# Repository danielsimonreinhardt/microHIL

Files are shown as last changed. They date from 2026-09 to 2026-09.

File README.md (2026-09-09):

# microHIL

A small, self-built hardware-in-the-loop box: switchable relays, digital and
analog I/O, two current-monitored 12 V supply outputs and a CAN interface —
all driven from a PC over a single USB cable.

microHIL is built around an **STM32F446RET** (LQFP64) on a custom PCB. It
enumerates as a USB composite device with **two virtual COM ports**: one
carries a plain ASCII command protocol for the I/O, the other exposes CAN1 as
a standard SLCAN adapter. Both can be used at the same time.

> **Status:** working prototype, in active use on the bench. The firmware,
> the command protocol and the Python host library are stable and verified
> against real hardware; the PCB is at revision v0.1 and has a few documented
> quirks that needed rework (see [`docs/hardware-notes.md`](docs/hardware-notes.md)).
> Project documentation under `docs/` is currently in German.

## Features

| Function | Channels | Notes |
|---|---|---|
| Relays | 4 | dry contacts |
| Digital outputs | 8 | `OUT1-8` |
| Digital inputs | 8 | 12 V level, comparator front end with selectable 5 V/12 V threshold |
| Analog inputs | 4 | calibrated, reported in mV (divider for up to ~13 V) |
| Analog outputs | 2 | DAC + buffer, calibrated, ~0…12.2 V |
| Switchable 12 V outputs | 2 | high-side switch with current sense (mA) and firmware current limiting |
| PWM outputs | 4 | 0…1000 ‰, configurable frequency 1 Hz…20 kHz (`PWMFREQ`, shared by all 4 channels, ceiling scope-verified), shares the output stage with `OUT1-4` (interlocked in firmware) |
| CAN | 1 (+1 reserved) | CAN1 as SLCAN USB adapter; CAN2 reserved for remote control |

Analog channels (`AIN1-4`, `AOUT1-2`, `CURR1-2`) are individually two-point
calibrated against reference instruments, so the protocol speaks physical
units (mV / mA) rather than raw ADC counts — see
[`docs/calibration.md`](docs/calibration.md).

The 12 V outputs are protected in firmware: a per-channel limit (`ILIM`,
default 1200 mA) and a combined 1500 mA budget for the shared polyfuse. A
tripped channel latches off until its request is explicitly withdrawn;
`PWR12FLT?` reports the cause.

## Repository layout

```
firmware/microHIL_fw/   STM32CubeMX + CMake project for the STM32F446RET
host/                   Python client library, test GUI, hardware-free checks
hardware/               KiCad 9 schematic, PCB and Gerbers (rev v0.1)
docs/                   Protocol reference, CAN/SLCAN reference, calibration,
                        hardware notes (German)
```

## USB interfaces

microHIL presents two CDC-ACM functions under the same VID:PID `0483:5740`
(ST's factory VCP IDs — no own USB vendor ID). They are told apart by
interface number, which `host/microhil.py` does automatically:

| Interface | Windows | Linux | Content |
|---|---|---|---|
| 0 | `…&MI_00` | `…-if00` | HIL command protocol — [`docs/protocol.md`](docs/protocol.md) |
| 2 | `…&MI_02` | `…-if02` | CAN1 as SLCAN — [`docs/can-usb.md`](docs/can-usb.md) |

Two ports rather than one multiplexed port, because a COM port can only be
opened once on Windows: this way the test GUI and a CAN tool can run
side by side.

## Command protocol

Line-based ASCII, uppercase, `\n`-terminated requests, `\r\n`-terminated
replies — a plain `readline()` is enough. Values are always integers in
mV/mA.

```
*IDN?                 -> microHIL,fw=0.1.0,SN=2065386A5631
RELAY 1 1             -> OK
IN?                   -> 10110001        (IN1 first)
AIN? 2                -> 3300            (mV, calibrated)
PWR12 1 1             -> OK
CURR? 1               -> 536             (mA)
PWM 1 500             -> OK              (‰ duty cycle)
```

Errors are exactly `ERR ARGS`, `ERR RANGE` or `ERR UNKNOWN`. The full
reference, including the range-checking rules and the board serial number in
`*IDN?`, is in [`docs/protocol.md`](docs/protocol.md).

CAN1 speaks the SLCAN/Lawicel dialect (CAN232-compatible), so it works with
`python-can` (`interface="slcan"`) and, on Linux, as a regular SocketCAN
interface via `slcand`. Two extensions beyond CAN232: `B<bit/s>` for exact
non-standard bitrates and `Y` for a loopback self-test without a bus. See
[`docs/can-usb.md`](docs/can-usb.md).

## Getting started (host)

```bash
pip install -r host/requirements.txt
```

```python
from host.microhil import MicroHIL

with MicroHIL() as hil:          # finds the right COM port by itself
    print(hil.idn())
    hil.set_relay(1, True)
    print(hil.get_ain_mv(2), "mV")
    hil.set_pwr12(1, True)
    print(hil.get_curr_ma(1), "mA")
```

A PySide6 test GUI that exercises every function manually, with a CAN trace
tab, comes with it:

```bash
python host/gui.py
```

Two checks in `host/tests/` run without any hardware attached — they verify
the CAN bit timing against the bxCAN register limits and the SLCAN wire
format in both directions against the real `python-can` driver:

```bash
python host/tests/check_bit_timing.py
python host/tests/check_slcan_wire.py
```

## Building the firmware

Needs the `arm-none-eabi` GCC toolchain, CMake ≥ 3.22 and Ninja. The project
was generated with STM32CubeMX and is set up for the STM32Cube extension for
VS Code, but builds fine from the command line:

```bash
cd firmware/microHIL_fw
cmake --preset Debug
cmake --build --preset Debug
```

Flashing is over SWD with an ST-Link V2, e.g.:

```bash
STM32_Programmer_CLI -c port=SWD -w build/Debug/microHIL_fw.elf -rst
```

With GCC 10.3.1 (the version bundled with STM32CubeIDE 1.10.1, confirmed
working end-to-end 2026-09-09), the linker fails on all three `.ld` files
with `non constant or forward reference address expression for section
.ARM.extab` — the `(READONLY)` section attribute on `.ARM.extab`/`.ARM`/
`.preinit_array`/`.init_array`/`.fini_array` needs GCC 11+ (each occurrence
says so in its own comment). Remove `(READONLY)` from those five section
headers in `STM32F446xx_FLASH.ld` (used by the CMake build) and, for
STM32CubeIDE's own Eclipse build, `STM32F446RETX_FLASH.ld`/`_RAM.ld` too, if
building with GCC 10. A GCC 11+ toolchain doesn't need this.

If you regenerate from `microHIL_fw.ioc`, note that the CAN bit timing is
computed at runtime in `Core/Src/slcan.c` (deliberately not stored in CubeMX)
and that the CDC composite build needs ST's `CompositeBuilder`, which CubeMX
does not emit for the F4 series — it is vendored in
`Middlewares/ST/STM32_USB_Device_Library/Class/CompositeBuilder/`.

## Hardware

- MCU: STM32F446RET, LQFP64, 8 MHz crystal, HSE/PLL clock tree
- Debug: SWD (ST-Link V2)
- CAN1: PB8/PB9, transceiver and 120 Ω termination populated
- CAN2: PB5/PB6, not in service yet (see Roadmap)
- KiCad sources, PCB and Gerbers for rev v0.1 are in [`hardware/`](hardware/)

Board revision v0.1 has known issues that required rework — most notably VBUS
routed straight onto the supply rail, and missing pulldowns on the digital
input comparator stages. All of them are documented, with measurements and
the fixes applied, in [`docs/hardware-notes.md`](docs/hardware-notes.md).
Read that file before building a board from these files.

## Roadmap

- **CAN2 as a remote-control interface.** Drive microHIL from a supervising
  ECU or test bench with the same functions as the USB command protocol.
  Frame layout, addressing and bitrate are still to be defined; the bxCAN
  filter bank split needed for CAN2 to receive at all is already in place
  (`SlaveStartFilterBank = 14` in `Core/Src/can_if.c`).
- **CAN1 against a second real bus node**, plus a scope measurement of the
  actual bit rate.

## License

MIT — see [LICENSE](LICENSE).

Vendored third-party code keeps its own license: the STM32 HAL drivers, CMSIS
and the ST USB device library under `firmware/microHIL_fw/Drivers/` and
`firmware/microHIL_fw/Middlewares/` are © STMicroelectronics / Arm and
licensed under their respective terms (see the `LICENSE.txt` files in those
directories).

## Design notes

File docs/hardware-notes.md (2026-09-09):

# Hardware-Notizen

## Bekannte Probleme (aktuelle Platinen-Revision)

### VBUS direkt auf Versorgungsschiene (kein Regler dazwischen)

**Symptom:** Wenn Board gleichzeitig über ST-Link (3.3V) und über den
eigenen USB-Anschluss versorgt wird, steigt die gemessene VDD auf ca.
4.1V statt 3.3V. SWD-Zugriff (ST-Link) schlägt in diesem Zustand fehl
(`Unable to get core ID`).

**Ursache:** Der VBUS-Pin des USB-Steckers ist direkt mit der
Versorgungsschiene verbunden, statt über den Spannungsregler zu laufen.
Bei gleichzeitiger Fremdversorgung (z. B. durch ST-Link) kollidieren die
5V von VBUS mit der 3.3V-Versorgung auf derselben Schiene.

**Workaround (aktuell):** VBUS-Verbindung provisorisch aufgetrennt.

**Für nächste Revision:** VBUS über den Spannungsregler führen (bzw. nur
zur USB-VBUS-Erkennung an einen dedizierten, hochohmig entkoppelten Pin
legen), nicht direkt auf die Versorgungsschiene.

### Digital-Eingänge: Ursprüngliche "immer High"-Diagnose war falsch — Pullup ist Teil der Komparator-Stufe, nicht bloß Anti-Floating

**Ursprüngliches Symptom (2026-09-06):** Wenn an einem Digital-Eingang nichts
angeschlossen ist, wird er immer als High erkannt.

**Ursprüngliche (falsche) Diagnose:** Externer 10-kΩ-Pullup + LPF vor dem
GPIO-Pin, der einen internen STM32-Pulldown (~40 kΩ) überstimmt — wurde als
reines Anti-Floating-Problem am GPIO behandelt und der externe Pullup
entsprechend auf allen 8 Kanälen entfernt, dafür intern `GPIO_PULLDOWN`
aktiviert (`main.c`, `microHIL_fw.ioc`).

**Tatsächliche Schaltung (2026-09-08, per Schaltplan-Trace in
`ELECTRICS/micro_HIL_v0.1/Input-Driver.kicad_sch` verifiziert — Pfad siehe
[[microhil-kicad-schematic-path]]):** Jeder DIN-Kanal hat einen eigenen
Komparator (**LM397**, SOT-23-5, laut Bauteilbeschreibung explizit
"Voltage Comparator with **Open-Collector Output**"), keine simple
GPIO-Beschaltung:

```
INPUTn (12V) → Q3x (Verpolschutz, BSS84) → D1x/D2x (8,2V-Zener-Clamp, BZT52B8V2) → IN− (Pin1, LM397)
REF-Teiler (10k/15k, aus gemeinsamem REF-Netz)                                  → IN+ (Pin3, LM397)
                                                                                     │
                                                                            OUT (Pin4, Open-Collector)
                                                                                     │
                              10k-Pullup nach +3,3V ───────────────────────────────┤
                                                                                     │
                                                                        Testpoint → 3,3k Serie-R → DINn → MCU
```

Für alle 8 Kanäle nachgewiesen (Pin-4-Ausgang des jeweiligen LM397 liegt per
Wire-Trace direkt am zugehörigen 10-kΩ-Widerstand nach +3,3V): U21-U24/U25-U28
(Komparatoren) mit R95/R96/R97/R98 bzw. R115/R116/R117/R118 (Pullups, alle
10k) — genau diese acht Widerstände sind es, die der Fix vom 2026-09-08
entfernt hat.

**Root Cause (korrigiert):** Ein Open-Collector-Ausgang kann **nur** nach GND
ziehen (Transistor leitend) oder floaten (Transistor gesperrt) — er kann
niemals aktiv High treiben. Der "externe Pullup" war kein optionales
Anti-Floating-Element am GPIO, sondern die einzige Möglichkeit für diese
Stufe, überhaupt einen High-Pegel zu erzeugen. Ohne ihn zieht der interne
~40-kΩ-Pulldown den Pin permanent Richtung Low — unabhängig vom
Komparator-Zustand und unabhängig von der tatsächlichen Eingangsspannung.

**Damit erklärt sich auch das neue Symptom (2026-09-08, User-Beobachtung):**
Am MCU-Pin kommt nie ein High-Pegel an, obwohl sicher 12V an `INPUTn` anliegt
— exakt das erwartete Verhalten eines Open-Collector-Ausgangs ohne Pullup.

**Komparator-Polarität und zweiter Root Cause (geklärt, 2026-09-08, per
`kicad-cli sch export netlist` gegenverifiziert — manuelles
Koordinaten-Tracing im Schaltplan war an dieser Stelle zunächst fehlerhaft
und hat IN+/IN− vertauscht):**

```
Netz "Net-(D18-K)": D18 Pin1(K), Q32 Pin2, U21 Pin3  → INPUTn liegt an IN+ (nicht-invertierend)
Netz "Net-(U21--)": R87 Pin2, R88 Pin1, U21 Pin1     → REF-Teiler liegt an IN− (invertierend)
```

Damit ist die Schaltung ein **Standard-Komparator mit korrekter Polarität**:
Ausgang High (über den Open-Collector-Pullup), wenn `INPUTn` (IN+) über der
REF-Schwelle (IN−) liegt — also **High = 12V erkannt, Low = darunter**. Die
rohe, unveränderte GPIO-Ebene hatte diese Polarität schon immer korrekt; die
Firmware-Invertierung vom 08.09. (weiter oben) beruhte auf der fehlerhaften
Leitungsverfolgung und wurde noch am selben Tag zurückgenommen
(`Core/Src/protocol.c`, `cmd_in_query()` wieder reiner
`HAL_GPIO_ReadPin(...)`-Durchreich-Wert).

**Der tatsächliche zweite Fehler:** Am `IN+`-Netz hängt laut Netzliste
**kein einziger Widerstand nach GND** — nur D18 (Zener-Clamp), Q32
(Verpolschutz) und der Komparator-Eingang selbst. Ein unbeschalteter
`INPUTn` lässt IN+ dadurch komplett hochohmig floaten; es treibt
reproduzierbar über die REF-Schwelle (auch bei REF=12V, Schwelle ~7,2V) und
ist damit von echten 12V nicht zu unterscheiden — exakt das ursprüngliche
"immer High"-Symptom, nur jetzt mit echter Ursache statt der Pullup/Pulldown-
Fehldiagnose vom 06.09.

**Fix, auf Hardware verifiziert (2026-09-08):** Bodge-Pulldown-Widerstand von
IN+ (D18-Kathode-Knoten) nach GND, freitragend nachgerüstet auf Kanal 1 und
2. Test-Ergebnis nach dem Rework:

| Zustand | `IN? n` (Kanal 1+2) |
|---|---|
| offen | `0` |
| 12V | `1` |

Beide Zustände jetzt sauber unterscheidbar. `GPIO_PULLDOWN`→`GPIO_NOPULL`-
Rückstellung (Firmware/`.ioc`) ist bereits umgesetzt und mitgeflasht.

**Alle 8 Kanäle nachgerüstet und einzeln verifiziert (2026-09-08):** Bodge-
Pulldown IN+→GND auf Kanal 3-8 ergänzt (Kanal 1-2 s. o.). Danach jeden Kanal
einzeln mit 12V beschaltet (alle anderen offen) und `IN?` geprüft — kein
Kanal zeigt Überkopplung auf einen Nachbarn:

| Kanal | offen | 12V |
|---|---|---|
| IN1-IN8 | `0` | `1` |

Alle 8 Kanäle unterscheiden jetzt korrekt "offen" von "12V anliegend". Damit
ist der DIN-Fehlerkomplex (Pullup fehlte → Pulldown fehlte → Firmware-
Polarität kurzzeitig falsch invertiert) vollständig abgeschlossen.

**Zusatzverifikation der REF-Schwelle (2026-09-08, Kanal 1+2):** Mit 5V-Signal
an `INPUTn` sauber schwellenabhängig: REF=12V (Schwelle ~7,2V) → `0`
(5V < Schwelle), REF=5V (Schwelle ~3V) → `1` (5V > Schwelle). Bestätigt, dass
der Komparator nicht nur "12V vs. GND", sondern die tatsächliche Schwelle
korrekt auswertet.

### CAN1_RX (PB8) liegt offen — Bus kommt nicht hoch

**Symptom:** Der SLCAN-Layer selbst funktioniert (Protokoll-Parser, `V`/`N`/`F`
antworten korrekt), aber `O`, `L` und auch `Y` (Loopback-Selbsttest, kein Bus
nötig) scheitern alle mit `\a` (BEL). Per Debugger bestätigt: `HAL_CAN_Start()`
läuft in den 10-ms-Timeout (`HAL_CAN_ERROR_TIMEOUT`), weil `INAK` nie löscht —
der bxCAN-Kern wartet beim Verlassen des Init-Modus auf 11 aufeinanderfolgende
rezessive Bits auf der physischen RX-Leitung, **auch im Loopback-Modus**
(dieser Sync-Mechanismus hängt am echten Pin, nicht am internen
Loopback-Pfad — ein bekanntes bxCAN-Verhalten).

**Ursache (per Debugger verifiziert, nicht nur vermutet):** PB8 (CAN1_RX)
liest im Ruhezustand konstant LOW (dominant) statt HIGH (rezessiv). Test: mit
intern zugeschaltetem Pull-Up (`GPIOB->PUPDR`) springt der Pin sofort auf
HIGH, mit Pull-Down oder ganz ohne Pull bleibt er LOW — ein aktiv angesteuerter
Transceiver-Ausgang (Innenwiderstand ~10-100 Ω) würde einen schwachen internen
Pull (~40 kΩ) mühelos überstimmen. Der Pin ist also **nicht aktiv getrieben,
sondern floatet** — es zieht nichts Definiertes dagegen. `CAN1_SILENT` (PB7)
umzuschalten (LOW↔HIGH) hat dabei **keinerlei Auswirkung** auf PB8, was eine
einfache Polaritätsverwechslung beim Silent-Pin als Ursache ausschließt.

**Root Cause (gefunden):** Defekter CAN-Transceiver. Direktes Nachmessen am
RXD-Pin des Transceiver-ICs zeigte ca. 0,2 V statt der erwarteten ~5 V
(rezessiver Ruhepegel) — der Transceiver selbst hat die Leitung nicht
korrekt auf HIGH getrieben, unabhängig von MCU-Seite oder Verdrahtung.
Zwei Zwischenschritte haben das nicht behoben und sind damit als Ursache
ausgeschlossen: kalte Lötstellen (nachgelötet, kein Effekt) und
Silent-Pin-Polarität (siehe oben, PB7-Umschalten ohne Wirkung auf PB8).

**Fix:** Transceiver getauscht. Nach dem Tausch: `O`, `L` und `Y` öffnen
alle sauber (`OK`, keine Statusflags), Loopback-Frames (Standard, Extended,
beide RTR-Varianten, 1 Mbit/s) laufen fehlerfrei durch, Parallelbetrieb mit
dem HIL-Port über 5 Runden ohne Aussetzer. Damit ist CAN1 als CAN-USB-
Interface funktionsfähig.

**Noch offen:** Test gegen einen echten zweiten Busteilnehmer (bisher nur
Loopback/Selbsttest verifiziert) und Bitraten-Messung am Oszilloskop gegen
die berechneten Werte aus `docs/can-usb.md`.

### PWR12-1 liefert 0V trotz `PWR12 1 1` (Firmware meldet "ein")

**Symptom:** `PWR12 1 1` setzt den GPIO (PC4/`DOUT_12V_SUPPLY1`), `PWR12? 1`
liest korrekt "1" zurück (reine GPIO-Rücklesung, keine echte
Ausgangs-Rückmeldung) — am `12V_OUT_1`-Ausgang liegen aber trotz angeschlossener
externer 12V-Einspeisung ~0V an.

**Schaltung (`ELECTRICS/micro_HIL_v0.1`, Sheet `Output-Driver.kicad_sch`,
"12V SWITCHED SUPPLY 1"):** Externe 12V → **Q22** (PMT200EPEX, PMOS,
Verpolschutz) → Zwischenknoten → **Q28** (PMT200EPEX, PMOS, eigentlicher
Schalter) → **R73** (50 mΩ Shunt) → **F13** (Polyfuse, siehe Abschnitt
"Maximal zulässiger Strom" unten) → `12V_OUT_1`. Beide PMOS-Gates werden über
**Q26** (2N7002 NMOS) vom GPIO PC4 (`DOUT_12V_SUPPLY1`) gegen GND gezogen, um
sie durchzuschalten. PMT200EPEX-Gehäuse: **SOT223** (SC-73, 4-Pin mit
Kühlfläche), nicht SOT-23 wie zunächst notiert.

**Diagnose (2026-09-06, per Multimeter):**
- Zwischenknoten Q22/Q28: 0V, obwohl Pin2 (Drain) von Q22 die vollen 12V der
  Einspeisung führt — der Spannungsabfall passiert also bereits an Q22.
- Q22 einzeln gemessen: Pin1 (Gate) 0V, Pin2 (Drain) 12V, Pin3 (Source) 0V.
- Dioden-Test an Q22 (Drain-Source, Versorgung abgesteckt): 1,6V
  Durchlassspannung in einer Richtung, `OL` in der anderen.
- Vergleich mit baugleichen PMT200EPEX auf derselben Platine (z. B. Q28):
  dort nur ~0,568V Durchlassspannung, `OL` in Sperrrichtung — normales
  Verhalten einer intakten Body-Diode.

**Root Cause:** Q22 hat eine defekte Body-Diode (deutlich erhöhte
Durchlassspannung ggü. baugleichen, funktionierenden MOSFETs auf derselben
Platine) und blockiert dadurch den kompletten Strompfad, unabhängig von der
Gate-Ansteuerung über Q26/PC4. Vermutlich Vorschaden (Überstrom/ESD), keine
Fehlbestückung (Bauteil ist verlötet, sieht optisch unauffällig aus).

**PWR12-2 geprüft (2026-09-06):** liefert sauber 12V, Kanal 2 (Q23/Q29) ist
nicht betroffen — der Defekt ist auf Q22/Kanal 1 begrenzt.

**Fix (2026-09-08):** Q22 getauscht. Nach dem Tausch: unbelastet 12V (korrekt),
aber unter Last (0,3A) brach die Ausgangsspannung auf 8,5V ein (~3,3V Abfall
bei 0,3A ⇒ ~11Ω effektiver Serienwiderstand — bei intaktem PMOS+Shunt sollte
das nur ~60mV/~200mΩ sein). Bisektion ergab: am Zwischenknoten Q22/Q28 lagen
unter Last weiterhin 11,9V an (Q22 also gesund), der Abfall passierte also
zwischen dort und `12V_OUT_1` — **Q28 war ebenfalls defekt** (gleicher
Bauteiltyp/vermutlich gleiches Los wie Q22). Nach zusätzlichem Tausch von
Q28: unbelastet 12V, bei 0,3A Last nur noch 11,8V (~0,2V Abfall, normaler
Bereich). Beide MOSFETs (Q22 und Q28) mussten getauscht werden, nicht nur
Q22.

### CURR1/CURR2 liefern nicht-monotone/falsche Rohwerte bei realem Laststrom

**Symptom:** `CURRRAW? <1-2>` sollte laut Schaltungsauslegung ca. 1 mV
Rohwert pro 1 mA Laststrom liefern (INA240A1D, Gain 20 V/V, 50 mΩ Shunt
R73/R74, siehe `docs/calibration.md`). Gemessen an CURR2 (2026-09-06,
PWR12-2 bestätigt korrekt auf 12V, Laststrom mit Amperemeter in Reihe
verifiziert):

| Laststrom (Amperemeter) | `CURRRAW? 2` |
|---|---|
| 200 mA  | 181 |
| 1000 mA | 264 |
| 2000 mA | ~221 (220-224, stabil) |

Nicht nur stark nichtlinear (1000mA→264 vs. 2000mA→~221 wäre bei linearer
Kennlinie unmöglich), sondern **nicht-monoton**: der Rohwert bei 1A ist höher
als bei 2A.

**Schaltung:** `12V_OUT_<n>` → Shunt R73/R74 (50 mΩ) → **U18**/**U19**
(INA240A1D, SOIC-8, Gain 20 V/V, REF1/REF2 auf GND) → `AIN_12V_OUT<n>_CURR`
zum ADC.

**Root Cause (gefunden, 2026-09-06):** **U18 UND U19 sind beide nicht
bestückt** — per Sichtprüfung bestätigt, keine defekten Bauteile. Der
ADC-Eingang liegt dadurch unbeschaltet/floatend und pickt Störsignale auf,
die mit dem Laststrom der nahen Schaltung korrelieren, aber keinen echten
Zusammenhang mit dem tatsächlichen Strom haben — daher die willkürlichen,
nicht-monotonen Werte. Unvollständige Erstbestückung, kein Schaltungs- oder
Firmwarefehler.

**Fix (2026-09-08):** U18 und U19 bestückt. Unbelastet danach beide sauber
bei ~0 (CURR1: 4, CURR2: 0, stabil über mehrere Abfragen) statt der vorher
willkürlichen ~180-260er-Rohwerte. Unter realer Last ebenfalls plausibel
(z. B. CURR1 bei 300mA gemessenem Laststrom → Rohwert 301, siehe
`docs/calibration.md` für die vollständige Kalibrierung).

### Maximal zulässiger Dauerstrom PWR12/CURR (Sicherungen, nicht die MOSFETs)

Die im Schaltplan angegebene Vollausschlag-Formel für CURR
(`Vout = I·50mΩ·20 = 2,5V @ 2,5A`) beschreibt nur die Verstärker-Auslegung,
NICHT den durch die Hardware tatsächlich zulässigen Dauerstrom — der ist
niedriger:

- **F1** (`Input-Output.kicad_sch`, "12V EXTERNAL INPUT PROTECTION"): liegt
  VOR dem Kanal-Split auf dem gemeinsamen `+12V`-Netz, begrenzt also die
  **Summe aus PWR12-1 und PWR12-2 gemeinsam**.
- **F13**/**F14**: je Kanal, nach dem Shunt, kurz vor `12V_OUT_1`/`12V_OUT_2`.
- Alle drei vom Typ **MINISMDC150F/24-2** (Littelfuse PolySwitch PPTC):
  Ihold = 1,5A, Itrip = 3A @ 24V, Trip-Zeit bei 3A ≈ 1,5s.
- Die beiden PMOS je Kanal (PMT200EPEX, SOT223, Rds(on) 130-167mΩ,
  ID(cont)=2,4A@25°C) sind dabei NICHT die begrenzende Komponente: bei 1,5A
  Dauerstrom fallen pro MOSFET nur ca. 1,5²×0,167Ω ≈ 0,38W an, deutlich unter
  dem Ptot-Budget (800mW ohne, 1,75W mit Kupder-Kühlfläche).

**Praktische Grenze:** **≤ 1,5A pro Kanal, wenn nur ein Kanal aktiv ist**;
laufen **beide Kanäle gleichzeitig**, muss ihre **Summe** unter 1,5A bleiben
(F1). Für Kalibrier-/Testpunkte empfiehlt sich mit Sicherheitsmarge ≤ 1,2A,
um F13/F14 nicht unnötig zu erwärmen oder auszulösen (Datenblätter:
[Digi-Key](https://www.digikey.com/en/products/detail/littelfuse-inc/MINISMDC150F-24-2/1113513),
[PMT200EPE](https://assets.nexperia.com/documents/data-sheet/PMT200EPE.pdf)).

### Obere Grenzfrequenz PWM1-4 (Ausgangsstufe, nicht der Timer)

**Messung (2026-09-09):** PWM1 (PC6) mit 50% Duty Cycle am Oszilloskop bei
1 kHz, 20 kHz und 100 kHz beobachtet (Signal an der Ausgangsstufe, PUSH-PULL
OUTPUT DRIVER mit BC807/BC817, siehe `hardware/Output-Driver.kicad_sch`):

- **1 kHz:** Flanken praktisch senkrecht (vernachlässigbarer Anteil der
  1-ms-Periode).
- **20 kHz:** Flanken noch deutlich steiler als die 50-µs-Periode, sauber
  nutzbares Signal.
- **100 kHz:** Flanken nehmen einen spürbaren Anteil der 10-µs-Periode ein
  (sichtbar verschliffener Übergang statt scharfer Kante) — die Endstufe
  stößt hier an ihre Schaltgeschwindigkeit.

**Bei allen drei Frequenzen zusätzlich beobachtet:** Der High-Pegel ist
sichtbar schmaler als der Low-Pegel, obwohl `PWM?` intern korrekt ~500‰
zurückliefert — die Verzerrung entsteht also in der analogen Endstufe, nicht
in der Duty-Cycle-Berechnung der Firmware. Da die Asymmetrie **schon bei
1 kHz** in gleicher Stärke vorliegt, ist sie **nicht frequenzabhängig**,
sondern vermutlich eine systematische Eigenschaft der Push-Pull-Stufe
(unterschiedliche Ausschalt-/Speicherzeiten zwischen dem PNP BC807 und dem
NPN BC817). Nicht weiter untersucht — für den Anwendungsfall (Schalten,
keine analoge Signaltreue gefordert) nicht relevant, aber falls ein exaktes
Tastverhältnis gebraucht wird, im Hinterkopf behalten.

**Root Cause:** keine explizite Ursache ermittelt (kein Bauteildefekt, keine
Reparatur nötig) — es handelt sich um eine gemessene Charakteristik der
Endstufe, keinen Fehler.

**Konsequenz:** `PWMFREQ` in der Firmware (`Core/Src/protocol.c`) hart auf
`1..20000` Hz gekappt statt des zuvor generischen 1-MHz-Werts, siehe
`docs/protocol.md`, Abschnitt "PWM-Frequenz".

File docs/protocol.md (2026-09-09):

# microHIL-Kommandoprotokoll (USB-CDC)

ASCII-Zeilenprotokoll. **Anfragen** sind `\n`-terminiert (`\r\n` wird
ebenfalls akzeptiert), 115200 Baud (wird vom virtuellen COM-Port ignoriert,
aber pyserial verlangt einen Wert). **Antworten** enden immer mit `\r\n` —
auch `OK` und `ERR ...` — ein simples `readline()` reicht also zum Auslesen.
Werte sind immer Ganzzahlen in mV/mA, nie Fließkomma.

Kommandos sind **case-sensitiv, nur Großschreibung** (`RELAY`, nicht
`relay`), Verb und Argumente durch Leerzeichen oder Tab getrennt
(`strtok(line, " \t")` — mehrere Trenner hintereinander sind unproblematisch).
Eine **leere Zeile erzeugt keine Antwort** (weder `OK` noch `ERR`) — ein
Treiber, der eine Leerzeile schickt, würde sonst in den Timeout laufen statt
einen Fehler zu sehen.

**USB-Identifikation:** VID:PID `0483:5740` (ST-Werks-VCP-IDs, kein eigenes
USB-Zertifikat). microHIL meldet zwei virtuelle COM-Ports mit dieser
VID:PID. Dieses Protokoll liegt auf dem **ersten** (Interface 0, Windows
`MI_00`, Linux `-if00`); auf dem zweiten liegt CAN1 als SLCAN-Interface,
siehe [can-usb.md](can-usb.md). Den richtigen Port findet `host/microhil.py`
selbst (`find_port()`) — die Interface-Nummer ist bei zwei gleichzeitig
sichtbaren Ports mit identischer VID:PID das einzig verlässliche
Unterscheidungsmerkmal, siehe dort für die Details je Plattform.

| Befehl | Beispiel | Antwort |
|---|---|---|
| `*IDN?` | `*IDN?` | `microHIL,fw=0.1.0,SN=2065386A5631` |
| `RELAY <1-4> <0\|1>` | `RELAY 1 1` | `OK` |
| `RELAY? <1-4>` | `RELAY? 1` | `1` |
| `OUT <1-8> <0\|1>` | `OUT 3 0` | `OK` |
| `OUT? <1-8>` | `OUT? 3` | `0` |
| `IN? <1-8>` | `IN? 5` | `1` |
| `IN?` (ohne Nr.) | `IN?` | `10110001` (IN1 zuerst) |
| `AOUT <1-2> <mV>` | `AOUT 1 1650` | `OK` |
| `AOUTRAW <1-2> <mV>` | `AOUTRAW 1 1650` | `OK` |
| `AIN? <1-4>` | `AIN? 2` | `3300` |
| `AINRAW? <1-4>` | `AINRAW? 2` | `818` |
| `PWR12 <1-2> <0\|1>` | `PWR12 1 1` | `OK` |
| `PWR12? <1-2>` | `PWR12? 1` | `1` |
| `PWR12FLT? <1-2>` | `PWR12FLT? 1` | `1` |
| `ILIM <1-2> <mA>` | `ILIM 1 1000` | `OK` |
| `ILIM? <1-2>` | `ILIM? 1` | `1000` |
| `CURR? <1-2>` | `CURR? 1` | `536` |
| `CURRRAW? <1-2>` | `CURRRAW? 1` | `536` |
| `PWM <1-4> <0-1000>` | `PWM 1 500` | `OK` |
| `PWM? <1-4>` | `PWM? 1` | `500` |
| `PWMFREQ <Hz>` | `PWMFREQ 500` | `OK` |
| `PWMFREQ?` | `PWMFREQ?` | `500` |

`*IDN?`s `SN=`-Feld ist aus der 96-bit STM32-UID abgeleitet und identisch mit
der USB-Seriennummer (unter Windows als `SER=...` in der `hwid` sichtbar,
siehe `serial.tools.list_ports`) — eindeutig je physischem Board, geeignet um
ein bestimmtes Exemplar wiederzuerkennen (z. B. um bekannte Hardware-Defekte
je Board auszublenden, siehe `docs/hardware-notes.md`). `host/microhil.py`
stellt das über `MicroHIL.get_serial()` bereit.

`IN?`/`IN? <n>`: `1` bedeutet 12V liegen am Eingang an, `0` bedeutet kein
Signal/offen. Alle 8 Kanäle verhalten sich so — der Pulldown am
Komparator-Eingang, ohne den ein offener Eingang fälschlich `1` lieferte, ist
auf allen Kanälen nachgerüstet und einzeln verifiziert (siehe
`docs/hardware-notes.md`). Ausgewertet wird nicht 12V-vs-GND binär, sondern
die eingestellte REF-Schwelle (REF=12V: ca. 7,2V, REF=5V: ca. 3V).

`AIN?`/`CURR?` liefern kalibrierte physikalische Werte (mV bzw. mA), `AOUT`
nimmt die gewuenschte physikalische Ausgangsspannung entgegen - siehe
[calibration.md](calibration.md) für die Kalibrierkonstanten und die
Messprozedur. `AINRAW?`/`CURRRAW?`/`AOUTRAW` sprechen stattdessen direkt den
unkalibrierten ADC-/DAC-Wert an (raw*3300/4095 bzw. DAC-Sollwert 0..3300 mV,
ohne Anwendung der Kalibrierkonstanten) - fuer die Kalibrierprozedur selbst
und zu Diagnosezwecken, im Normalbetrieb nicht benoetigt.

`PWM`-Duty-Cycle in Promille (0 = aus, 1000 = 100%).

Bei ungültigen/unbekannten Kommandos: `ERR <Grund>`. Es gibt genau drei
Gründe, keine weiteren:

| Grund | Bedeutung |
|---|---|
| `ERR ARGS` | Argument fehlt (z. B. `RELAY 1` ohne Zustand) |
| `ERR RANGE` | **Kanal-/Indexargument** außerhalb des gültigen Bereichs (z. B. `RELAY 5 1`) |
| `ERR UNKNOWN` | Kommando-Verb nicht erkannt |

## Wertebereiche: Index vs. Nutzwert

Wichtige Asymmetrie, die sich nicht aus der Tabelle oben ableiten lässt:
**nur das Kanal-/Indexargument wird geprüft und liefert `ERR RANGE`.** Das
eigentliche Nutzwertargument (mV bei `AOUT`, Promille bei `PWM`) wird **ohne
Fehlermeldung auf den gültigen Bereich geklemmt**, nicht abgelehnt:

- `AOUT <1-2> <mV>`: mV ist die gewünschte physikalische Ausgangsspannung und
  wird auf den kalibrierten Ausgangsbereich geklemmt (nominal ca. `0..12210`
  mV, siehe `cal_aout` in `Core/Src/calibration.c` bzw.
  [calibration.md](calibration.md) — die genauen Grenzen ändern sich mit der
  Kalibrierung). `AOUT 1 99999` antwortet `OK`, setzt aber effektiv den
  Maximalwert — der Aufrufer erfährt aus der Antwort nicht, dass der Wert
  verändert wurde. `AOUTRAW <1-2> <mV>` (unkalibrierter DAC-Sollwert) klemmt
  stattdessen weiterhin auf `0..3300`.
- `PWM <1-4> <permille>`: Promille wird auf `0..1000` geklemmt. `PWM 1 -5`
  antwortet `OK` und setzt effektiv 0.
- `PWMFREQ <Hz>`: wird auf `1..20000` geklemmt. Kein Kanal-/Indexargument
  (gilt fuer alle 4 PWM-Kanaele gemeinsam, ein Timer), daher kann `PWMFREQ`
  nur `ERR ARGS` liefern, nie `ERR RANGE`.

Für einen Treiber heißt das: `OK` bei `AOUT`/`PWM` bestätigt nur, dass der
Kanalindex gültig war — **nicht**, dass der genaue angeforderte Wert übernommen
wurde. Wer das prüfen will, muss den Wert per `AOUT?`/`PWM?`
zurücklesen (Anmerkung: `AOUT?` existiert nicht, nur `PWM?`).

`RELAY`/`OUT`/`PWR12` erwarten `0`/`1`, akzeptieren aber jeden Ganzzahlwert
(`atoi`) — jeder Wert ungleich `0` wird als `1` (ein) gewertet, es gibt keine
eigene Prüfung auf exakt `0`/`1`.

## Verriegelung PWM1-4 / OUT1-4

PC6-PC9 (PWM1-4, TIM3) und OUT1-4 (PA10/PA15/PC10/PC11) treiben laut
Schaltplan dieselbe Endstufe und dürfen nie gleichzeitig aktiv sein.
Firmwareseitig erzwungen: `OUT <n> 1` (n=1-4) stoppt PWM-Kanal n zwangsweise
(Duty auf 0), `PWM <n> <permille>` mit `permille > 0` schaltet OUT n
zwangsweise ab. Es gibt dafür keine eigene Fehlermeldung — die Verriegelung
wirkt still, der jeweils andere Kanal wird einfach deaktiviert.

## PWM-Frequenz

`PWMFREQ`/`PWMFREQ?` gelten fuer PWM1-4 gemeinsam (ein Timer, TIM3, fuer alle
4 Kanaele - siehe `pwm_tim_channel` in `Core/Src/protocol.c`). Ein einzelner
Kanal kann also nicht auf eine andere Frequenz als die uebrigen drei gesetzt
werden.

Intern wird Prescaler+Autoreload so gewaehlt, dass ARR fuer PSC=0 maximiert
wird (mehr Aufloesung fuer den Duty Cycle); ein Prescaler kommt nur fuer sehr
niedrige Frequenzen zum Einsatz. `PWMFREQ?` liefert die durch die
Ganzzahl-Teiler tatsaechlich erreichte Frequenz zurueck (kann leicht vom
angeforderten Wert abweichen, analog zur Promille-Klemmung bei `PWM`).
Ein laufender Duty Cycle (`PWM <n> <permille>`) bleibt beim Frequenzwechsel
prozentual erhalten - die Firmware rechnet die 4 Compare-Register auf das
neue ARR um.

Die Obergrenze von `20000` Hz ist per Oszilloskop verifiziert (2026-09-09,
siehe `docs/hardware-notes.md`): bei 100 kHz zeigt die nachgeschaltete
Endstufe (PUSH-PULL OUTPUT DRIVER, BC807/BC817, siehe
`hardware/Output-Driver.kicad_sch`) bereits deutlich verschliffene Flanken
(spuerbarer Anteil der Periode), bei 20 kHz sind sie noch sauber. Die
Firmware kappt `PWMFREQ` entsprechend hart auf `20000`, nicht nur informativ
in der Doku.

Untergrenze `1` Hz ist ein praktischer Wert, nicht das Timer-Minimum: mit
maximalem 16-Bit-Prescaler und -ARR liegt die theoretisch niedrigste
TIM3-Frequenz bei ca. 0,0168 Hz (Periode ~59,7 s).

## Strombegrenzung PWR12-1/2

Firmwareseitige Schutzfunktion (`Core/Src/protocol.c`, `pwr12_guard_poll()`),
unabhängig von den Polyfuses F1/F13/F14 (siehe `docs/hardware-notes.md`,
"Maximal zulässiger Dauerstrom") — diese sind weiterhin die letzte
Hardware-Absicherung, die Firmware soll aber im Normalbetrieb schon vorher
abschalten.

**Pro Kanal:** `ILIM <1-2> <mA>` setzt das Stromlimit für PWR12-1/2, Default
nach Reset ist **1200 mA**. Wird das Limit **ununterbrochen länger als
100 ms** überschritten (CURR1/2 werden dafür intern alle 2 ms gesampelt),
schaltet die Firmware den betroffenen Kanal ab, unabhängig von der zuletzt
per `PWR12` gesetzten Schaltanforderung. Kurze Einschaltstromspitzen unter
100 ms lösen die Verriegelung nicht aus.

**Gesamtbudget:** Der 12V-Eingang versorgt neben PWR12-1/2 auch die MCU,
deshalb gibt es zusätzlich eine von den Einzellimits unabhängige Prüfung:
überschreitet CURR1+CURR2 in Summe **1500 mA** (Ihold der gemeinsamen
Polyfuse F1, siehe `docs/hardware-notes.md`), schaltet die Firmware **beide**
Kanäle ab — mit einer kurzen **10-ms-Entprellung** (viel kürzer als die
100 ms pro Kanal, aber nicht "sofort" ohne jede Filterung: eine erste
Implementierung ganz ohne Entprellung löste auf Hardware bereits beim
Einschalten eines einzelnen, unbelasteten Kanals aus — ein Schaltstörimpuls
traf die eine ungefilterte 2-ms-ADC-Probe, siehe `CHANGELOG.md`).

**Verriegelung:** In beiden Fällen bleibt der Ausgang aus, auch wenn die
Schaltanforderung (`PWR12 <n> 1`) weiter ansteht — ein einfaches erneutes
`PWR12 <n> 1` schaltet NICHT wieder ein. Der betroffene Kanal muss zuerst
per `PWR12 <n> 0` zurückgenommen werden (das löscht seine eigene
Überstromverriegelung); die Gesamtbudget-Verriegelung erlischt erst, wenn
**beide** Kanäle zurückgenommen wurden. `PWR12? <n>` liest weiterhin nur den
tatsächlichen GPIO-Zustand (0, solange eine Verriegelung aktiv ist);
`PWR12FLT? <n>` liefert eine Bitmaske, warum ein Kanal trotz anstehender
Schaltanforderung aus ist: Bit0 = eigenes Überstromlimit ausgelöst, Bit1 =
Gesamtbudget ausgelöst (`0` = kein Fault).

`ILIM` klemmt negative Werte auf 0, prüft aber sonst nicht gegen die
Hardwaregrenzen (≤1,5A Dauerstrom pro Kanal laut Sicherung) — wer ein
höheres Limit setzt, verlässt sich allein auf die Polyfuses.

## Timing

Alle Kommandos außer `AIN?` und `CURR?` antworten praktisch sofort
(reine GPIO-/Register-Operationen). `AIN?` und `CURR?` lösen intern eine
Single-Conversion-ADC-Messung aus (`HAL_ADC_PollForConversion`, 10 ms
Timeout) — im Normalfall deutlich schneller, aber ein Treiber, der viele
Analogkanäle im Poll-Takt abfragt, sollte pro Aufruf mit bis zu ~10 ms
rechnen statt mit der sonst üblichen Sub-Millisekunden-Antwortzeit.

## Kalibrierung

`AIN?`, `AOUT` und `CURR?` rechnen über feste 2-Punkt-Kalibrierkonstanten
(`Core/Src/calibration.c`) zwischen dem naiven ADC-/DAC-Wert und dem
physikalischen Wert um. Bis zur echten Messung stehen dort nominelle,
aus dem Schaltplan abgeleitete Platzhalterwerte — siehe
[calibration.md](calibration.md) für Herleitung und Messprozedur.

## Implementierung

- Firmware: `Core/Src/protocol.c` — Ringpuffer wird in `CDC_Receive_FS`
  (USB_DEVICE/App/usbd_cdc_if.c) gefüllt, `Protocol_Poll()` läuft in der
  Main-Loop und wertet vollständige Zeilen aus.
- Host: `host/microhil.py` (Klasse `MicroHIL`, pyserial-basiert)

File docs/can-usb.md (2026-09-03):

# CAN1 als CAN-USB-Interface (SLCAN)

CAN1 des microHIL ist ein CAN-USB-Adapter im SLCAN-/Lawicel-Format
(CAN232-kompatibel). Damit funktioniert es ohne eigenen Treiber mit
`python-can` unter Windows und unter Linux über `slcand` als reguläres
SocketCAN-Interface.

CAN2 ist für die spätere Fernsteuerung des microHIL reserviert und hier
nicht angesprochen (siehe Roadmap im README).

## Zwei COM-Ports

microHIL meldet sich als USB-Composite-Device mit **zwei** CDC-ACM-Funktionen,
also zwei virtuellen COM-Ports:

| Interface | Windows | Linux | Inhalt |
|---|---|---|---|
| 0 | `...&MI_00` | `...-if00` | HIL-Kommandoprotokoll (`docs/protocol.md`) |
| 2 | `...&MI_02` | `...-if02` | CAN1, SLCAN |

Beide Ports haben dieselbe VID:PID `0483:5740`. Der Composite-Builder der
ST-USB-Library vergibt für beide CDC-Funktionen den Interface-String-Index 0,
deshalb heißen im Windows-Gerätemanager beide Ports gleich — auseinanderhalten
lassen sie sich nur über die Interface-Nummer. `host/microhil.py` macht das
automatisch (`find_ports()`, `find_can_port()`).

Der Sinn der Trennung: ein COM-Port lässt sich unter Windows nur einmal öffnen.
Mit zwei Ports laufen Test-GUI und CAN-Werkzeug gleichzeitig.

## Kommandos

Kommandos sind mit **CR** (`\r`) terminiert, nicht mit `\n` wie beim
HIL-Protokoll. Antwort ist `\r` (OK) bzw. `\a` (BEL, Fehler).

| Befehl | Bedeutung | Antwort |
|---|---|---|
| `Sn` | Bitrate wählen, `n` = 0-9 (Tabelle unten) | `\r` |
| `B<bit/s>` | **microHIL-Erweiterung:** exakte Bitrate dezimal, z. B. `B750000` | `\r` |
| `O` | Bus öffnen, Normalbetrieb | `\r` |
| `L` | Bus öffnen, Listen-Only (sendet nichts, auch kein ACK) | `\r` |
| `Y` | **microHIL-Erweiterung:** Loopback-Selbsttest ohne Bus | `\r` |
| `C` | Bus schließen | `\r` |
| `tiiildd…` | Standard-Frame (11 bit) senden | `z\r` |
| `Tiiiiiiiildd…` | Extended-Frame (29 bit) senden | `Z\r` |
| `riiil` | Standard-RTR senden | `z\r` |
| `Riiiiiiiil` | Extended-RTR senden | `Z\r` |
| `F` | Statusflags lesen (das Lesen löscht sie) | `Fxx\r` |
| `V` | Version | `V0100\r` |
| `N` | Seriennummer (4 Hex aus der MCU-UID) | `Nxxxx\r` |
| `Zn` | Zeitstempel aus (`Z0`) / ein (`Z1`) | `\r` |

Empfangene Frames kommen unaufgefordert im selben `t`/`T`/`r`/`R`-Format.
Bei `Z1` hängen 4 Hex-Ziffern Millisekunden an (Überlauf bei 60000 = `EA5F`).

Die Bitrate lässt sich nur bei **geschlossenem** Bus setzen. `O`/`L`/`Y` sind
idempotent (schließen intern vorher) — `python-can` schickt beim Verbinden
zweimal `O`.

### Statusflags (`F`)

| Bit | Bedeutung |
|---|---|
| 0 | RX-Ringpuffer voll (Frames verworfen) |
| 1 | TX-Mailboxen voll (Frame verworfen) |
| 2 | Error Warning |
| 3 | Data Overrun |
| 5 | Error Passive |
| 6 | Arbitration Lost |
| 7 | Bus Error |

## Bitraten

`Sn` folgt dem originalen Lawicel-CAN232.

| Befehl | Bitrate | Prescaler | BS1 | BS2 | SJW | tq/Bit | Sample Point |
|---|---|---|---|---|---|---|---|
| `S0` | 10 kbit/s | 180 | 16 | 3 | 1 | 20 | 85,0 % |
| `S1` | 20 kbit/s | 90 | 16 | 3 | 1 | 20 | 85,0 % |
| `S2` | 50 kbit/s | 36 | 16 | 3 | 1 | 20 | 85,0 % |
| `S3` | 100 kbit/s | 18 | 16 | 3 | 1 | 20 | 85,0 % |
| `S4` | 125 kbit/s | 16 | 15 | 2 | 1 | 18 | 88,9 % |
| `S5` | 250 kbit/s | 8 | 15 | 2 | 1 | 18 | 88,9 % |
| `S6` | 500 kbit/s | 4 | 15 | 2 | 1 | 18 | 88,9 % |
| `S7` | **800 kbit/s** | 3 | 10 | 4 | 1 | 15 | 73,3 % |
| `S8` | 1 Mbit/s | 2 | 13 | 4 | 1 | 18 | 77,8 % |
| `S9` | 83,333 kbit/s | 24 | 15 | 2 | 1 | 18 | 88,9 % |

Alle Nennbitraten werden bei PCLK1 = 36 MHz exakt getroffen. Die Werte stehen
nicht als Tabelle in der Firmware, sondern werden von `timing_for_bitrate()`
in `Core/Src/slcan.c` gesucht: feinste Auflösung, deren Sample Point nahe genug
am Ziel liegt (87,5 %, ab 800 kbit/s 75 %), bei höchstens 0,1 % Bitratenfehler.
Grenzen der bxCAN-Register: BS1 ≤ 16 tq, BS2 ≤ 8 tq, Prescaler ≤ 1024.

### Stolperstein: `S7`

`python-can` bildet **750 kbit/s** auf `S7` ab, das originale Lawicel-CAN232
(und damit microHIL) versteht unter `S7` aber **800 kbit/s**. Wer 750 kbit/s
braucht, setzt sie über das `B`-Kommando:

```
C
B750000
O
```

`host/microhil_can.py` macht genau das automatisch für alle Bitraten außerhalb
der eindeutigen Menge.

## Benutzung

### Windows / Python

```python
from microhil_can import open_can
import can

with open_can(500000) as bus:
    bus.send(can.Message(arbitration_id=0x7DF, is_extended_id=False,
                         data=[0x02, 0x01, 0x00]))
    print(bus.recv(1.0))
```

Als Sniffer:

```
python host/microhil_can.py 500000
```

Oder direkt mit python-can, wenn der Port bekannt ist:

```python
bus = can.Bus(interface="slcan", channel="COM8", bitrate=500000)
```

In der Test-GUI (`host/gui.py`) gibt es dafür den Reiter **CAN1** mit
Bitratenwahl, Listen-Only, Trace und Sendefeld. HIL-Reiter und CAN-Reiter
benutzen die beiden getrennten COM-Ports und funktionieren gleichzeitig.

### Linux / Raspberry Pi (SocketCAN)

```
slcand -o -s6 -t hw -S 115200 /dev/ttyACM1 can0
ip link set can0 up
candump can0
```

`-s6` = 500 kbit/s (siehe Tabelle). `/dev/ttyACM1` ist der Port mit
Interface 2 — verlässlich über `/dev/serial/by-id/*-if02` ansprechen, weil
sich die `ttyACM`-Nummern beim Anstecken verschieben können.

Damit steht `can0` allen SocketCAN-Werkzeugen zur Verfügung, unter anderem
`can-utils` und `uds-diag` — dort ist keine Anpassung nötig.

## Hardware

- CAN1: PB8 = RX, PB9 = TX, Transceiver bestückt, 120 Ω auf der Platine.
- `CAN1_SILENT` (PB7) wird auf LOW gehalten (Normalbetrieb). Listen-Only wird
  über den Silent-Modus des bxCAN abgebildet, nicht über den Transceiver.

## Implementierung

- `Core/Src/can_if.c` — bxCAN-Treiber: Bit-Timing, Accept-all-Filter,
  Interrupt-RX in einen 64-Frame-Ring, Fehlerflags, automatische
  Bus-Off-Erholung. Die Filterbänke sind aufgeteilt
  (`SlaveStartFilterBank = 14`), damit CAN2 später empfangen kann.
- `Core/Src/slcan.c` — Protokoll-Parser und -Serializer, gepufferte Ausgabe.
- `USB_DEVICE/App/usbd_cdc_if.c` — zweite CDC-Instanz (`..._fops_CAN`).
- `host/microhil_can.py`, `host/microhil.py` (`find_can_port()`).

### Hinweis zu CubeMX

Das Composite-Device ist von Hand eingerichtet, CubeMX generiert es für die
F4-Serie nicht. Nach einem Regenerieren aus der `.ioc` sind zu prüfen:

- `USB_DEVICE/Target/usbd_conf.h`: `USBD_MAX_NUM_INTERFACES` muss `4U` sein
  (der Composite-Block selbst steht im `USER CODE`-Bereich und überlebt).
- `USB_DEVICE/Target/usbd_conf.c`: die FIFO-Aufteilung (fünf TX-FIFOs).
- `USB_DEVICE/App/usb_device.c`: die beiden `USBD_RegisterClassComposite()`.
- `USB_DEVICE/App/usbd_desc.c`: die Gerätestrings.

Das CAN-Bit-Timing ist bewusst **nicht** von CubeMX abhängig: `can_if.c`
konfiguriert `hcan1` vollständig selbst, die Werte in `MX_CAN1_Init()` sind
irrelevant. Ebenso liegen die CAN-IRQ-Handler in einem `USER CODE`-Block von
`stm32f4xx_it.c` statt im NVIC-Tab.

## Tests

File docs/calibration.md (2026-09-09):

# Kalibrierung: AIN, AOUT, CURR

`AIN?`, `AOUT` und `CURR?` liefern/erwarten physikalische Werte (mV bzw. mA),
keine rohen ADC-/DAC-Werte. Die Umrechnung passiert über eine stückweise
lineare Kalibrierung je Kanal in `Core/Src/calibration.c`
(`cal_ain[4]`, `cal_curr[2]`, `cal_aout[2]`). Jeder Eintrag ist eine
`cal_curve_t` aus N gemessenen Wertepaaren (x aufsteigend sortiert),
zwischen benachbarten Punkten wird linear interpoliert, an den Enden mit der
Steigung des jeweils äußeren Segments extrapoliert (`Cal_Apply()`/
`Cal_Invert()` in `calibration.c`). CURR1-2 haben weiterhin nur die
ursprünglichen 2 Endpunkte; AIN1-4/AOUT1-2 haben seit 2026-09-09 zusätzliche
Zwischenpunkte (siehe unten).

**Aktueller Stand (2026-09-08): alle sechs Kanäle real durchkalibriert und
gegen Multimeter/Amperemeter verifiziert.**
- AOUT1-2 (Messpunkte 500/2800 mV Rohwert, siehe `cal_aout`): `AOUT 1/2 5000`
  → 4,989 V / 4,990 V (< 0,3 % Abweichung).
- AIN1-4 (Messpunkte ca. 1,308V/10,99V, siehe `cal_ain`): `AIN? 4` liefert bei
  10,99V angelegter Spannung exakt 10990 mV.
- CURR1-2 (Messpunkte 0,3A/1,2A, siehe `cal_curr`): `CURR? 1/2` liefert bei
  700mA echtem Laststrom (Amperemeter) 699 mA auf beiden Kanälen
  (< 0,2 % Abweichung). Vorausgegangene Hardware-Defekte (Q22+Q28 an
  PWR12-1, U18/U19 nicht bestückt) wurden am 2026-09-08 behoben, siehe
  `docs/hardware-notes.md`.

**Update 2026-09-09: AOUT1/AIN1 hatten unterhalb des jeweils unteren
Kalibrierpunkts (Rohwert 500 bzw. ca. 320mV) eine reale, nicht durch eine
einzelne Gerade abbildbare Nichtlinearität** — aufgefallen bei einem
Testaufbau AOUT1→AIN1 mit Multimeter am gemeinsamen Knoten: `AOUT 1 1000`
lieferte real nur 906mV (statt ~1000mV), `AIN? 1` dabei sogar nur 687mV
(statt der real anliegenden ~909mV). Ursache laut Zwischenmessungen
(AOUTRAW-Sweep 100/250/372/500, jeweils mit Multimeter/`AINRAW?`
gegengemessen): die Steigung (real/roh) steigt bei AOUT1 stetig von ~2,8
(Rohwert 100) auf ~4,4 (Rohwert 500) — klassische Übernahmeverzerrung des
AOUT-Gegentaktpuffers nahe der Nulldurchgangszone (siehe
"Schaltungs-Herleitung" unten). Bei AIN1 ist der Bereich unterhalb
`AINRAW?`≈27 (real <500mV) noch deutlicher gekrümmt. Behoben durch
Erweiterung von `Cal_Apply`/`cal_point_t` auf stückweise lineare
Interpolation mit mehreren Stützstellen (`cal_curve_t`, siehe oben) statt
einer starren 2-Punkt-Geraden — AIN1/AOUT1 haben jetzt zusätzliche
Messpunkte bei Rohwert 100/250/372 (AOUT) bzw. `AINRAW?` 9/27/166 (AIN),
alle mit Multimeter verifiziert. **Auf Hardware verifiziert:** `AOUT 1 1000`
liefert jetzt real 982mV, `AIN? 1` dabei 984mV (vorher 687mV) — < 0,3%
Abweichung vom real gemessenen Wert.

**AOUT2/AIN2 gleichermassen betroffen und mit derselben Methode behoben**
(2026-09-09, AOUT2→AIN2, Multimeter am gemeinsamen Knoten): vor dem Fix
lieferte `AIN? 2` bei `AOUT 2 1000` nur 678mV (real anliegend: 913mV).
Zwischenpunkte bei Rohwert 100/250/368 (AOUT2, real 148/516/913mV) bzw.
`AINRAW?` 1/26/151 (AIN2, gleiche real-Werte) ergänzt. **Auf Hardware
verifiziert:** `AOUT 2 1000` liefert jetzt real 978mV, `AIN? 2` dabei 973mV
(vorher 678mV) — < 0,6% Abweichung.

**AIN3/AIN4 ebenfalls nachgemessen und behoben** (2026-09-09, Testaufbau
umgesteckt: AOUT1→AIN3, AOUT2→AIN4, Multimeter jeweils am gemeinsamen
Knoten). Vor dem Fix: `AIN? 3` bei `AOUT 1 1000` nur 805mV (real 981mV),
`AIN? 4` bei `AOUT 2 1000` nur 812mV (real 976mV) — derselbe Effekt wie bei
AIN1/AIN2, unabhängig vom jeweils angeschlossenen AOUT-Kanal, also eine
Eigenschaft der AIN-Eingänge selbst (ADC-Nichtlinearität nahe 0), nicht der
AOUT-Ausgänge. Zwischenpunkte bei `AINRAW?` 8/27/195 (AIN3, real
83/502/981mV) bzw. 1/32/197 (AIN4, real 147/509/976mV) ergänzt. **Auf
Hardware verifiziert:** `AIN? 3` zeigt jetzt 981mV (real 981mV, exakt),
`AIN? 4` zeigt 973mV (real 976mV, < 0,4% Abweichung).

Damit haben alle vier AIN-Kanäle und beide AOUT-Kanäle die zusätzlichen
Zwischenpunkte; nur CURR1-2 sind von dieser Änderung nicht betroffen (dort
liegen keine neuen Messpunkte vor, die ursprüngliche 2-Punkt-Kalibrierung
von 2026-09-08 gilt weiter unverändert).

**Wichtig, dauerhaft zu beachten:** Der maximal zulässige Dauerstrom für
PWR12/CURR ist NICHT der schaltplan-abgeleitete Vollausschlag (2,5A),
sondern durch die Polyfuses F1/F13/F14 auf **1,5A** begrenzt (F1 gemeinsam
für beide Kanäle — bei gleichzeitiger Nutzung beider PWR12-Ausgänge muss
deren Summe unter 1,5A bleiben). Details:
`docs/hardware-notes.md`, Abschnitt "Maximal zulässiger Dauerstrom".

## Schaltungs-Herleitung (micro_HIL_v0.1)

Quelle: `ELECTRICS/micro_HIL_v0.1` (KiCad), Sheets `Input-Driver.kicad_sch`
(AIN) und `Output-Driver.kicad_sch` (AOUT, CURR).

- **AIN1-4** (PA3/PA0/PA1/PA2): Spannungsteiler 100 kΩ (R127/129/131/133,
  nach Signal) / 33 kΩ (R128/130/132/134, nach GND) vor einem
  Unity-Gain-Puffer (TLV6001). Teilerfaktor `(100k+33k)/33k = 4.0303`, d. h.
  0..3300 mV am ADC-Pin (PA3/PA0/PA1/PA2) entsprechen nominell 0..13300 mV
  am AIN-Eingang.
- **CURR1-2** (PA6/PA7, Sense für 12V_OUT1/2): Shunt R73/R74 = 50 mΩ
  (Ohmite LVK24, `LVK24R050CER`) + INA240A1D (Gain 20 V/V, REF1/REF2 auf
  GND). `V_sense[mV] = I[mA] · 0.05 Ω · 20 = I[mA]` — die Schaltung ist so
  dimensioniert, dass 1 mV Sense-Spannung nominell genau 1 mA Laststrom
  entspricht.
- **AOUT1-2** (PA5/PA4 = DAC_OUT2/1): Nichtinvertierender OPA990-Verstärker,
  Gain `1 + R63/R62 = 1 + 27k/10k = 3.7` (Kanal 2 analog mit R79/R78,
  gleiche Werte). Nominell 0..3300 mV DAC-Sollwert → 0..12210 mV am Ausgang.
  **Wichtig:** Dahinter liegt ein BC817/BC807-Gegentaktpuffer
  (Basisstromverstärkung für Lastfähigkeit), der **nicht** in der
  Gegenkopplungsschleife des OpAmp liegt (Feedback R63/R79 zweigt vor den
  Transistoren ab) — ein Offset durch nicht kompensierte Vbe-Abfälle ist
  möglich und zeigt sich erst in der realen Messung, nicht in der
  Schaltplan-Herleitung.

## Diagnose-Kommandos für die Kalibrierung

Zusätzlich zu `AIN?`/`AOUT`/`CURR?` (die die Kalibrierung anwenden) gibt es
unkalibrierte Gegenstücke, die direkt den rohen ADC-/DAC-Wert ansprechen:

| Kommando | Bedeutung |
|---|---|
| `AINRAW? <1-4>` | Roh-ADC-Wert in mV (`raw*3300/4095`), ohne `cal_ain` |
| `CURRRAW? <1-2>` | Rohe Sense-Spannung in mV, ohne `cal_curr` |
| `AOUTRAW <1-2> <mV>` | DAC-Sollwert direkt setzen (0..3300), ohne `cal_aout` |

Host-seitig: `MicroHIL.get_ain_raw_mv()`, `get_curr_raw_mv()`,
`set_aout_raw_mv()` in `host/microhil.py`.

## Messprozedur

Für jeden Kanal mindestens zwei Referenzpunkte messen, die den Nutzbereich
möglichst weit aufspannen (Faustregel: ca. 10 % und 80–90 % des
Vollausschlags — zu eng beieinander liegende Punkte verstärken den Effekt
von Messrauschen auf die berechnete Steigung). Seit der Umstellung auf
`cal_curve_t` (2026-09-09, stückweise linear) können es auch mehr als 2
Punkte sein — sinnvoll, wenn (wie bei AOUT1/AIN1 unterhalb ihres jeweils
unteren Endpunkts) eine einzelne Gerade den tatsächlichen Bereich, in dem
der Kanal genutzt wird, nicht gut genug trifft. Dafür in dem
Zielspannungs-/Zielstrombereich, der tatsächlich gebraucht wird, 1-2
zusätzliche Punkte messen (z. B. per `AOUTRAW`/`AINRAW?`-Sweep) und in die
`x[]`/`y[]`-Arrays der Kurve einsortieren (x aufsteigend).

### AIN1-4

1. Bekannte, präzise Spannung `V1` an AIN `n` anlegen (kalibrierte
   Spannungsquelle, mit Multimeter am Eingang nachgemessen).
2. `AINRAW? n` abfragen → `x1`. Multimeter-Wert (in mV) → `y1`.
3. Zweite Spannung `V2` anlegen, `AINRAW? n` → `x2`, Multimeter → `y2`.
4. In `Core/Src/calibration.c`: die `ainN_x`/`ainN_y`-Arrays für Kanal `n`
   mit `{x1, x2}`/`{y1, y2}` füllen (bzw. weitere Punkte ergänzen).
5. Neu bauen/flashen, mit `AIN? n` gegen das Multimeter verifizieren.

### CURR1-2

1. Bekannten, präzisen Laststrom `I1` durch 12V-OUT `n` treiben
   (elektronische Last oder definierter Widerstand an bekannter Spannung),
   mit einem Amperemeter in Reihe nachgemessen.
2. `CURRRAW? n` abfragen → `x1`. Amperemeter-Wert (in mA) → `y1`.
3. Zweiten Strom `I2` einstellen, `CURRRAW? n` → `x2`, Amperemeter → `y2`.
4. In `calibration.c`: `cal_curr[n-1] = {x1, y1, x2, y2};`
5. Neu bauen/flashen, mit `CURR? n` gegen das Amperemeter verifizieren.

### AOUT1-2

1. `AOUTRAW n <x1>` senden (z. B. `500`), tatsächliche Ausgangsspannung mit
   Multimeter messen → `y1`.
2. `AOUTRAW n <x2>` senden (z. B. `2800`), messen → `y2`.
3. In `calibration.c`: die `aoutN_x`/`aoutN_y`-Arrays für Kanal `n` mit
   `{x1, x2}`/`{y1, y2}` füllen (bzw. weitere Punkte ergänzen).
4. Neu bauen/flashen, mit `AOUT n <ziel_mV>` + Multimeter verifizieren.

Nach jeder Änderung an `calibration.c`: `CHANGELOG.md` aktualisieren, dann
Firmware neu bauen und flashen (die Konstanten sind zur Compile-Zeit fest
verdrahtet, kein EEPROM/Flash-Parameter zur Laufzeit).

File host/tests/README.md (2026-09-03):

# Prüfskripte (ohne Hardware)

Beide Skripte laufen ohne angeschlossenen microHIL und sichern die zwei
Stellen ab, an denen sich Fehler still einschleichen: das CAN-Bit-Timing und
das SLCAN-Drahtformat.

```
python host/tests/check_bit_timing.py
python host/tests/check_slcan_wire.py
```

- **`check_bit_timing.py`** bildet `timing_for_bitrate()` aus
  `Core/Src/slcan.c` nach und prüft für alle `Sn`-Bitraten, dass die
  Nennbitrate exakt getroffen wird und BS1/BS2/Prescaler in den
  bxCAN-Registergrenzen liegen (BS1 ≤ 16 tq, BS2 ≤ 8 tq).
- **`check_slcan_wire.py`** prüft beide Richtungen des Protokolls gegen den
  echten `python-can`-Treiber: dass die Firmware alles versteht, was
  `python-can` sendet (inklusive der Kommandofolge beim Verbinden), und dass
  `python-can` alles dekodiert, was die Firmware erzeugt.

Wird die Firmware an diesen Stellen geändert, müssen die Nachbildungen in den
Skripten mitgezogen werden — sie sind bewusst eine unabhängige zweite
Implementierung, kein Import.

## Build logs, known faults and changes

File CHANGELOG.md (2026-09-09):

# Changelog

## Unreleased

- AOUT1/AIN1 und AOUT2/AIN2: reale Nichtlinearität unterhalb des jeweils unteren Kalibrierpunkts gefunden und behoben, **auf Hardware verifiziert** — `Core/Src/calibration.c`/`calibration.h` von starrer 2-Punkt-Gerade (`cal_point_t`, `Cal_Apply`) auf stückweise lineare Kalibrierung mit mehreren Stützstellen (`cal_curve_t`, `Cal_Apply`/`Cal_Invert`) umgebaut. Auslöser: Testaufbau AOUT1→AIN1 mit Multimeter am gemeinsamen Knoten zeigte bei `AOUT 1 1000` real nur 906mV statt ~1000mV, `AIN? 1` dabei sogar nur 687mV statt der real anliegenden ~909mV — beide Zielwerte lagen unterhalb der bis dahin vermessenen Kalibrierpunkte (Rohwert 500 bzw. `AINRAW?`≈320). Ein AOUTRAW-Sweep (100/250/372/500, mit Multimeter und `AINRAW?` gegengemessen) zeigte, dass die Kennlinie dort wirklich gekrümmt ist (Steigung real/roh steigt stetig, keine Gerade passt), nicht nur Extrapolationsfehler. AIN1/AOUT1 haben jetzt zusätzliche Messpunkte in diesem Bereich. Nach dem Fix: `AOUT 1 1000` liefert real 982mV, `AIN? 1` zeigt 984mV (vorher 687mV). Kanal 2 zeigte denselben Effekt (`AIN? 2` bei `AOUT 2 1000` vorher 678mV statt real 913mV) und wurde mit derselben Methode nachkalibriert — danach real 978mV, `AIN? 2` zeigt 973mV (vorher 678mV). AIN3/AIN4 zeigten denselben Effekt unabhängig vom angeschlossenen AOUT-Kanal (Testaufbau umgesteckt: AOUT1→AIN3, AOUT2→AIN4) — also eine Eigenschaft der AIN-Eingänge selbst, nicht der AOUT-Ausgänge; ebenfalls nachkalibriert, danach `AIN? 3` 981mV (real 981mV, exakt), `AIN? 4` 973mV (real 976mV). Damit haben alle vier AIN- und beide AOUT-Kanäle die zusätzlichen Stützstellen, nur CURR1-2 unverändert. Details, Messwerte und aktualisierte Messprozedur in `docs/calibration.md`.
- Build: `.ld`-Linker-Skripte (`STM32F446xx_FLASH.ld`, `STM32F446RETX_FLASH.ld`/`_RAM.ld`) bauten mit dem bei STM32CubeIDE 1.10.1 mitgelieferten GCC 10.3.1 nicht (`(READONLY)`-Attribut auf `.ARM.extab`/`.ARM`/`.preinit_array`/`.init_array`/`.fini_array` braucht GCC 11+, siehe Kommentar in den Dateien selbst) — Attribut entfernt, CMake-Build (`cmake --preset Release && cmake --build --preset Release`) läuft jetzt durch. Siehe README.md, Abschnitt "Building the firmware".

- Konfigurierbare PWM-Frequenz (`PWMFREQ`/`PWMFREQ?`, `Core/Src/protocol.c`): gilt fuer PWM1-4 gemeinsam (ein Timer, TIM3), Firmware waehlt Prescaler/ARR passend zur gewuenschten Frequenz und rechnet laufende Duty-Cycle-Sollwerte auf das neue ARR um, damit sich das Tastverhaeltnis dabei nicht aendert. `host/microhil.py` (`set_pwm_freq_hz`/`get_pwm_freq_hz`) und `host/gui.py` entsprechend erweitert. Auf Hardware end-to-end verifiziert (Setzen/Klemmen/Zuruecklesen, Tastverhaeltnis bleibt bei Frequenzwechsel erhalten, Verriegelung mit `OUT` haelt auch nach Frequenzwechsel). Details in `docs/protocol.md`.
  - **Bug gefunden und behoben (vor Hardware-Test):** `OUT <n> 1` stoppt einen aktiven PWM-Kanal durch direktes Schreiben der Timer-Register, nicht ueber `pwm_set()` — ohne Korrektur haette ein späterer `PWMFREQ`-Wechsel den alten (eigentlich durch die Verriegelung deaktivierten) Duty-Cycle-Sollwert wiederhergestellt und den Kanal entgegen der Verriegelung stillschweigend wieder eingeschaltet. Fix: `cmd_out_set()` setzt den getrackten Duty-Sollwert mit auf 0.
  - **Obere Grenzfrequenz per Oszilloskop verifiziert (2026-09-09):** PWM1 bei 1/20/100 kHz mit 50% Duty Cycle gemessen — bei 100 kHz nehmen die Flanken schon einen spuerbaren Anteil der Periode ein (Endstufe, PUSH-PULL OUTPUT DRIVER BC807/BC817, stösst an ihre Schaltgeschwindigkeit), bei 20 kHz noch sauber. `PWMFREQ` deshalb in der Firmware hart auf `1..20000` Hz gekappt (vorher generische `1000000`). Zusaetzlich festgestellt: eine leichte Duty-Cycle-Asymmetrie (High-Puls schmaler als Low) ist bei allen drei gemessenen Frequenzen gleich stark vorhanden, also nicht frequenzabhaengig, sondern vermutlich eine systematische Eigenschaft der Push-Pull-Stufe (asymmetrische Speicherzeiten BC807/BC817) — keine Fehlfunktion, Details in `docs/hardware-notes.md`.
- Digital-Eingänge (DIN_IN1-8) lasen unbeschaltet immer High — zwei unabhängige Root Causes gefunden und behoben, beide auf Hardware verifiziert:
  1. Fix vom 06.09. (externen Pullup entfernt, `GPIO_PULLDOWN`) beruhte auf einer unvollständigen Diagnose und machte die Eingänge zeitweise komplett funktionsunfähig (nie High, selbst bei 12V) — Ursache: jeder Kanal hat einen Komparator (LM397, **Open-Collector-Ausgang**) vor dem GPIO, der entfernte Widerstand war dessen notwendiger Pullup. Wieder aufgelötet (R95-98, R115-118), `GPIO_PULLDOWN`→`GPIO_NOPULL` zurückgestellt (mit Pullup überflüssig, unnötiger Störabstandsverlust).
  2. Eine erste Firmware-Invertierung von `IN?` (basierend auf manuellem Schaltplan-Koordinaten-Tracing) stellte sich als falsch heraus — per `kicad-cli sch export netlist` gegenverifiziert: `INPUTn` liegt am nicht-invertierenden Komparator-Eingang (IN+), die Referenzschwelle am invertierenden (IN−); die rohe GPIO-Polarität war von Anfang an korrekt (1 = 12V erkannt). Invertierung zurückgenommen. Tatsächliche Ursache des "immer High"-Symptoms: am IN+-Netz hängt kein Pulldown, ein offener Eingang floatet daher zuverlässig über die Schwelle. Fix: Bodge-Pulldown IN+→GND, auf allen 8 Kanälen nachgerüstet und einzeln verifiziert (offen→`0`, 12V→`1`, keine Überkopplung zwischen Kanälen). Zusätzlich mit 5V-Signal gegen beide REF-Einstellungen (5V/12V) getestet — Schwelle wird korrekt ausgewertet, nicht nur binär 12V-vs-GND.

  Damit ist der komplette DIN-Fehlerkomplex abgeschlossen.

  Details und Messwerte in `docs/hardware-notes.md`.
- Firmwareseitige Strombegrenzung für PWR12-1/2 (`Core/Src/protocol.c`, `pwr12_guard_poll()`): pro Kanal per `ILIM`/`ILIM?` konfigurierbares Limit (Default 1200 mA), schaltet den Kanal ab, wenn er länger als 100 ms überschritten wird; unabhängig davon eine Abschaltung beider Kanäle, wenn CURR1+CURR2 in Summe 1500 mA überschreiten (Ihold der gemeinsamen Polyfuse F1, siehe `docs/hardware-notes.md`; der 12V-Eingang versorgt neben den Ausgängen auch die MCU). Beide Verriegelungen lösen sich erst, wenn die betroffene(n) Schaltanforderung(en) per `PWR12 <n> 0` einmal zurückgenommen wurden — neues `PWR12FLT?` liefert die Ursache (Bit0 = Kanal-Limit, Bit1 = Gesamtbudget). `host/microhil.py` entsprechend erweitert (`set_curr_limit_ma`, `get_curr_limit_ma`, `get_pwr12_fault`), Details in `docs/protocol.md`.
  - **Auf Hardware verifiziert (2026-09-08):** Pro-Kanal-Limit mit elektronischer Last getestet (Limit testweise auf 300 mA gesenkt, Last auf 500 mA) — Kanal schaltet nach ~85-106 ms ab (Debounce-Fenster trifft), bleibt verriegelt (`PWR12FLT?` bleibt 1 über >1,7 s), erneutes `PWR12 1 1` ohne vorheriges `PWR12 1 0` bleibt wirkungslos, nach Zurücknehmen und Last unter Limit (200 mA) bleibt der Kanal über 2 s stabil an. Gesamtbudget-Pfad mit temporär auf 150 mA abgesenktem Testwert (echte 1500 mA hätten eine einzelne Last nahe an die Sicherungsgrenze getrieben) ebenso verifiziert — identisches Verriegelungsverhalten, danach zurück auf den echten 1500-mA-Wert geflasht.
  - **Bug gefunden und behoben:** Die erste Version prüfte das Gesamtbudget ganz ohne Entprellung ("sofort" laut Spezifikation) — dabei löste schon das bloße Einschalten eines einzelnen, unbelasteten Kanals die Verriegelung sofort aus (auf Hardware reproduziert, CURR zeigte danach ~0 mA). Ursache: ein Schaltstörimpuls beim MOSFET-Einschalten trifft die eine ungefilterte 2-ms-ADC-Probe. Fix: kurze 10-ms-Entprellung auch für den Budget-Pfad (`PWR12_BUDGET_DEBOUNCE_MS`) — filtert den Einzelprobe-Glitch, bleibt aber ca. 10x schneller als die 100-ms-Entprellung pro Kanal.
- Hardware-Reparaturen (2026-09-08): Q22 UND Q28 (PWR12-1-Schalter, PMT200EPEX) getauscht — Q22 allein reichte nicht, Q28 war unabhängig ebenfalls defekt (Spannungseinbruch 12V→8,5V bei nur 0,3A Last, per Bisektion gefunden). U18/U19 (INA240A1D, CURR1/CURR2) bestückt, waren zuvor fehlbestückt. PWR12-1 liefert jetzt 12V unbelastet/11,8V bei 0,3A (normaler Bereich), CURR1/CURR2 stabil nahe 0 unbelastet. Details in `docs/hardware-notes.md`.
- Maximal zulässiger Dauerstrom für PWR12/CURR dokumentiert (`docs/hardware-notes.md`): durch die Polyfuses F1 (gemeinsam für beide Kanäle)/F13/F14 (je Kanal), alle MINISMDC150F/24-2, auf 1,5A begrenzt — nicht die schaltplan-abgeleiteten 2,5A Vollausschlag. Die PMT200EPEX-MOSFETs (SOT223, nicht SOT-23 wie zunächst notiert) sind bei diesem Strom nicht die begrenzende Komponente (~0,38W von 800mW-1,75W Ptot-Budget).
- CURR1-2 real durchkalibriert (`cal_curr` in `calibration.c`, Messpunkte 0,3A/1,2A, innerhalb des 1,5A-Sicherungslimits): beide Kanäle nah am nominellen 1:1. Verifiziert gegen 700mA Referenzlast (Amperemeter): `CURR? 1/2` liefert 699 mA auf beiden Kanälen (< 0,2 % Abweichung). Damit sind alle sechs kalibrierten Kanäle (AOUT1-2, AIN1-4, CURR1-2) real gemessen und verifiziert.
- Projektgerüst angelegt (firmware/, host/, docs/)
- STM32CubeMX-Projekt `firmware/microHIL_fw` für STM32F446RET (CMake-Toolchain) generiert
  - USB OTG FS als Device mit CDC-Klasse (Virtual COM Port)
  - Pinbelegung: 4x Relais, 8x digitaler Eingang, 8x digitaler Ausgang, 4x Analogeingang, 2x Analogausgang (DAC), 2x schaltbarer 12V-Ausgang mit Strommessung, CAN1/CAN2 (Pins reserviert, Ansteuerung folgt später)
- USB-CDC-Echo (Virtual COM Port) funktionsfähig, End-to-End mit `host/test_echo.py` verifiziert
  - Fix: VBUS-Sensing deaktiviert (PA9 auf Platine nicht mehr verbunden, siehe `docs/hardware-notes.md`)
  - Fix: Clock-Tree in `SystemClock_Config()` korrigiert (HSE/PLL als Quelle statt fälschlich HSI) — verbauter Quarz läuft mit 8 statt 16 MHz, PLLM entsprechend angepasst
- Kommandoprotokoll für Relais/DIO/AIO/AOUT/12V-Ausgänge implementiert (`Core/Src/protocol.c`), Referenz in `docs/protocol.md`, Python-Client `host/microhil.py` — End-to-End auf Hardware getestet
- Test-GUI (`host/gui.py`, PySide6) zum manuellen Durchtesten aller Funktionen
- Fix: AOUT1/AOUT2-Zuordnung war vertauscht (PA4/PA5-Labels in CubeMX korrigiert, `dac_channel[]` in `protocol.c` entsprechend angepasst)
- PWM-Kanäle PWM1-4 (PC6-9, TIM3) im Protokoll ergänzt, softwareseitig gegen OUT1-4 verriegelt (dieselbe Endstufe laut Schaltplan) — **noch nicht auf Hardware getestet**, ST-Link war beim Umsetzen getrennt. Build erfolgreich, GUI-Konstruktion geprüft.
- CAN1 als CAN-USB-Interface im SLCAN-/Lawicel-Format (`Core/Src/can_if.c`, `Core/Src/slcan.c`), nutzbar mit `python-can` (`interface="slcan"`) und unter Linux via `slcand` als SocketCAN-Interface
  - bxCAN-Treiber mit Interrupt-RX (64-Frame-Ring), Accept-all-Filter, automatischer Bus-Off-Erholung und SLCAN-Fehlerflags; Bit-Timing wird zur Laufzeit gesucht statt in CubeMX hinterlegt, damit ein Regenerieren des `.ioc` die CAN-Anbindung nicht zerlegt
  - Filterbank-Split gesetzt (`SlaveStartFilterBank = 14`), damit CAN2 später überhaupt empfangen kann
  - Zusatzkommandos über CAN232 hinaus: `B<bit/s>` für krumme Bitraten (u. a. 750 kbit/s, das `python-can` fälschlich auf `S7` mappt) und `Y` für Loopback-Selbsttest ohne Bus
  - Referenz in `docs/can-usb.md`
  - Vollständig auf Hardware verifiziert: `O`/`L`/`Y` öffnen den Bus, Loopback-Frames (Standard/Extended/beide RTR-Varianten, 1 Mbit/s) laufen fehlerfrei, keine Statusflags, Parallelbetrieb mit dem HIL-Port stabil. Ursache eines zunächst fehlgeschlagenen Bring-ups war ein defekter CAN1-Transceiver (RXD blieb bei ~0,2 V statt ~5 V rezessiv) — Details und Ausschlussdiagnose in `docs/hardware-notes.md`. Noch offen: Test gegen einen echten zweiten Busteilnehmer, Bitraten-Messung am Oszilloskop.
- USB-Composite-Device mit zwei CDC-ACM-Funktionen (zwei virtuelle COM-Ports): Port 1 = HIL-Kommandoprotokoll, Port 2 = CAN1 — beide gleichzeitig nutzbar, weil sich ein COM-Port unter Windows nur einmal öffnen lässt — **auf Hardware verifiziert** (Enumeration, Parallelbetrieb beider Ports, GUI)
  - CompositeBuilder der ST-USB-Library aus dem passenden Cube-FW-Paket (F4 V1.28.3) ergänzt, CubeMX generiert das für die F4-Serie nicht selbst
  - FIFO-Aufteilung von OTG_FS neu vergeben (fünf TX-FIFOs statt zwei), Endpunktadressen fest zugeordnet
  - Gerätestrings auf `microHIL` geändert (vorher `STM32 Virtual ComPort`)
  - Fix: USB-Gerätedeskriptor deklarierte weiterhin `bDeviceClass=0x02` (CDC direkt am Gerät) statt der für IAD-Composite-Geräte nötigen Multi-Interface-Function-Klasse `0xEF/0x02/0x01` — Windows band ohne diesen Fix seinen CDC-Treiber direkt an Interface 0 und ignorierte den zweiten CDC-Funktionsblock komplett, sodass nur ein COM-Port erschien. Erst durch Hardware-Test gefunden.
- Host: `host/microhil_can.py` (python-can-Wrapper), `find_ports()`/`find_can_port()` in `host/microhil.py` zum Auseinanderhalten der beiden Ports, CAN-Reiter in `host/gui.py` mit Trace und Sendefeld, `python-can` in den Requirements
- Roadmap im README ergänzt, u. a. CAN2 als geplante Fernsteuer-Schnittstelle für microHIL
- Prüfskripte ohne Hardware in `host/tests/`: Bit-Timing gegen die bxCAN-Registergrenzen, SLCAN-Drahtformat in beiden Richtungen gegen den echten `python-can`-Treiber
- `host/test_echo.py` entfernt (Altlast aus der Bring-up-Phase, erwartete ein rohes Echo, das die Firmware seit dem Kommandoprotokoll nicht mehr liefert)
- `docs/protocol.md` präzisiert (Grundlage für einen künftigen LabControl-Treiber): Antwort-Terminator `\r\n`, Case-Sensitivität/Trennzeichen, Verhalten bei Leerzeile, VID:PID, ADC-Timing bei `AIN?`/`CURR?` — vor allem aber die bisher undokumentierte Asymmetrie, dass `AOUT`/`PWM` nur den Kanalindex mit `ERR RANGE` prüfen, den Nutzwert selbst aber still auf den gültigen Bereich klemmen statt abzulehnen
- Kalibrierung für `AIN?`/`AOUT`/`CURR?` ergänzt (`Core/Src/calibration.c`, `Cal_Apply()`): lineare 2-Punkt-Interpolation je Kanal statt der bisherigen Annahme einer idealen 3300 mV/4095-Referenz. `CURR?` liefert dadurch jetzt mA statt der rohen Sense-Spannung (schließt die in `docs/protocol.md` dokumentierte Lücke), `AOUT` nimmt die gewünschte physikalische Ausgangsspannung entgegen (kalibrierter Bereich statt fest `0..3300`). Neue Diagnose-Kommandos `AINRAW?`/`CURRRAW?`/`AOUTRAW` für unkalibrierten Rohzugriff, `host/microhil.py` entsprechend erweitert (`get_ain_raw_mv`, `get_curr_raw_mv`, `set_aout_raw_mv`; `get_curr_mv` in `get_curr_ma` umbenannt), `host/gui.py` zeigt CURR jetzt in mA statt roh an
  - Schaltungswerte (Spannungsteiler AIN, INA240A1D+50mΩ-Shunt CURR, OPA990-Verstärkung AOUT) per `kicad-cli sch export netlist` aus `ELECTRICS/micro_HIL_v0.1` hergeleitet, siehe `docs/calibration.md`
  - **Kalibrierkonstanten sind aktuell nominelle Platzhalter, keine Messwerte** — echte 2-Punkt-Kalibrierung je Kanal steht noch aus (Messprozedur in `docs/calibration.md`)
- AOUT1/AOUT2 real durchkalibriert (`cal_aout` in `calibration.c`, Messpunkte 500/2800 mV Rohwert): Steigung liegt nah am nominellen Gain 3.7, gemessener Offset ca. -370 mV (Kanal 1) bzw. -380 mV (Kanal 2) — passend zum erwarteten unkompensierten Vbe-Abfall des Gegentaktpuffers. Verifiziert: `AOUT 1/2 5000` liefert 4,989 V / 4,990 V (Zielabweichung < 0,3 %).
- AIN1-4 real durchkalibriert (`cal_ain` in `calibration.c`, Messpunkte ca. 1,308V/10,99V): Steigung nah am nominellen Teilerfaktor 4.0303, alle vier Kanäle konsistent. Verifiziert: `AIN? 4` liefert bei 10,99V angelegter Spannung exakt 10990 mV. CURR1-2 ist weiterhin nomineller Platzhalter.
- PWR12-1 liefert trotz `PWR12 1 1` ~0V am Ausgang — Root Cause gefunden: Q22 (PMT200EPEX, PMOS-Verpolschutz vor dem eigentlichen Schalter Q28) hat eine defekte Body-Diode (1,6V statt ~0,57V Durchlassspannung im Vergleich zu baugleichen Kanal-2-MOSFETs), blockiert dadurch den Strompfad unabhängig von der GPIO-Ansteuerung. PWR12-2 ist davon nicht betroffen (liefert sauber 12V). Details und Messwerte in `docs/hardware-notes.md`. Fix (Bauteiltausch) noch offen.
- CURR2 zeigte bei realem, per Amperemeter verifiziertem Laststrom nicht-monotone Werte (200mA→181, 1000mA→264, 2000mA→~221) statt der erwarteten ~1:1-Linearität — Root Cause gefunden: **U18 (CURR1) und U19 (CURR2), beide INA240A1D, sind schlicht nicht bestückt** (unvollständige Erstbestückung, kein Schaltungs-/Firmwarefehler). CURR-Kalibrierung (beide Kanäle) auf die Reparatursession verschoben (IC-Bestückung nötig), `cal_curr` bleibt auf nominellen Platzhaltern. Details in `docs/hardware-notes.md`.
- `*IDN?` liefert jetzt zusätzlich ein `SN=`-Feld mit einer eindeutigen, aus der 96-bit STM32-UID abgeleiteten Board-ID (`Core/Src/protocol.c`, `cmd_idn_query()`) — identisch mit der USB-Seriennummer (unter Windows als `SER=...` in der hwid sichtbar), damit ein Host (z. B. LabControl) ein bestimmtes physisches Board über das Kommandoprotokoll wiedererkennen und z. B. bekannte Hardware-Defekte je Exemplar ausblenden kann (siehe `docs/hardware-notes.md`). `host/microhil.py`: neue Methode `MicroHIL.get_serial()`.

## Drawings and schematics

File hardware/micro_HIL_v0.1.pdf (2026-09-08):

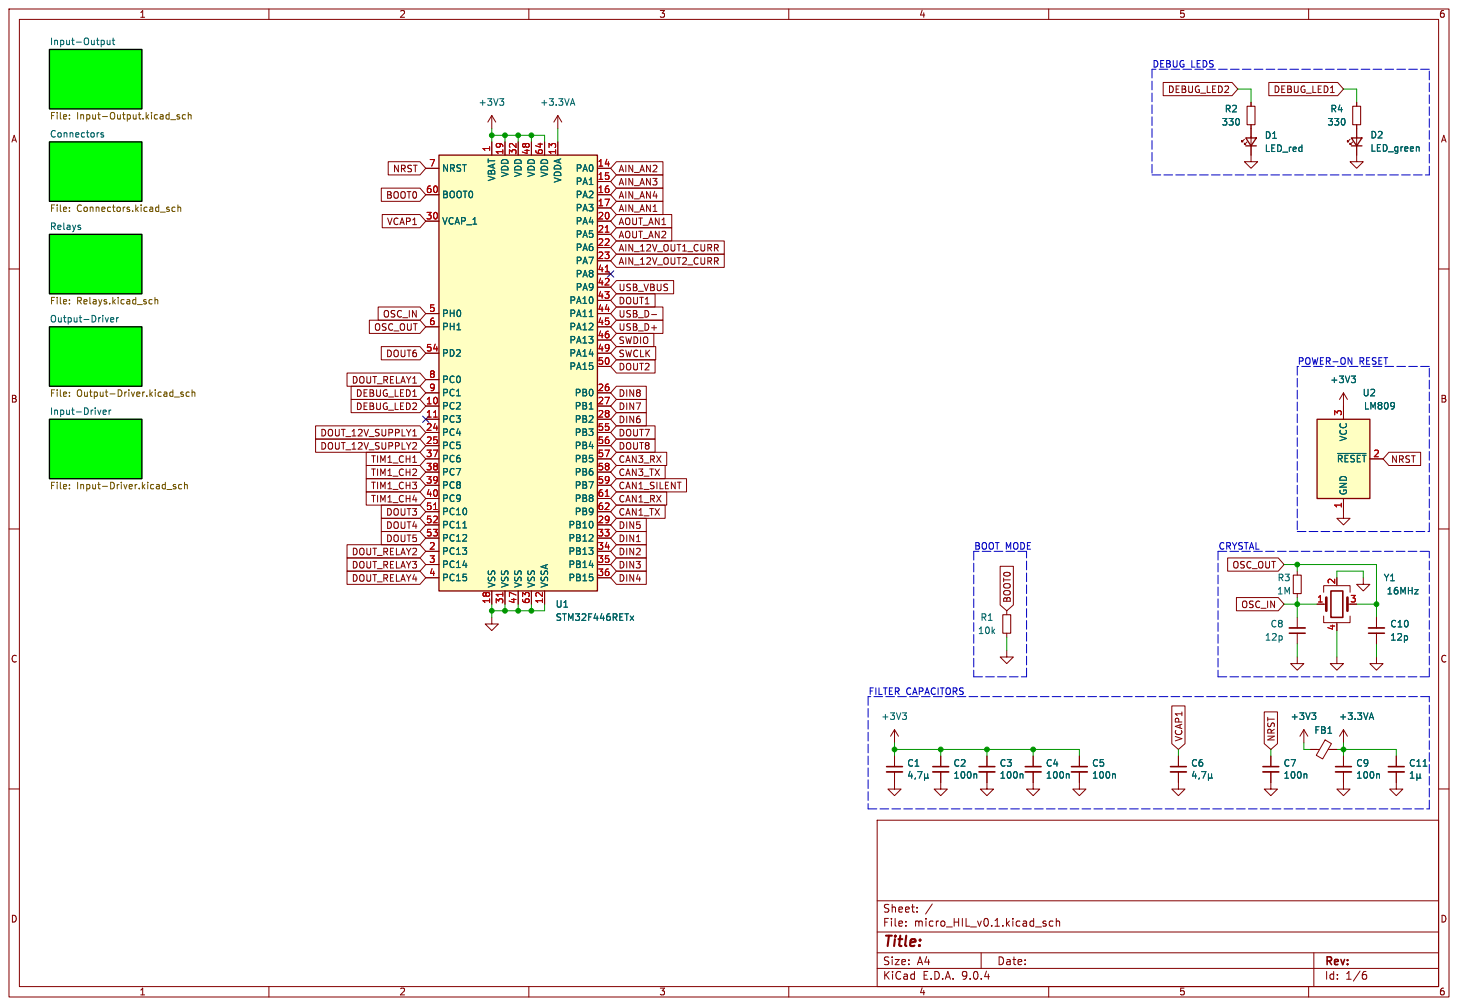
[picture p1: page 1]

1 VSS 18 VDD 19 VSS 31 VDD 32 VSS 47 VDD 48 VSS 63 VDD 64 VSSA 12 VDDA 13 PA0 14 PA1 15 PA2 16 PA3 17 PA4 20 PA5 21 PA6 22 PA7 23 PA8 41 PA9 42 PA10 43 PA11 44 PA12 45 PA13 46 PA14 49 PA15 50 PB0 26 PB1 27 PB2 28 PB3 55 PB4 56 PB5 57 PB6 58 PB7 59 PB8 61 PB9 62 PB10 29 PB12 33 PB13 34 PB14 35 PB15 36 U1STM32F446RETx +3.3VA C8

1 VSS 18 VDD 19 VSS 31 VDD 32 VSS 47 VDD 48 VSS 63 VDD 64 VSSA 12 VDDA 13 PA0 14 PA1 15 PA2 16 PA3 17 PA4 20 PA5 21 PA6 22 PA7 23 PA8 41 PA9 42 PA10 43 PA11 44 PA12 45 PA13 46 PA14 49 PA15 50 PB0 26 PB1 27 PB2 28 PB3 55 PB4 56 PB5 57 PB6 58 PB7 59 PB8 61 PB9 62 PB10 29 PB12 33 PB13 34 PB14 35 PB15 36 +3V3 +3.3VA

Input-Driver File: Input-Driver.kicad_sch

Id: 1/6 Title: File: micro_HIL_v0.1.kicad_sch Sheet: /

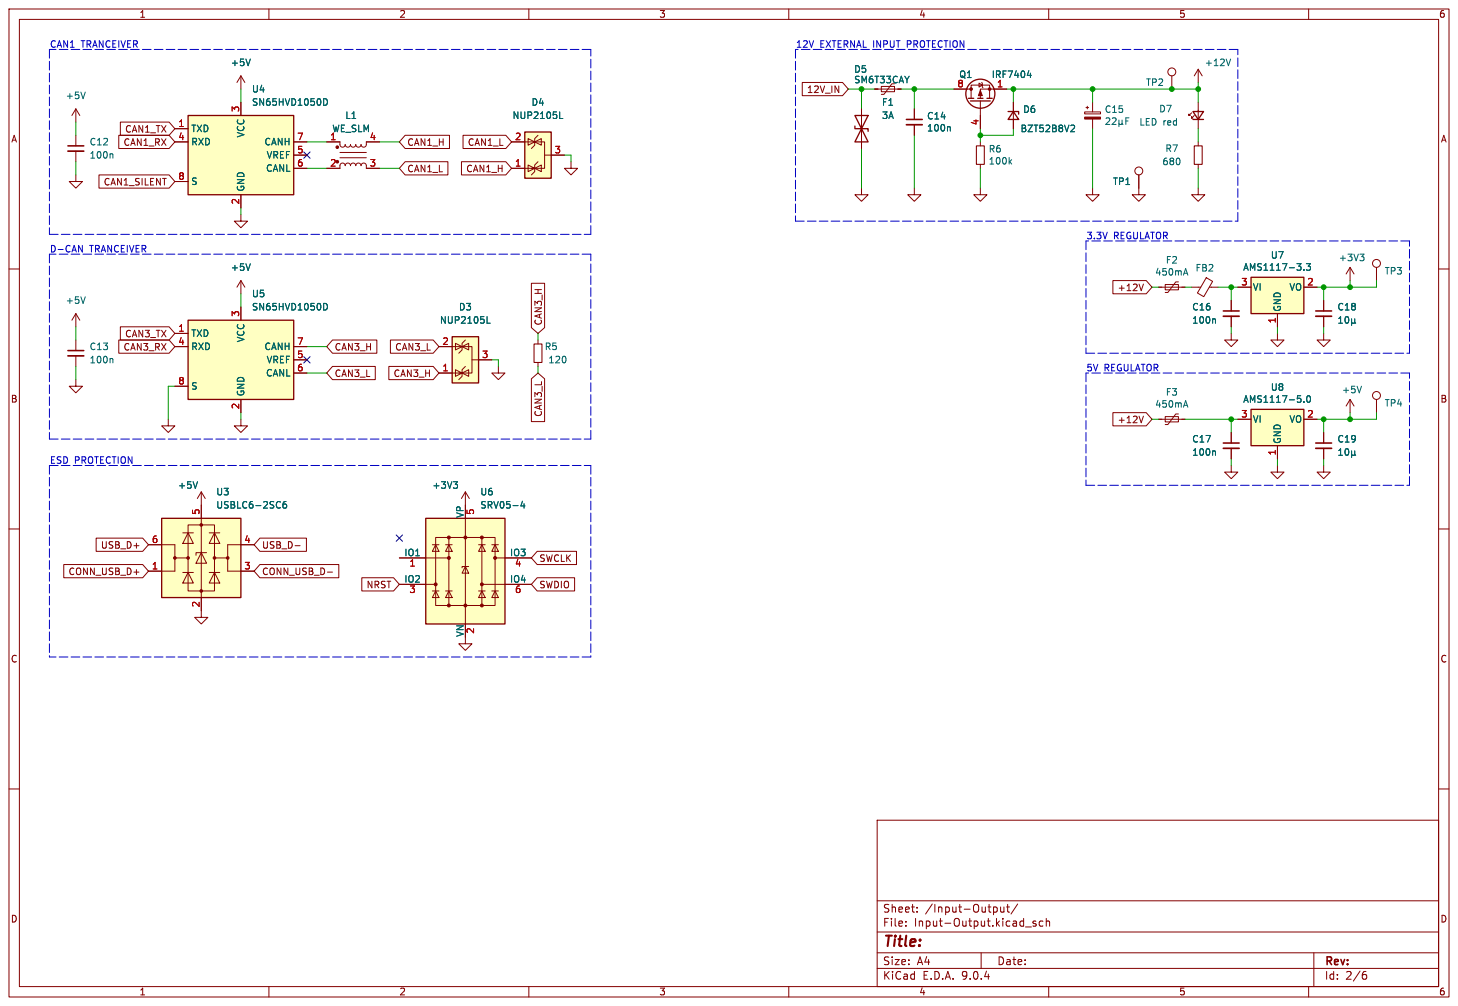
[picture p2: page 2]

Id: 2/6 Title: File: Input-Output.kicad_sch Sheet: /Input-Output/

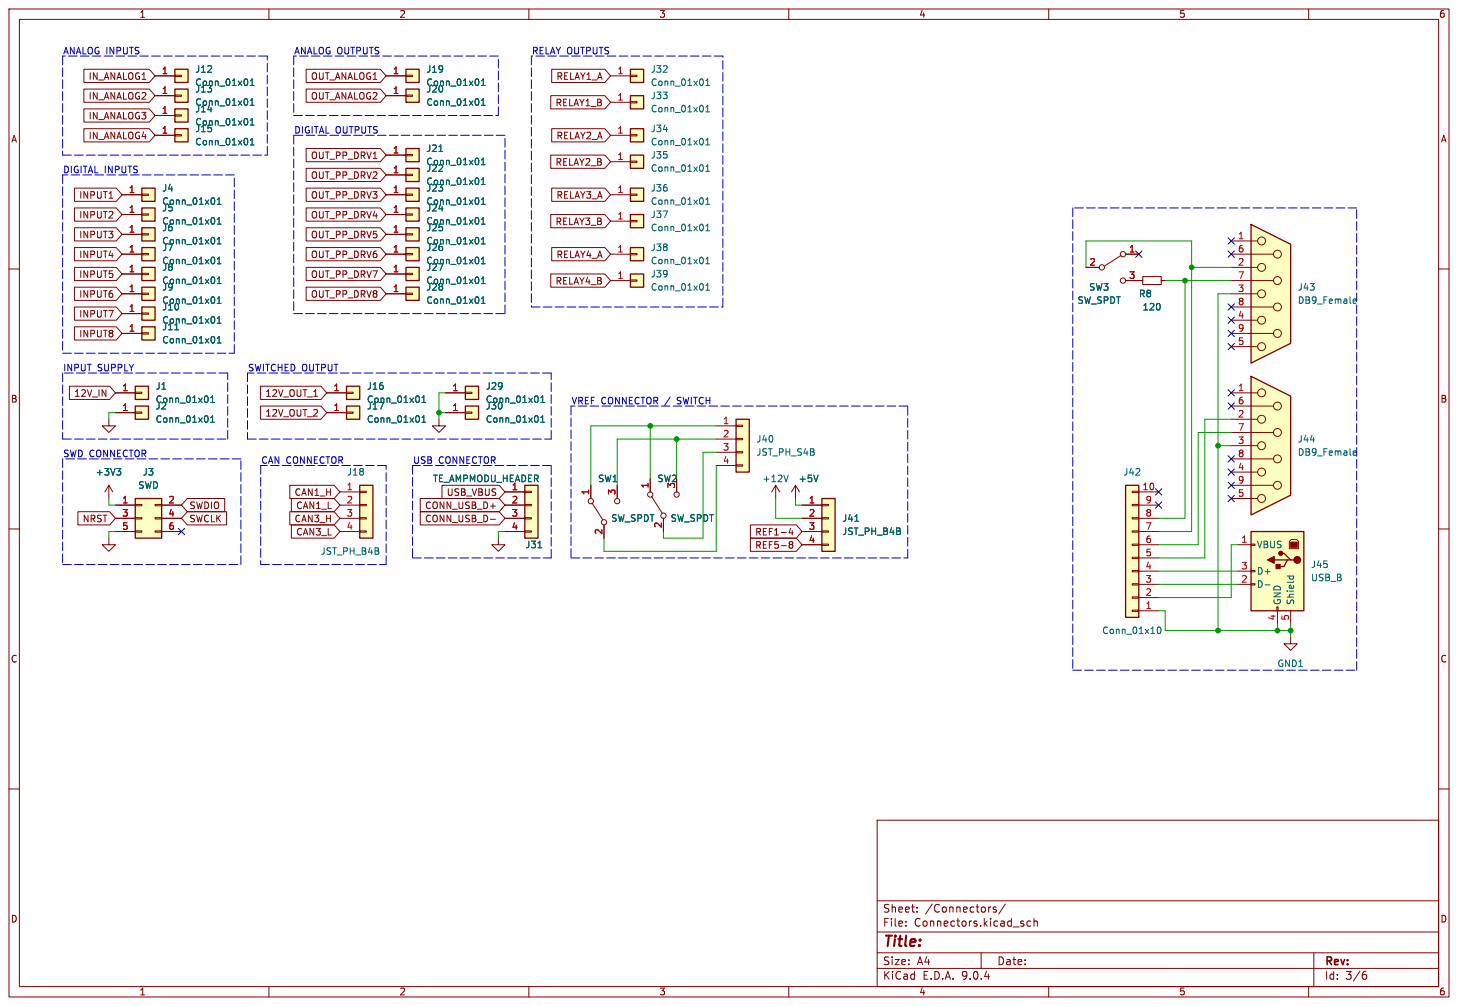
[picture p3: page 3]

Id: 3/6 Title: File: Connectors.kicad_sch Sheet: /Connectors/

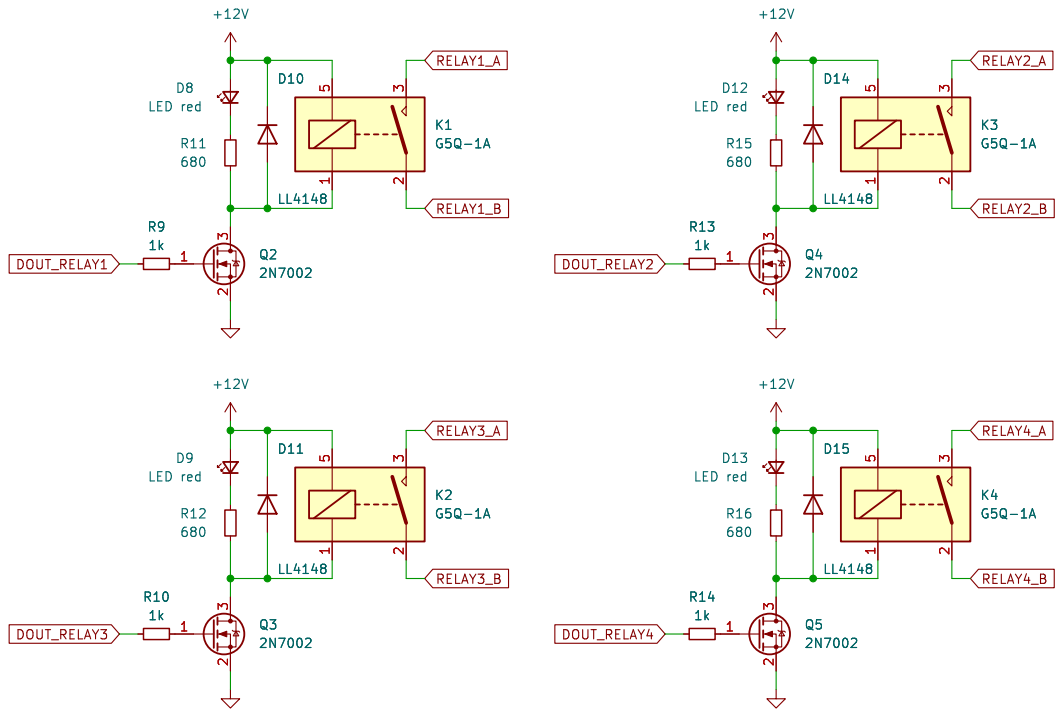
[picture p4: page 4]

Id: 4/6 Title: File: Relays.kicad_sch Sheet: /Relays/

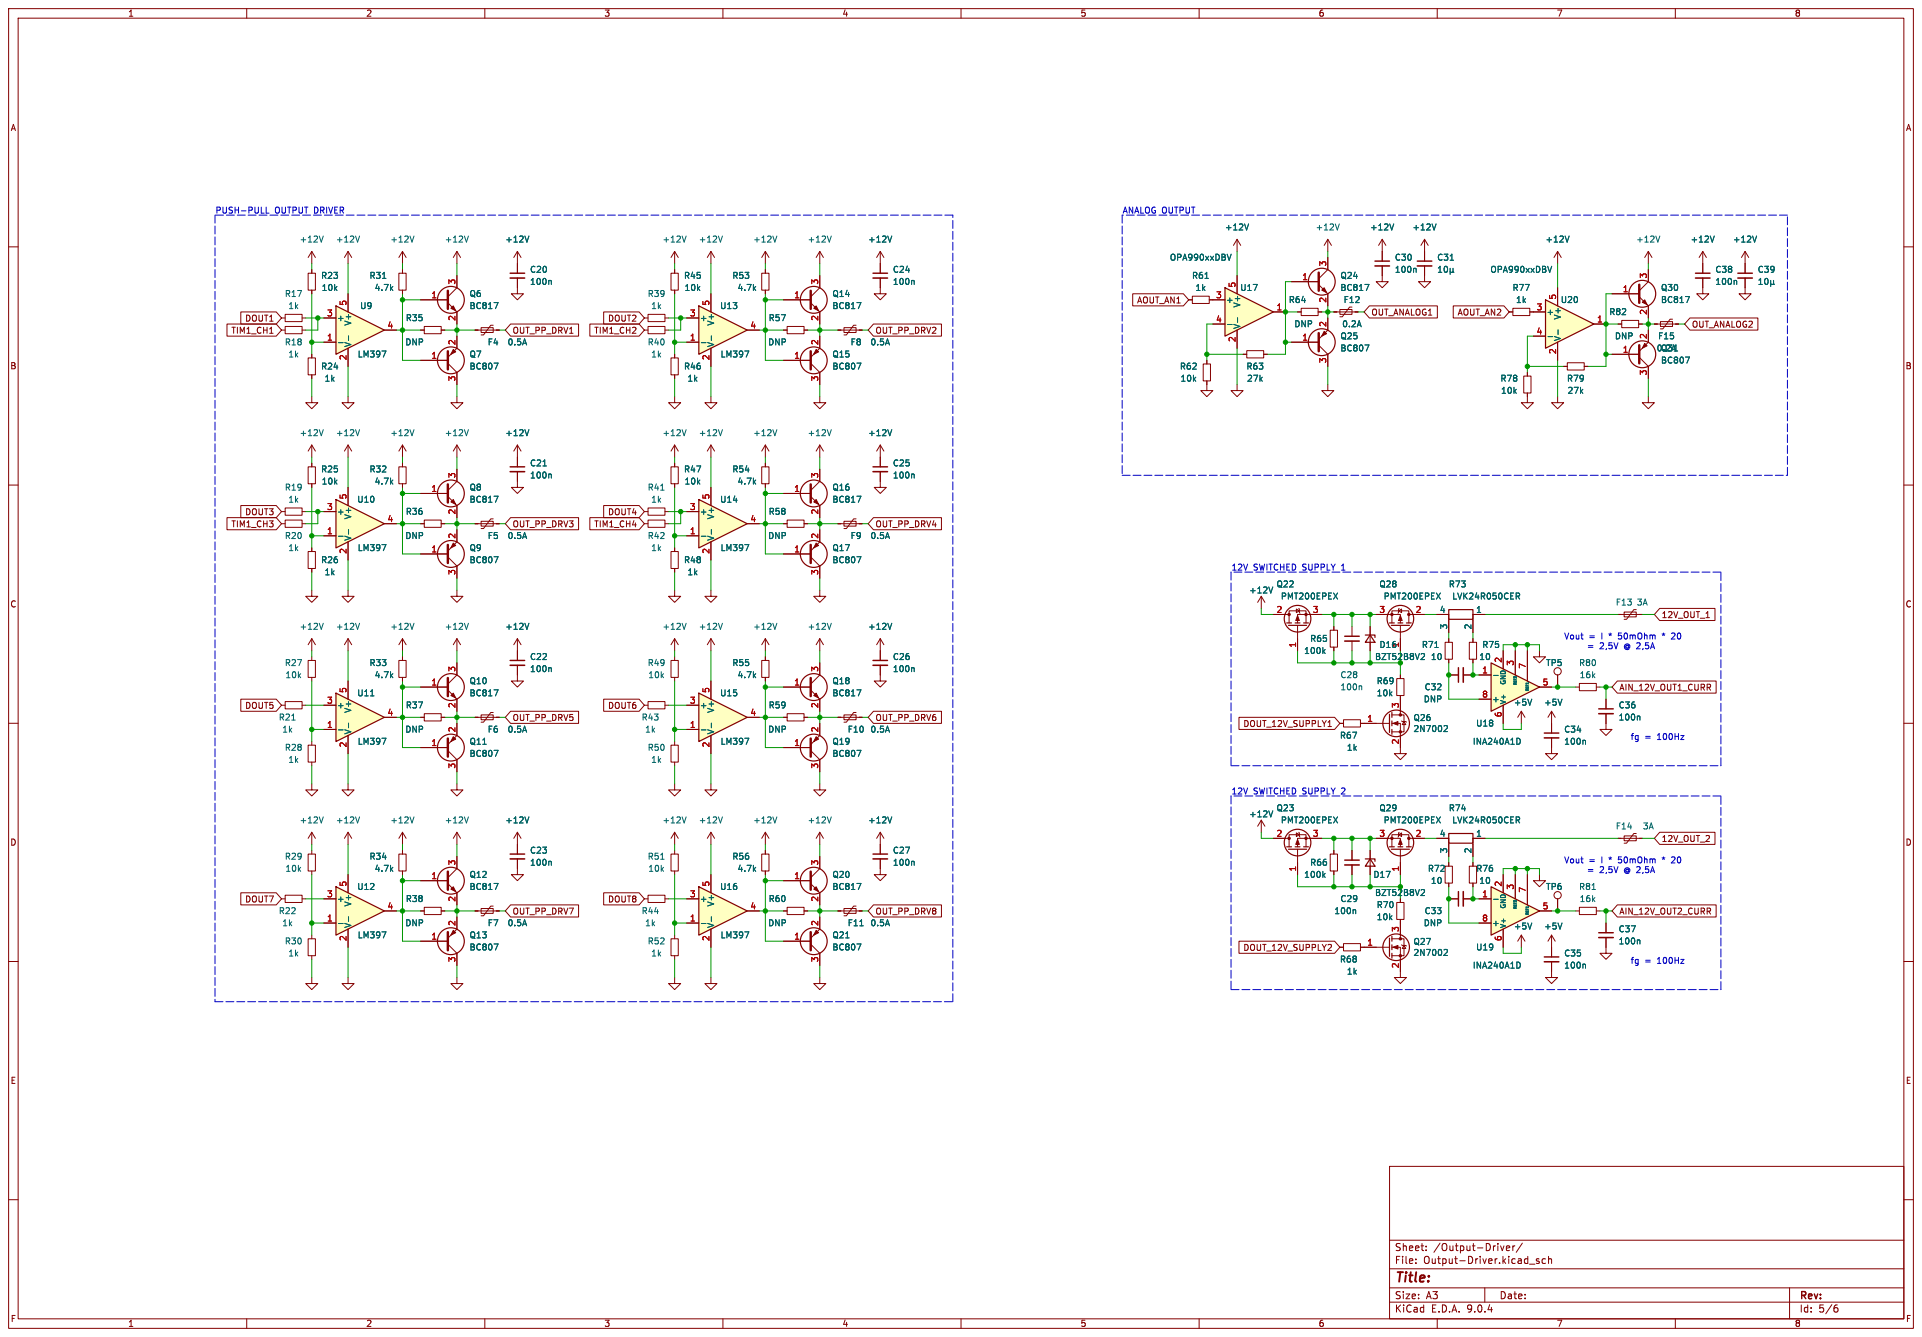
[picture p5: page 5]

Id: 5/6 Title: File: Output-Driver.kicad_sch Sheet: /Output-Driver/

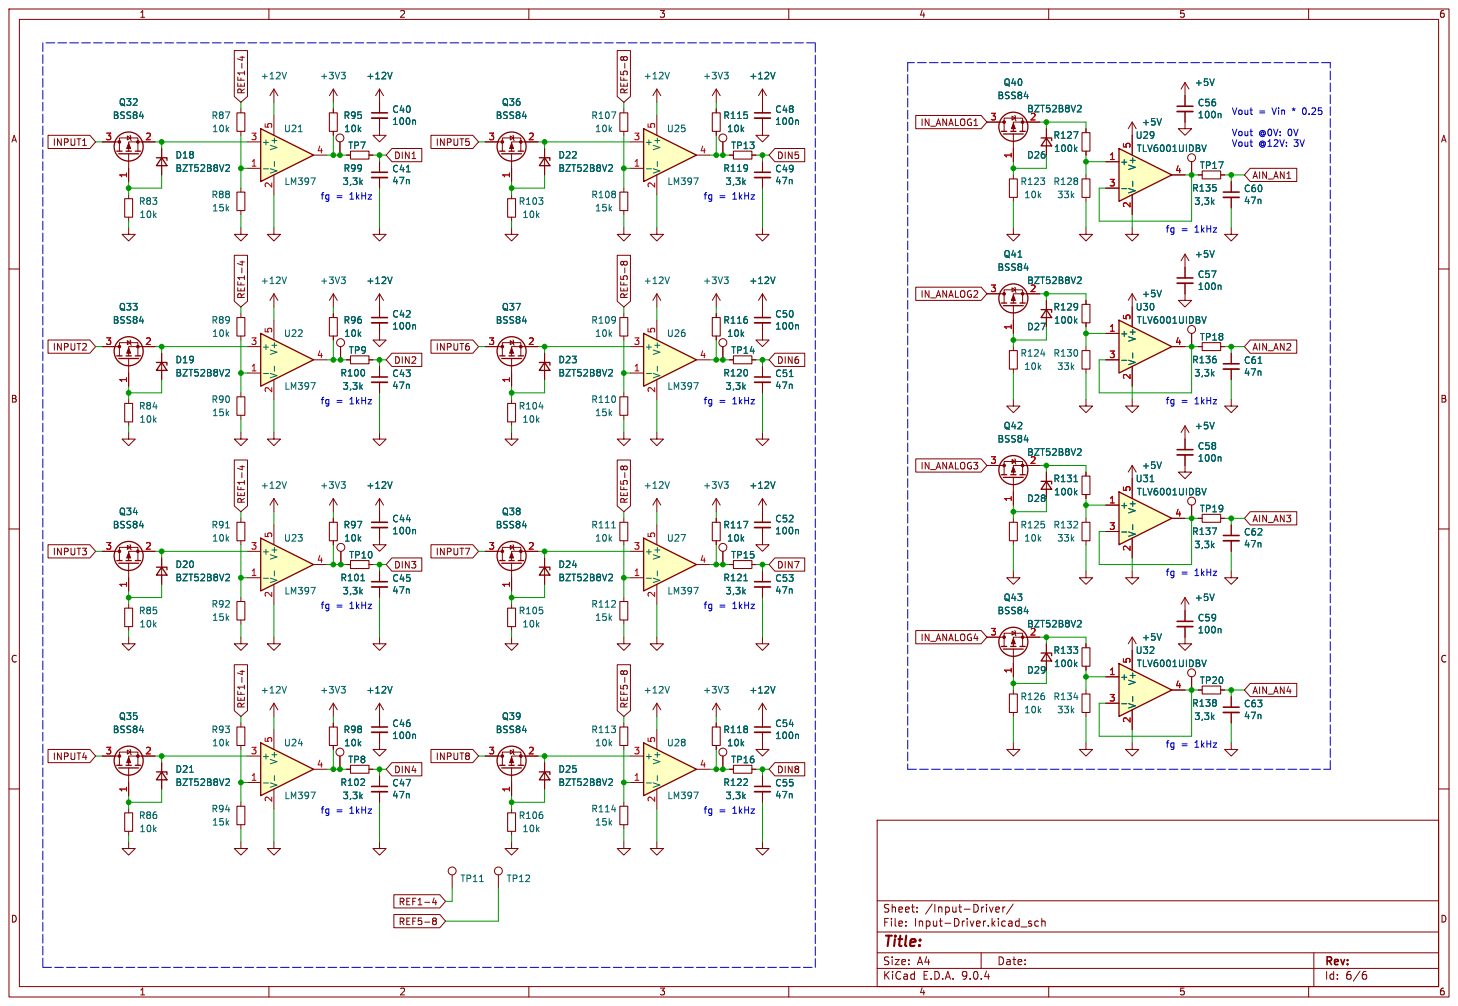
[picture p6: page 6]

Id: 6/6 Title: File: Input-Driver.kicad_sch Sheet: /Input-Driver/ R121

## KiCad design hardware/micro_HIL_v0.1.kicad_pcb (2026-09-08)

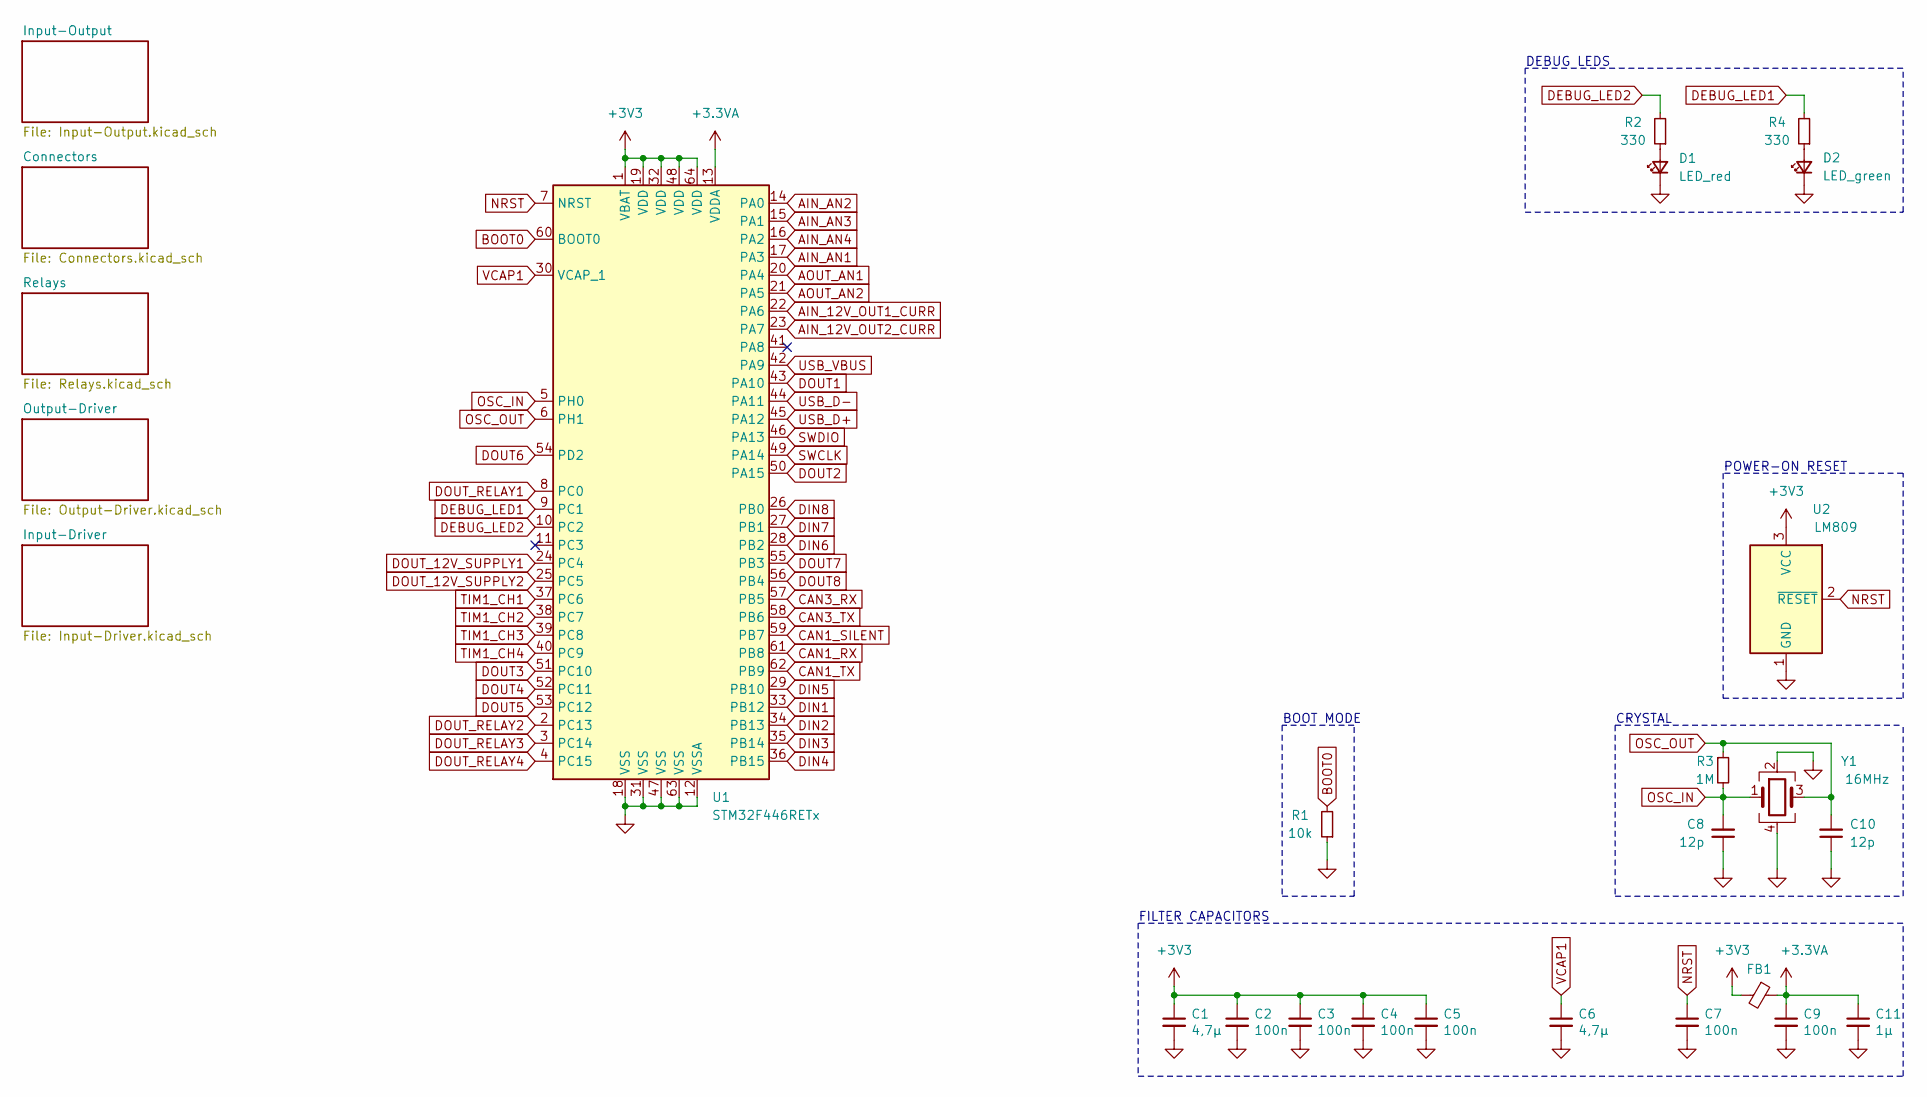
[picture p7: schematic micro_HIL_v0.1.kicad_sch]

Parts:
C1, C6: 4,7µ; C_0805_2012Metric
C2, C3, C4, C5, C7, C9: 100n; C_0603_1608Metric
C8, C10: 12p; C_0603_1608Metric
C11: 1µ; C_0603_1608Metric
D1: LED_red; LED_0805_2012Metric
D2: LED_green; LED_0805_2012Metric
FB1: Ferrite_Bead_Small; L_0805_2012Metric
R1: 10k; R_0603_1608Metric
R2, R4: 330; R_0603_1608Metric
R3: 1M; R_0603_1608Metric
U1: STM32F446RETx; LQFP-64_10x10mm_P0.5mm
U2: LM809; SOT-23
Y1: 16MHz; Crystal_SMD_3225-4Pin_3.2x2.5mm

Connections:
+3.3VA: C9.1, C11.1, FB1.1, U1.13 (VDDA)
+3V3: C1.1, C2.1, C3.1, C4.1, C5.1, FB1.2, U1.1 (VBAT), U1.19 (VDD), U1.32 (VDD), U1.48 (VDD), U1.64 (VDD), U2.3 (VCC); also elsewhere on the board
AIN_12V_OUT1_CURR: U1.22 (PA6); also elsewhere on the board
AIN_12V_OUT2_CURR: U1.23 (PA7); also elsewhere on the board
AIN_AN1: U1.17 (PA3); also elsewhere on the board
AIN_AN2: U1.14 (PA0); also elsewhere on the board
AIN_AN3: U1.15 (PA1); also elsewhere on the board
AIN_AN4: U1.16 (PA2); also elsewhere on the board
AOUT_AN1: U1.20 (PA4); also elsewhere on the board
AOUT_AN2: U1.21 (PA5); also elsewhere on the board
BOOT0: R1.2, U1.60 (BOOT0)
CAN1_RX: U1.61 (PB8); also elsewhere on the board
CAN1_SILENT: U1.59 (PB7); also elsewhere on the board
CAN1_TX: U1.62 (PB9); also elsewhere on the board
CAN3_RX: U1.57 (PB5); also elsewhere on the board
CAN3_TX: U1.58 (PB6); also elsewhere on the board
DEBUG_LED1: R4.2, U1.9 (PC1)
DEBUG_LED2: R2.2, U1.10 (PC2)
DIN1: U1.33 (PB12); also elsewhere on the board
DIN2: U1.34 (PB13); also elsewhere on the board
DIN3: U1.35 (PB14); also elsewhere on the board
DIN4: U1.36 (PB15); also elsewhere on the board
DIN5: U1.29 (PB10); also elsewhere on the board
DIN6: U1.28 (PB2); also elsewhere on the board
DIN7: U1.27 (PB1); also elsewhere on the board
DIN8: U1.26 (PB0); also elsewhere on the board
DOUT1: U1.43 (PA10); also elsewhere on the board
DOUT2: U1.50 (PA15); also elsewhere on the board
DOUT3: U1.51 (PC10); also elsewhere on the board
DOUT4: U1.52 (PC11); also elsewhere on the board
DOUT5: U1.53 (PC12); also elsewhere on the board
DOUT6: U1.54 (PD2); also elsewhere on the board
DOUT7: U1.55 (PB3); also elsewhere on the board
DOUT8: U1.56 (PB4); also elsewhere on the board
DOUT_12V_SUPPLY1: U1.24 (PC4); also elsewhere on the board
DOUT_12V_SUPPLY2: U1.25 (PC5); also elsewhere on the board
DOUT_RELAY1: U1.8 (PC0); also elsewhere on the board
DOUT_RELAY2: U1.2 (PC13); also elsewhere on the board
DOUT_RELAY3: U1.3 (PC14); also elsewhere on the board
DOUT_RELAY4: U1.4 (PC15); also elsewhere on the board
GND: C1.2, C2.2, C3.2, C4.2, C5.2, C6.2, C7.2, C8.1, C9.2, C10.1, C11.2, D1.1 (K), D2.1 (K), R1.1, U1.12 (VSSA), U1.18 (VSS), U1.31 (VSS), U1.47 (VSS), U1.63 (VSS), U2.1 (GND), Y1.2, Y1.4; also elsewhere on the board
NRST: C7.1, U1.7 (NRST), U2.2 (~RESET); also elsewhere on the board
unnamed: D1.2 (A), R2.1
unnamed: D2.2 (A), R4.1
OSC_IN: C8.2, R3.2, U1.5 (PH0), Y1.1
OSC_OUT: C10.2, R3.1, U1.6 (PH1), Y1.3
SWCLK: U1.49 (PA14); also elsewhere on the board
SWDIO: U1.46 (PA13); also elsewhere on the board
TIM1_CH1: U1.37 (PC6); also elsewhere on the board
TIM1_CH2: U1.38 (PC7); also elsewhere on the board
TIM1_CH3: U1.39 (PC8); also elsewhere on the board
TIM1_CH4: U1.40 (PC9); also elsewhere on the board
USB_D+: U1.45 (PA12); also elsewhere on the board
USB_D-: U1.44 (PA11); also elsewhere on the board
USB_VBUS: U1.42 (PA9); also elsewhere on the board
VCAP1: C6.1, U1.30 (VCAP_1)

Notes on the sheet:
POWER-ON RESET
BOOT MODE
DEBUG LEDS
FILTER CAPACITORS
CRYSTAL

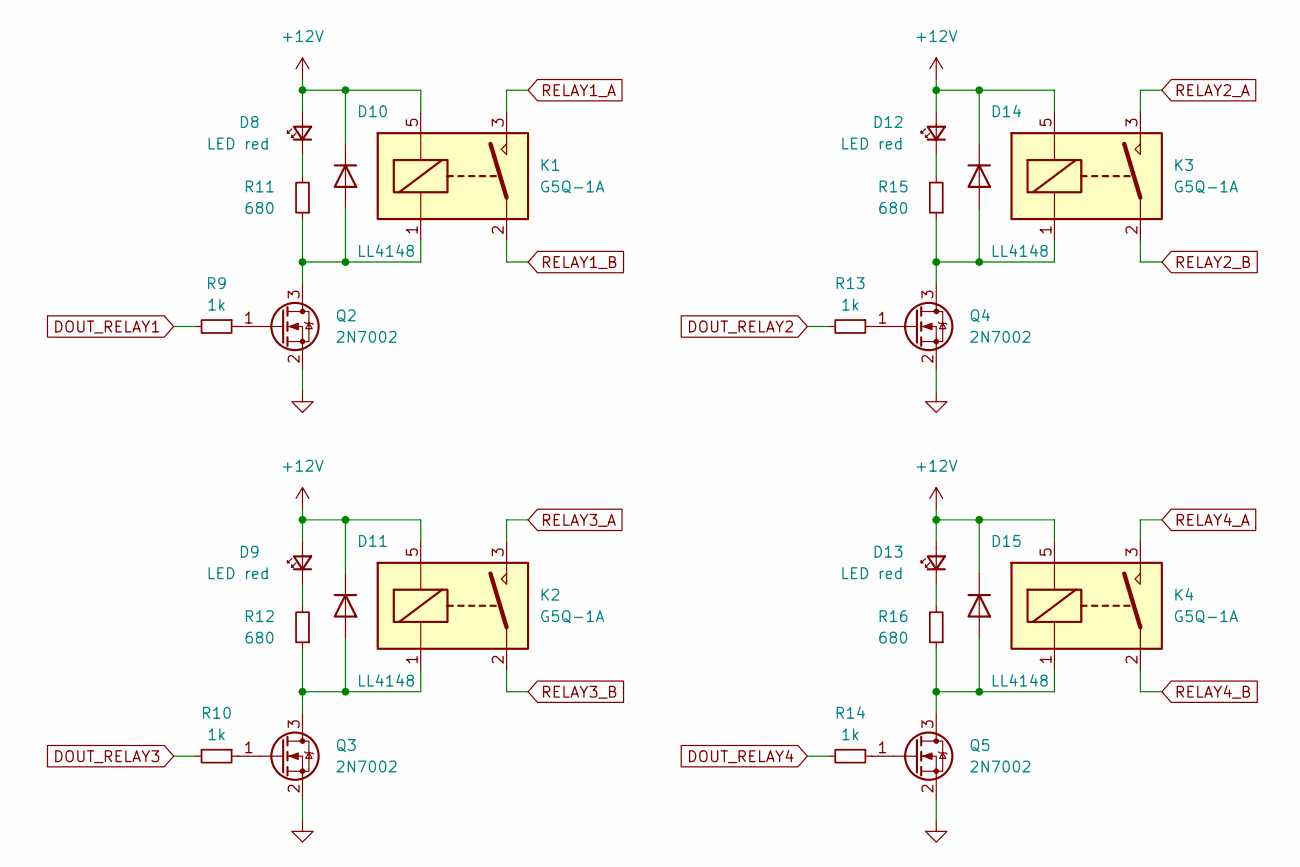
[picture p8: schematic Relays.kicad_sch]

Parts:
D8, D9, D12, D13: LED red; LED_D5.0mm
D10, D11, D14, D15: LL4148; D_MiniMELF
K1, K2, K3, K4: G5Q-1A; Relay_SPST_Omron-G5Q-1A
Q2, Q3, Q4, Q5: 2N7002; SOT-23
R9, R10, R13, R14: 1k; R_0603_1608Metric
R11, R12, R15, R16: 680; R_0603_1608Metric

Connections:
+12V: D8.2 (A), D9.2 (A), D10.1 (K), D11.1 (K), D12.2 (A), D13.2 (A), D14.1 (K), D15.1 (K), K1.5, K2.5, K3.5, K4.5; also elsewhere on the board
DOUT_RELAY1: R9.2; also elsewhere on the board
DOUT_RELAY2: R13.2; also elsewhere on the board
DOUT_RELAY3: R10.2; also elsewhere on the board
DOUT_RELAY4: R14.2; also elsewhere on the board
GND: Q2.2 (S), Q3.2 (S), Q4.2 (S), Q5.2 (S); also elsewhere on the board
unnamed: D8.1 (K), R11.2
unnamed: D9.1 (K), R12.2
unnamed: D10.2 (A), K1.1, Q2.3 (D), R11.1
unnamed: D11.2 (A), K2.1, Q3.3 (D), R12.1
unnamed: D12.1 (K), R15.2
unnamed: D13.1 (K), R16.2
unnamed: D14.2 (A), K3.1, Q4.3 (D), R15.1
unnamed: D15.2 (A), K4.1, Q5.3 (D), R16.1
unnamed: Q2.1 (G), R9.1
unnamed: Q3.1 (G), R10.1
unnamed: Q4.1 (G), R13.1
unnamed: Q5.1 (G), R14.1
RELAY1_A: K1.3; also elsewhere on the board
RELAY1_B: K1.2; also elsewhere on the board
RELAY2_A: K3.3; also elsewhere on the board
RELAY2_B: K3.2; also elsewhere on the board
RELAY3_A: K2.3; also elsewhere on the board
RELAY3_B: K2.2; also elsewhere on the board
RELAY4_A: K4.3; also elsewhere on the board
RELAY4_B: K4.2; also elsewhere on the board

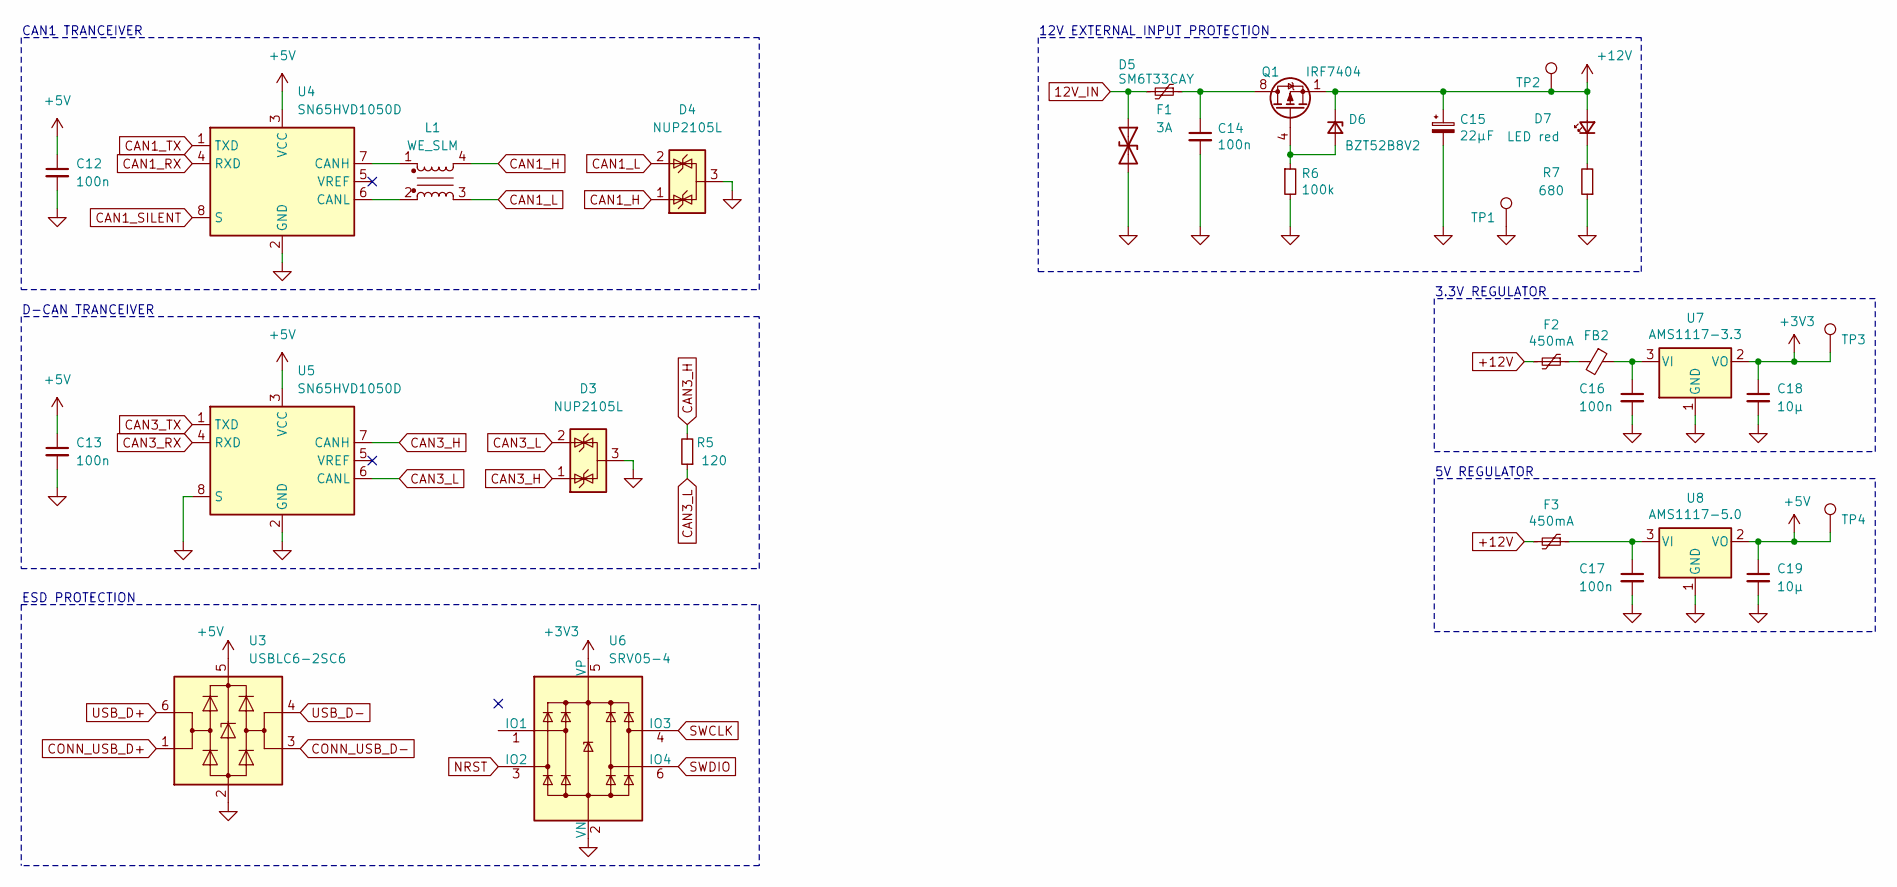
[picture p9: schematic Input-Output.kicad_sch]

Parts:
C12, C13, C14, C16, C17: 100n; C_0603_1608Metric
C15: 22µF; CP_Elec_6.3x5.9
C18, C19: 10µ; C_0805_2012Metric
D3, D4: NUP2105L; SOT-23
D5: SM6T33CAY; D_SMB_Handsoldering
D6: BZT52B8V2; D_SOD-123
D7: LED red; LED_D5.0mm
F1: 3A; Fuse_1812_4532Metric
F2, F3: 450mA; Fuse_1210_3225Metric
FB2: Ferrite_Bead_Small; L_0805_2012Metric
L1: WE_SLM; L_CommonMode_Wuerth_WE-SLM
Q1: IRF7404; SOIC-8_3.9x4.9mm_P1.27mm
R5: 120; R_0603_1608Metric
R6: 100k; R_0603_1608Metric
R7: 680; R_0603_1608Metric
TP1: TestPoint; Pin_D1.1mm_L8.5mm_W2.5mm_FlatFork
TP2, TP3, TP4: TestPoint; TestPoint_Pad_D1.0mm
U3: USBLC6-2SC6; SOT-23-6
U4, U5: SN65HVD1050D; SOIC-8_3.9x4.9mm_P1.27mm
U6: SRV05-4; SOT-23-6
U7: AMS1117-3.3; SOT-223-3_TabPin2
U8: AMS1117-5.0; SOT-223-3_TabPin2

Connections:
12V_IN: D5.1 (A1), F1.2; also elsewhere on the board
+3V3: C18.1, TP3.1, U6.5 (VP), U7.2 (VO); also elsewhere on the board
+5V: C12.1, C13.1, C19.1, TP4.1, U3.5 (VBUS), U4.3 (VCC), U5.3 (VCC), U8.2 (VO); also elsewhere on the board
+12V: C15.1, D6.1 (K), D7.2 (A), F2.2, F3.2, Q1.1 (S), Q1.2 (S), Q1.3 (S), TP2.1; also elsewhere on the board
CAN1_H: D4.1 (K), L1.4; also elsewhere on the board
CAN1_L: D4.2 (K), L1.3; also elsewhere on the board
CAN1_RX: U4.4 (RXD); also elsewhere on the board
CAN1_SILENT: U4.8 (S); also elsewhere on the board
CAN1_TX: U4.1 (TXD); also elsewhere on the board
CAN3_H: D3.1 (K), R5.2, U5.7 (CANH); also elsewhere on the board
CAN3_L: D3.2 (K), R5.1, U5.6 (CANL); also elsewhere on the board
CAN3_RX: U5.4 (RXD); also elsewhere on the board
CAN3_TX: U5.1 (TXD); also elsewhere on the board
CONN_USB_D+: U3.1 (I/O1); also elsewhere on the board
CONN_USB_D-: U3.3 (I/O2); also elsewhere on the board
GND: C12.2, C13.2, C14.2, C15.2, C16.2, C17.2, C18.2, C19.2, D3.3 (A), D4.3 (A), D5.2 (A2), R6.2, R7.1, TP1.1, U3.2 (GND), U4.2 (GND), U5.2 (GND), U5.8 (S), U6.2 (VN), U7.1 (GND), U8.1 (GND); also elsewhere on the board
NRST: U6.3 (IO2); also elsewhere on the board
unnamed: C14.1, F1.1, Q1.5 (D), Q1.6 (D), Q1.7 (D), Q1.8 (D)
unnamed: C16.1, FB2.1, U7.3 (VI)
unnamed: C17.1, F3.1, U8.3 (VI)
unnamed: D6.2 (A), Q1.4 (G), R6.1
unnamed: D7.1 (K), R7.2
unnamed: F2.1, FB2.2
unnamed: L1.1, U4.7 (CANH)
unnamed: L1.2, U4.6 (CANL)
SWCLK: U6.4 (IO3); also elsewhere on the board
SWDIO: U6.6 (IO4); also elsewhere on the board
USB_D+: U3.6 (I/O1); also elsewhere on the board
USB_D-: U3.4 (I/O2); also elsewhere on the board

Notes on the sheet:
12V EXTERNAL INPUT PROTECTION
5V REGULATOR
3.3V REGULATOR
D-CAN TRANCEIVER
CAN1 TRANCEIVER
ESD PROTECTION

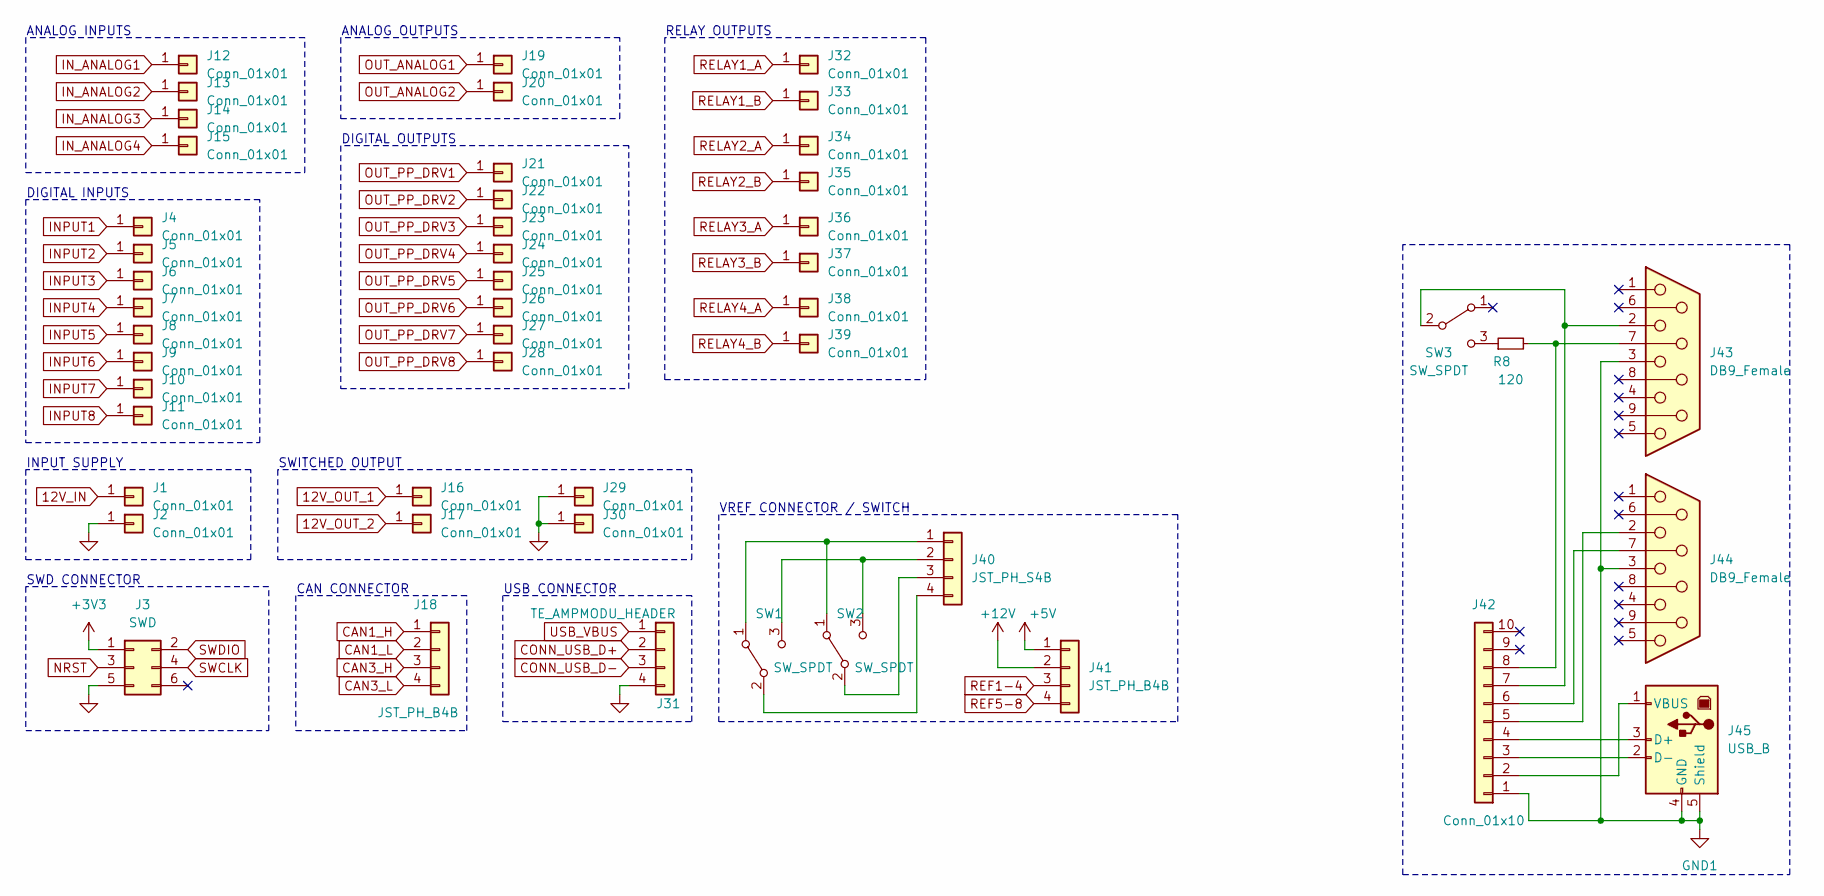
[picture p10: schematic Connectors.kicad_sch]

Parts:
J1, J2, J4, J5, J6, J7, J8, J9, J10, J11, J12, J13, J14, J15, J16, J17, J19, J20, J21, J22, J23, J24, J25, J26, J27, J28, J29, J30, J32, J33, J34, J35, J36, J37, J38, J39: Conn_01x01; Hirschmann_SEP_2630_S1,9
J3: SWD; IDC-Header_2x03_P2.54mm_Vertical
J18, J41: JST_PH_B4B; JST_PH_B4B-PH-K_1x04_P2.00mm_Vertical
J31: TE_AMPMODU_HEADER; PinHeader_1x04_P2.54mm_Vertical
J40: JST_PH_S4B; JST_PH_S4B-PH-K_1x04_P2.00mm_Horizontal
J42: Conn_01x10; TE_3-1445056-0
J43, J44: DB9_Female; DSUB-9_Female_Vertical_P2.77x2.84mm_MountingHoles
J45: USB_B; USB_B_TE_5787834_Vertical
R8: 120; R_0603_1608Metric
SW1, SW2, SW3: SW_SPDT; TerminalBlock_bornier-3_P5.08mm

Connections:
12V_IN: J1.1; also elsewhere on the board
12V_OUT_1: J16.1; also elsewhere on the board
12V_OUT_2: J17.1; also elsewhere on the board
+3V3: J3.1; also elsewhere on the board
+5V: J41.1; also elsewhere on the board
+12V: J41.2; also elsewhere on the board
CAN1_H: J18.1; also elsewhere on the board
CAN1_L: J18.2; also elsewhere on the board
CAN3_H: J18.3; also elsewhere on the board
CAN3_L: J18.4; also elsewhere on the board
CONN_USB_D+: J31.2; also elsewhere on the board
CONN_USB_D-: J31.3; also elsewhere on the board
GND: J2.1, J3.5, J29.1, J30.1, J31.4; also elsewhere on the board
GND1: J42.1, J43.3, J44.3, J45.4 (GND), J45.5 (Shield)
INPUT1: J4.1; also elsewhere on the board
INPUT2: J5.1; also elsewhere on the board
INPUT3: J6.1; also elsewhere on the board
INPUT4: J7.1; also elsewhere on the board
INPUT5: J8.1; also elsewhere on the board
INPUT6: J9.1; also elsewhere on the board
INPUT7: J10.1; also elsewhere on the board
INPUT8: J11.1; also elsewhere on the board
IN_ANALOG1: J12.1; also elsewhere on the board
IN_ANALOG2: J13.1; also elsewhere on the board
IN_ANALOG3: J14.1; also elsewhere on the board
IN_ANALOG4: J15.1; also elsewhere on the board
NRST: J3.3; also elsewhere on the board
unnamed: J40.1, SW1.1 (A), SW2.1 (A)
unnamed: J40.2, SW1.3 (C), SW2.3 (C)
unnamed: J40.3, SW2.2 (B)
unnamed: J40.4, SW1.2 (B)
unnamed: J42.2, J45.1 (VBUS)
unnamed: J42.3, J45.2 (D-)
unnamed: J42.4, J45.3 (D+)
unnamed: J42.5, J44.2
unnamed: J42.6, J44.7
unnamed: J42.7, J43.2, SW3.2 (B)
unnamed: J42.8, J43.7, R8.2
unnamed: R8.1, SW3.3 (C)
OUT_ANALOG1: J19.1; also elsewhere on the board
OUT_ANALOG2: J20.1; also elsewhere on the board
OUT_PP_DRV1: J21.1; also elsewhere on the board
OUT_PP_DRV2: J22.1; also elsewhere on the board
OUT_PP_DRV3: J23.1; also elsewhere on the board
OUT_PP_DRV4: J24.1; also elsewhere on the board
OUT_PP_DRV5: J25.1; also elsewhere on the board
OUT_PP_DRV6: J26.1; also elsewhere on the board
OUT_PP_DRV7: J27.1; also elsewhere on the board
OUT_PP_DRV8: J28.1; also elsewhere on the board
REF1-4: J41.3; also elsewhere on the board
REF5-8: J41.4; also elsewhere on the board
RELAY1_A: J32.1; also elsewhere on the board
RELAY1_B: J33.1; also elsewhere on the board
RELAY2_A: J34.1; also elsewhere on the board
RELAY2_B: J35.1; also elsewhere on the board
RELAY3_A: J36.1; also elsewhere on the board
RELAY3_B: J37.1; also elsewhere on the board
RELAY4_A: J38.1; also elsewhere on the board
RELAY4_B: J39.1; also elsewhere on the board
SWCLK: J3.4; also elsewhere on the board
SWDIO: J3.2; also elsewhere on the board
USB_VBUS: J31.1; also elsewhere on the board

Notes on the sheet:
ANALOG OUTPUTS
RELAY OUTPUTS
SWD CONNECTOR
DIGITAL INPUTS
USB CONNECTOR
ANALOG INPUTS
SWITCHED OUTPUT
CAN CONNECTOR
VREF CONNECTOR / SWITCH
DIGITAL OUTPUTS
INPUT SUPPLY

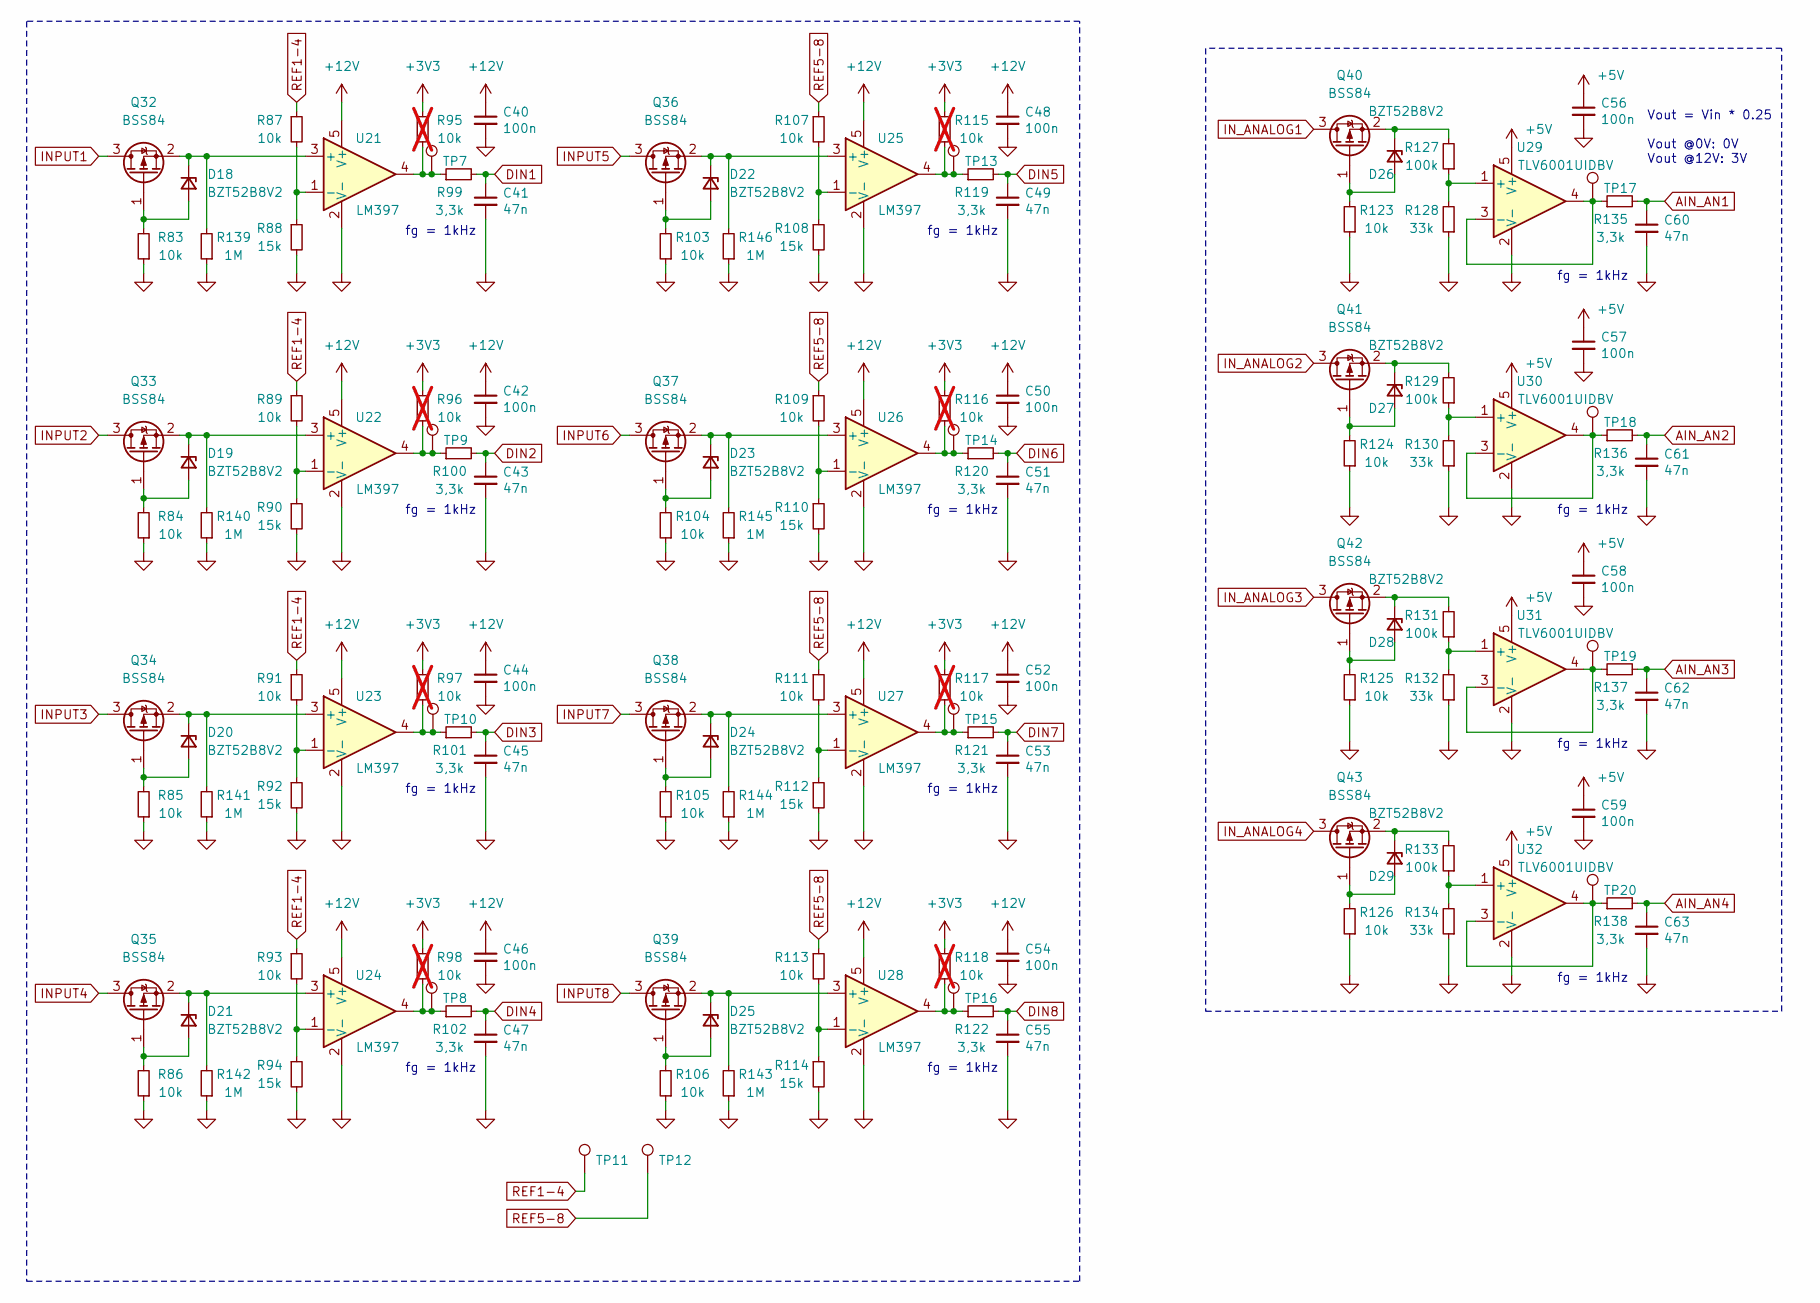
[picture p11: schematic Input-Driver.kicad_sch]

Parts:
C40, C42, C44, C46, C48, C50, C52, C54, C56, C57, C58, C59: 100n; C_0603_1608Metric
C41, C43, C45, C47, C49, C51, C53, C55, C60, C61, C62, C63: 47n; C_0603_1608Metric
D18, D19, D20, D21, D22, D23, D24, D25, D26, D27, D28, D29: BZT52B8V2; D_SOD-123
Q32, Q33, Q34, Q35, Q36, Q37, Q38, Q39, Q40, Q41, Q42, Q43: BSS84; SOT-23
R83, R84, R85, R86, R87, R89, R91, R93, R103, R104, R105, R106, R107, R109, R111, R113, R123, R124, R125, R126: 10k; R_0603_1608Metric
R88, R90, R92, R94, R108, R110, R112, R114: 15k; R_0603_1608Metric
R95, R96, R97, R98, R115, R116, R117, R118: 10k; R_0603_1608Metric; not fitted
R99, R100, R101, R102, R119, R120, R121, R122, R135, R136, R137, R138: 3,3k; R_0603_1608Metric
R127, R129, R131, R133: 100k; R_0603_1608Metric
R128, R130, R132, R134: 33k; R_0603_1608Metric
R139, R140, R141, R142, R143, R144, R145, R146: 1M; R_0603_1608Metric
TP7, TP8, TP9, TP10, TP11, TP12, TP13, TP14, TP15, TP16, TP17, TP18, TP19, TP20: TestPoint; TestPoint_Pad_D1.0mm
U21, U22, U23, U24, U25, U26, U27, U28: LM397; SOT-23-5
U29, U30, U31, U32: TLV6001UIDBV; SOT-23-5

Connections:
+3V3: R95.2, R96.2, R97.2, R98.2, R115.2, R116.2, R117.2, R118.2; also elsewhere on the board
+5V: C56.1, C57.1, C58.1, C59.1, U29.5 (V+), U30.5 (V+), U31.5 (V+), U32.5 (V+); also elsewhere on the board
+12V: C40.1, C42.1, C44.1, C46.1, C48.1, C50.1, C52.1, C54.1, U21.5 (V+), U22.5 (V+), U23.5 (V+), U24.5 (V+), U25.5 (V+), U26.5 (V+), U27.5 (V+), U28.5 (V+); also elsewhere on the board
AIN_AN1: C60.1, R135.2; also elsewhere on the board
AIN_AN2: C61.1, R136.2; also elsewhere on the board
AIN_AN3: C62.1, R137.2; also elsewhere on the board
AIN_AN4: C63.1, R138.2; also elsewhere on the board
DIN1: C41.1, R99.2; also elsewhere on the board
DIN2: C43.1, R100.2; also elsewhere on the board
DIN3: C45.1, R101.2; also elsewhere on the board
DIN4: C47.1, R102.2; also elsewhere on the board
DIN5: C49.1, R119.2; also elsewhere on the board
DIN6: C51.1, R120.2; also elsewhere on the board
DIN7: C53.1, R121.2; also elsewhere on the board
DIN8: C55.1, R122.2; also elsewhere on the board
GND: C40.2, C41.2, C42.2, C43.2, C44.2, C45.2, C46.2, C47.2, C48.2, C49.2, C50.2, C51.2, C52.2, C53.2, C54.2, C55.2, C56.2, C57.2, C58.2, C59.2, C60.2, C61.2, C62.2, C63.2, R83.1, R84.1, R85.1, R86.1, R88.2, R90.2, R92.2, R94.2, R103.1, R104.1, R105.1, R106.1, R108.2, R110.2, R112.2, R114.2, R123.1, R124.1, R125.1, R126.1, R128.1, R130.1, R132.1, R134.1, R139.1, R140.1, R141.1, R142.1, R143.1, R144.1, R145.1, R146.1, U21.2 (V-), U22.2 (V-), U23.2 (V-), U24.2 (V-), U25.2 (V-), U26.2 (V-), U27.2 (V-), U28.2 (V-), U29.2 (V-), U30.2 (V-), U31.2 (V-), U32.2 (V-); also elsewhere on the board
INPUT1: Q32.3 (D); also elsewhere on the board
INPUT2: Q33.3 (D); also elsewhere on the board
INPUT3: Q34.3 (D); also elsewhere on the board
INPUT4: Q35.3 (D); also elsewhere on the board
INPUT5: Q36.3 (D); also elsewhere on the board
INPUT6: Q37.3 (D); also elsewhere on the board
INPUT7: Q38.3 (D); also elsewhere on the board
INPUT8: Q39.3 (D); also elsewhere on the board
IN_ANALOG1: Q40.3 (D); also elsewhere on the board
IN_ANALOG2: Q41.3 (D); also elsewhere on the board
IN_ANALOG3: Q42.3 (D); also elsewhere on the board
IN_ANALOG4: Q43.3 (D); also elsewhere on the board
unnamed: D18.1 (K), Q32.2 (S), R139.2, U21.3 (+)
unnamed: D18.2 (A), Q32.1 (G), R83.2
unnamed: D19.1 (K), Q33.2 (S), R140.2, U22.3 (+)
unnamed: D19.2 (A), Q33.1 (G), R84.2
unnamed: D20.1 (K), Q34.2 (S), R141.2, U23.3 (+)
unnamed: D20.2 (A), Q34.1 (G), R85.2
unnamed: D21.1 (K), Q35.2 (S), R142.2, U24.3 (+)
unnamed: D21.2 (A), Q35.1 (G), R86.2
unnamed: D22.1 (K), Q36.2 (S), R146.2, U25.3 (+)
unnamed: D22.2 (A), Q36.1 (G), R103.2
unnamed: D23.1 (K), Q37.2 (S), R145.2, U26.3 (+)
unnamed: D23.2 (A), Q37.1 (G), R104.2
unnamed: D24.1 (K), Q38.2 (S), R144.2, U27.3 (+)
unnamed: D24.2 (A), Q38.1 (G), R105.2
unnamed: D25.1 (K), Q39.2 (S), R143.2, U28.3 (+)
unnamed: D25.2 (A), Q39.1 (G), R106.2
unnamed: D26.1 (K), Q40.2 (S), R127.2
unnamed: D26.2 (A), Q40.1 (G), R123.2
unnamed: D27.1 (K), Q41.2 (S), R129.2
unnamed: D27.2 (A), Q41.1 (G), R124.2
unnamed: D28.1 (K), Q42.2 (S), R131.2
unnamed: D28.2 (A), Q42.1 (G), R125.2
unnamed: D29.1 (K), Q43.2 (S), R133.2
unnamed: D29.2 (A), Q43.1 (G), R126.2
unnamed: R87.2, R88.1, U21.1 (-)
unnamed: R89.2, R90.1, U22.1 (-)
unnamed: R91.2, R92.1, U23.1 (-)
unnamed: R93.2, R94.1, U24.1 (-)
unnamed: R95.1, R99.1, TP7.1, U21.4
unnamed: R96.1, R100.1, TP9.1, U22.4
unnamed: R97.1, R101.1, TP10.1, U23.4
unnamed: R98.1, R102.1, TP8.1, U24.4
unnamed: R107.2, R108.1, U25.1 (-)
unnamed: R109.2, R110.1, U26.1 (-)
unnamed: R111.2, R112.1, U27.1 (-)
unnamed: R113.2, R114.1, U28.1 (-)
unnamed: R115.1, R119.1, TP13.1, U25.4
unnamed: R116.1, R120.1, TP14.1, U26.4
unnamed: R117.1, R121.1, TP15.1, U27.4
unnamed: R118.1, R122.1, TP16.1, U28.4
unnamed: R127.1, R128.2, U29.1 (+)
unnamed: R129.1, R130.2, U30.1 (+)
unnamed: R131.1, R132.2, U31.1 (+)
unnamed: R133.1, R134.2, U32.1 (+)
unnamed: R135.1, TP17.1, U29.3 (-), U29.4
unnamed: R136.1, TP18.1, U30.3 (-), U30.4
unnamed: R137.1, TP19.1, U31.3 (-), U31.4
unnamed: R138.1, TP20.1, U32.3 (-), U32.4
REF1-4: R87.1, R89.1, R91.1, R93.1, TP11.1; also elsewhere on the board
REF5-8: R107.1, R109.1, R111.1, R113.1, TP12.1; also elsewhere on the board

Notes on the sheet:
fg = 1kHz
Vout = Vin * 0.25 Vout @0V: 0V Vout @12V: 3V

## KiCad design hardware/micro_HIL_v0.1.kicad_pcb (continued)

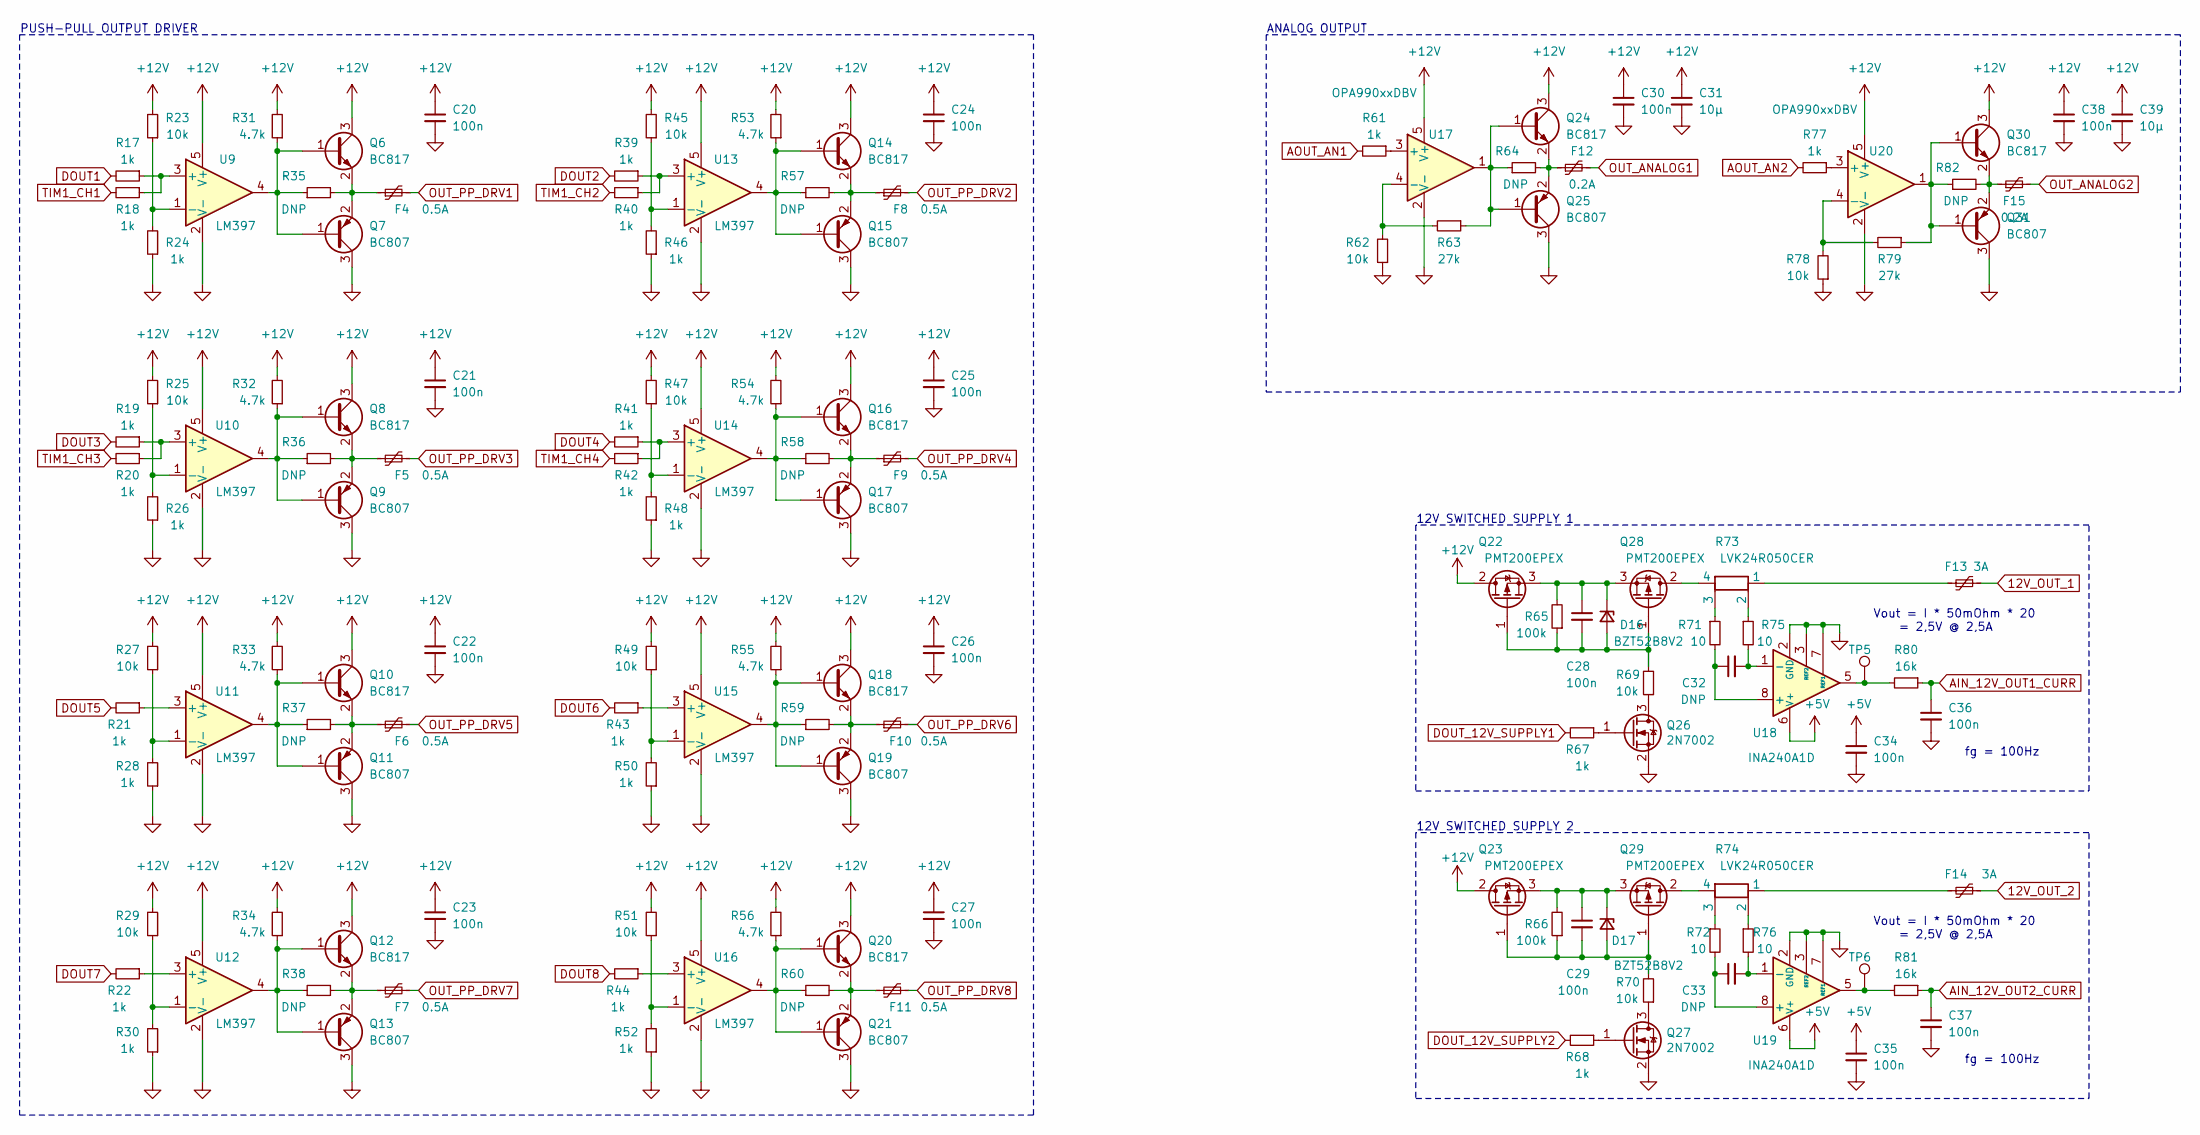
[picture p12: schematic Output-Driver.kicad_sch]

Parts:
C20, C21, C22, C23, C24, C25, C26, C27, C28, C29, C30, C34, C35, C36, C37, C38: 100n; C_0603_1608Metric
C31, C39: 10µ; C_0805_2012Metric
C32, C33: DNP; C_0603_1608Metric
D16, D17: BZT52B8V2; D_SOD-123
F4, F5, F6, F7, F8, F9, F10, F11: 0.5A; Fuse_1210_3225Metric
F12, F15: 0.2A; Fuse_1210_3225Metric
F13, F14: 3A; Fuse_1812_4532Metric
Q6, Q8, Q10, Q12, Q14, Q16, Q18, Q20, Q24, Q30: BC817; SOT-23
Q7, Q9, Q11, Q13, Q15, Q17, Q19, Q21, Q25, Q31: BC807; SOT-23
Q22, Q23, Q28, Q29: PMT200EPEX; SOT-223-3_TabPin2
Q26, Q27: 2N7002; SOT-23
R17, R18, R19, R20, R21, R22, R24, R26, R28, R30, R39, R40, R41, R42, R43, R44, R46, R48, R50, R52, R61, R67, R68, R77: 1k; R_0603_1608Metric
R23, R25, R27, R29, R45, R47, R49, R51, R62, R69, R70, R78: 10k; R_0603_1608Metric
R31, R32, R33, R34, R53, R54, R55, R56: 4.7k; R_0603_1608Metric
R35, R36, R37, R38, R57, R58, R59, R60, R64, R82: DNP; R_0603_1608Metric
R63, R79: 27k; R_0603_1608Metric
R65, R66: 100k; R_0603_1608Metric
R71, R72, R75, R76: 10; R_0603_1608Metric
R73, R74: LVK24R050CER; R_Shunt_Ohmite_LVK24
R80, R81: 16k; R_0603_1608Metric
TP5, TP6: TestPoint; TestPoint_Pad_D1.0mm
U9, U10, U11, U12, U13, U14, U15, U16: LM397; SOT-23-5
U17, U20: OPA990xxDBV; SOT-23-5
U18, U19: INA240A1D; SOIC-8_3.9x4.9mm_P1.27mm

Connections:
12V_OUT_1: F13.1; also elsewhere on the board
12V_OUT_2: F14.1; also elsewhere on the board
+5V: C34.1, C35.1, U18.6 (V+), U19.6 (V+); also elsewhere on the board
+12V: C20.1, C21.1, C22.1, C23.1, C24.1, C25.1, C26.1, C27.1, C30.1, C31.1, C38.1, C39.1, Q6.3 (C), Q8.3 (C), Q10.3 (C), Q12.3 (C), Q14.3 (C), Q16.3 (C), Q18.3 (C), Q20.3 (C), Q22.2 (D), Q23.2 (D), Q24.3 (C), Q30.3 (C), R23.2, R25.2, R27.2, R29.2, R31.2, R32.2, R33.2, R34.2, R45.2, R47.2, R49.2, R51.2, R53.2, R54.2, R55.2, R56.2, U9.5 (V+), U10.5 (V+), U11.5 (V+), U12.5 (V+), U13.5 (V+), U14.5 (V+), U15.5 (V+), U16.5 (V+), U17.5 (V+), U20.5 (V+); also elsewhere on the board
AIN_12V_OUT1_CURR: C36.1, R80.1; also elsewhere on the board
AIN_12V_OUT2_CURR: C37.1, R81.1; also elsewhere on the board
AOUT_AN1: R61.2; also elsewhere on the board
AOUT_AN2: R77.2; also elsewhere on the board
DOUT1: R17.2; also elsewhere on the board
DOUT2: R39.2; also elsewhere on the board
DOUT3: R19.2; also elsewhere on the board
DOUT4: R41.2; also elsewhere on the board
DOUT5: R21.2; also elsewhere on the board
DOUT6: R43.2; also elsewhere on the board
DOUT7: R22.2; also elsewhere on the board
DOUT8: R44.2; also elsewhere on the board
DOUT_12V_SUPPLY1: R67.2; also elsewhere on the board
DOUT_12V_SUPPLY2: R68.2; also elsewhere on the board
GND: C20.2, C21.2, C22.2, C23.2, C24.2, C25.2, C26.2, C27.2, C30.2, C31.2, C34.2, C35.2, C36.2, C37.2, C38.2, C39.2, Q7.3 (C), Q9.3 (C), Q11.3 (C), Q13.3 (C), Q15.3 (C), Q17.3 (C), Q19.3 (C), Q21.3 (C), Q25.3 (C), Q26.2 (S), Q27.2 (S), Q31.3 (C), R24.1, R26.1, R28.1, R30.1, R46.1, R48.1, R50.1, R52.1, R62.1, R78.1, U9.2 (V-), U10.2 (V-), U11.2 (V-), U12.2 (V-), U13.2 (V-), U14.2 (V-), U15.2 (V-), U16.2 (V-), U17.2 (V-), U18.2 (GND), U18.3 (REF2), U18.4 (GND), U18.7 (REF1), U19.2 (GND), U19.3 (REF2), U19.4 (GND), U19.7 (REF1), U20.2 (V-); also elsewhere on the board
unnamed: C28.1, D16.1 (K), Q22.3 (S), Q28.3 (S), R65.2
unnamed: C28.2, D16.2 (A), Q22.1 (G), Q28.1 (G), R65.1, R69.2
unnamed: C29.1, D17.1 (K), Q23.3 (S), Q29.3 (S), R66.2
unnamed: C29.2, D17.2 (A), Q23.1 (G), Q29.1 (G), R66.1, R70.2
unnamed: C32.1, R71.2, U18.8 (+)
unnamed: C32.2, R75.2, U18.1 (-)
unnamed: C33.1, R72.2, U19.8 (+)
unnamed: C33.2, R76.2, U19.1 (-)
unnamed: F4.1, Q6.2 (E), Q7.2 (E), R35.2
unnamed: F5.1, Q8.2 (E), Q9.2 (E), R36.2
unnamed: F6.1, Q10.2 (E), Q11.2 (E), R37.2
unnamed: F7.1, Q12.2 (E), Q13.2 (E), R38.2
unnamed: F8.1, Q14.2 (E), Q15.2 (E), R57.2
unnamed: F9.1, Q16.2 (E), Q17.2 (E), R58.2
unnamed: F10.1, Q18.2 (E), Q19.2 (E), R59.2
unnamed: F11.1, Q20.2 (E), Q21.2 (E), R60.2
unnamed: F12.1, Q24.2 (E), Q25.2 (E), R64.2
unnamed: F13.2, R73.1
unnamed: F14.2, R74.1
unnamed: F15.1, Q30.2 (E), Q31.2 (E), R82.2
unnamed: Q6.1 (B), Q7.1 (B), R31.1, R35.1, U9.4
unnamed: Q8.1 (B), Q9.1 (B), R32.1, R36.1, U10.4
unnamed: Q10.1 (B), Q11.1 (B), R33.1, R37.1, U11.4
unnamed: Q12.1 (B), Q13.1 (B), R34.1, R38.1, U12.4
unnamed: Q14.1 (B), Q15.1 (B), R53.1, R57.1, U13.4
unnamed: Q16.1 (B), Q17.1 (B), R54.1, R58.1, U14.4
unnamed: Q18.1 (B), Q19.1 (B), R55.1, R59.1, U15.4
unnamed: Q20.1 (B), Q21.1 (B), R56.1, R60.1, U16.4
unnamed: Q24.1 (B), Q25.1 (B), R63.1, R64.1, U17.1
unnamed: Q26.1 (G), R67.1
unnamed: Q26.3 (D), R69.1
unnamed: Q27.1 (G), R68.1
unnamed: Q27.3 (D), R70.1
unnamed: Q28.2 (D), R73.4
unnamed: Q29.2 (D), R74.4
unnamed: Q30.1 (B), Q31.1 (B), R79.1, R82.1, U20.1
unnamed: R17.1, R18.1, U9.3 (+)
unnamed: R19.1, R20.1, U10.3 (+)
unnamed: R21.1, U11.3 (+)
unnamed: R22.1, U12.3 (+)
unnamed: R23.1, R24.2, U9.1 (-)
unnamed: R25.1, R26.2, U10.1 (-)
unnamed: R27.1, R28.2, U11.1 (-)
unnamed: R29.1, R30.2, U12.1 (-)
unnamed: R39.1, R40.1, U13.3 (+)
unnamed: R41.1, R42.1, U14.3 (+)
unnamed: R43.1, U15.3 (+)
unnamed: R44.1, U16.3 (+)
unnamed: R45.1, R46.2, U13.1 (-)
unnamed: R47.1, R48.2, U14.1 (-)
unnamed: R49.1, R50.2, U15.1 (-)
unnamed: R51.1, R52.2, U16.1 (-)
unnamed: R61.1, U17.3 (+)
unnamed: R62.2, R63.2, U17.4 (-)
unnamed: R71.1, R73.3
unnamed: R72.1, R74.3
unnamed: R73.2, R75.1
unnamed: R74.2, R76.1
unnamed: R77.1, U20.3 (+)
unnamed: R78.2, R79.2, U20.4 (-)
unnamed: R80.2, TP5.1, U18.5
unnamed: R81.2, TP6.1, U19.5
OUT_ANALOG1: F12.2; also elsewhere on the board
OUT_ANALOG2: F15.2; also elsewhere on the board
OUT_PP_DRV1: F4.2; also elsewhere on the board
OUT_PP_DRV2: F8.2; also elsewhere on the board
OUT_PP_DRV3: F5.2; also elsewhere on the board
OUT_PP_DRV4: F9.2; also elsewhere on the board
OUT_PP_DRV5: F6.2; also elsewhere on the board
OUT_PP_DRV6: F10.2; also elsewhere on the board
OUT_PP_DRV7: F7.2; also elsewhere on the board
OUT_PP_DRV8: F11.2; also elsewhere on the board
TIM1_CH1: R18.2; also elsewhere on the board
TIM1_CH2: R40.2; also elsewhere on the board
TIM1_CH3: R20.2; also elsewhere on the board
TIM1_CH4: R42.2; also elsewhere on the board

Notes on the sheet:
Vout = I * 50mOhm * 20 = 2,5V @ 2,5A
12V SWITCHED SUPPLY 2
fg = 100Hz
ANALOG OUTPUT
12V SWITCHED SUPPLY 1
PUSH-PULL OUTPUT DRIVER

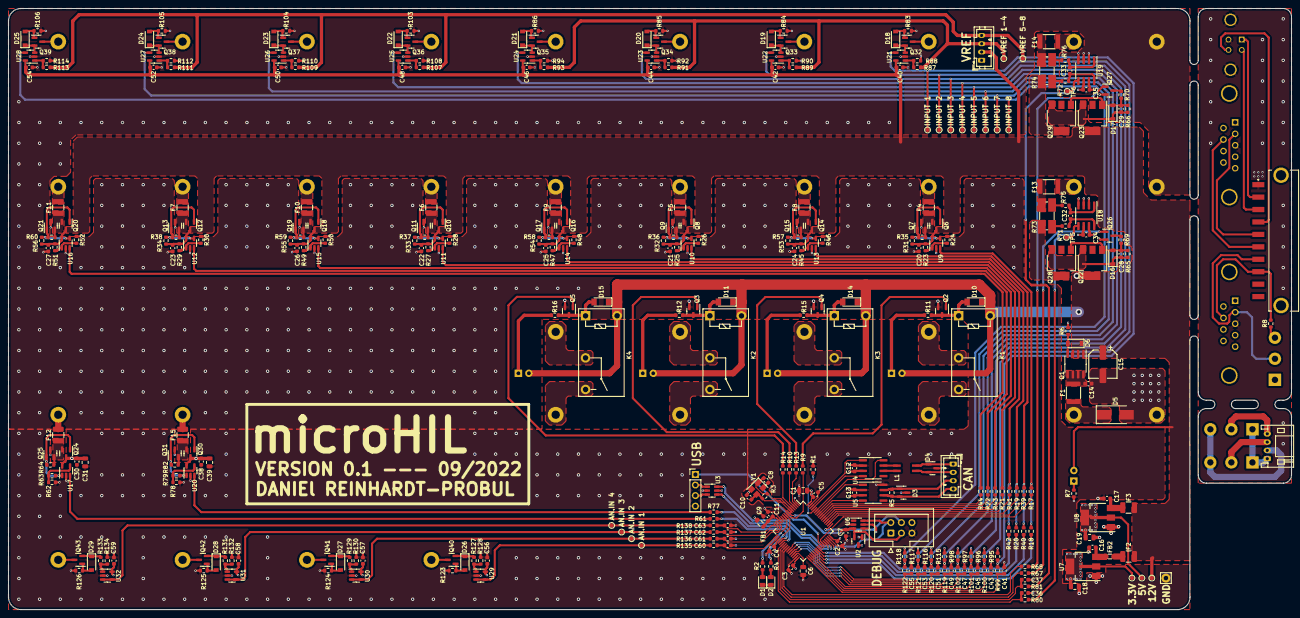
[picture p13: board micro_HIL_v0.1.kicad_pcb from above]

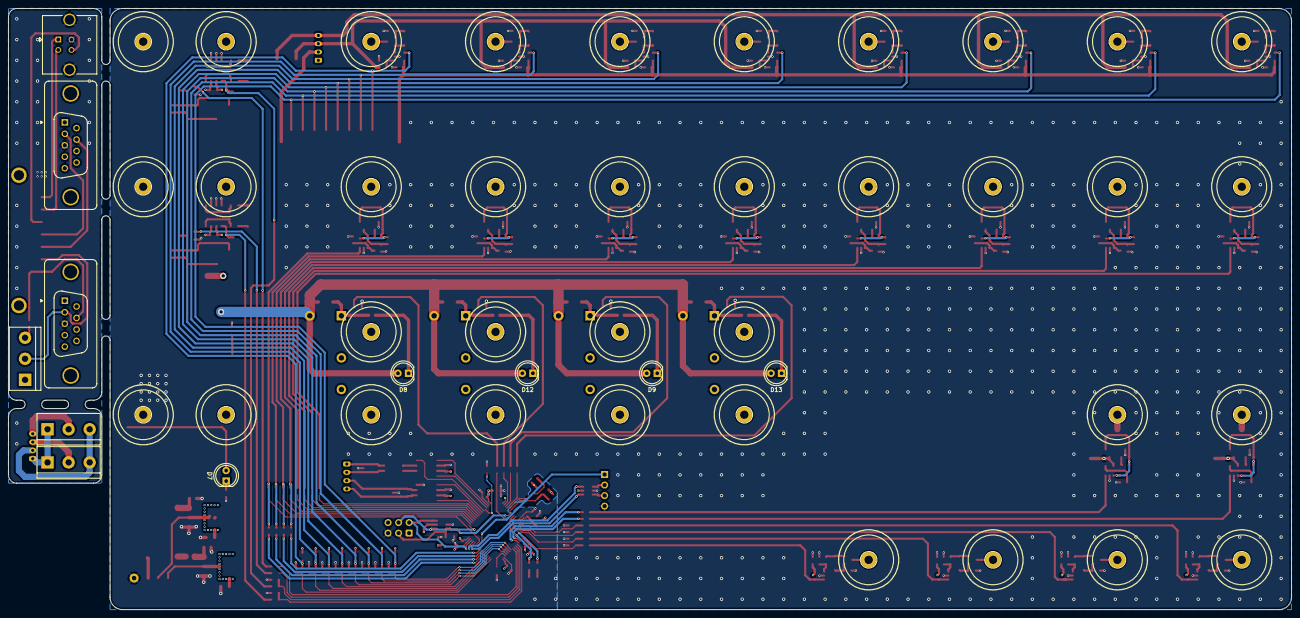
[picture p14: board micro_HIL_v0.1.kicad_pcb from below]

Board: 4 copper layers, 309.5 x 145.0 mm, 396 parts (47 on the bottom side), 242 nets.

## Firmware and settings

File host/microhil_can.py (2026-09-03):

"""CAN1 des microHIL als CAN-USB-Interface (SLCAN) ansprechen.

Duenner Wrapper um python-can: findet den richtigen der beiden COM-Ports und
umgeht die S7-Mehrdeutigkeit der SLCAN-Bitratentabelle.

    from microhil_can import open_can

    with open_can(500000) as bus:
        bus.send(can.Message(arbitration_id=0x7DF, data=[0x02, 0x01, 0x00]))
        print(bus.recv(1.0))

Als Sniffer direkt aufrufbar:

    python microhil_can.py 500000
"""
import sys

import can
import serial

from microhil import find_can_port

# python-can bildet 750000 auf 'S7' ab, das originale Lawicel-CAN232 (und
# damit die microHIL-Firmware) versteht unter 'S7' aber 800 kbit/s. Fuer diese
# beiden Raten -- und fuer alles, was gar nicht in der Tabelle steht -- setzen
# wir die Bitrate vorab selbst per 'B<bit/s>'-Zusatzkommando und lassen
# python-can den Bus nur noch oeffnen. Siehe docs/can-usb.md.
_SLCAN_SAFE_BITRATES = {10000, 20000, 50000, 100000, 125000,
                        250000, 500000, 1000000}


def set_bitrate_raw(port: str, bitrate: int, timeout: float = 1.0) -> None:
    """Bitrate ueber das B-Kommando setzen, ohne python-cans Tabelle.

    Der Bus wird dabei geschlossen -- das Setzen der Bitrate ist bei
    geschlossenem Bus sowieso Pflicht.
    """
    with serial.Serial(port, baudrate=115200, timeout=timeout) as ser:
        ser.write(b"C\r")
        ser.read(1)
        ser.reset_input_buffer()
        ser.write(f"B{bitrate}\r".encode("ascii"))
        reply = ser.read(1)
        if reply != b"\r":
            raise RuntimeError(
                f"microHIL hat die Bitrate {bitrate} abgelehnt "
                f"(Antwort {reply!r}). Zulaessig sind 5000..1000000 bit/s, "
                "sofern bei 36 MHz auf 0,1 % genau erreichbar."
            )


def open_can(bitrate: int = 500000, port: str | None = None,
             listen_only: bool = False, **kwargs) -> can.BusABC:
    """CAN1 oeffnen und einen python-can-Bus zurueckgeben."""
    port = port or find_can_port()

    if bitrate in _SLCAN_SAFE_BITRATES:
        return can.Bus(interface="slcan", channel=port, bitrate=bitrate,
                       listen_only=listen_only, **kwargs)

    set_bitrate_raw(port, bitrate)
    return can.Bus(interface="slcan", channel=port,
                   listen_only=listen_only, **kwargs)


def _main(argv: list[str]) -> int:
    bitrate = int(argv[1]) if len(argv) > 1 else 500000
    port = find_can_port()
    print(f"microHIL CAN1 auf {port}, {bitrate} bit/s -- Abbruch mit Strg-C")

    with open_can(bitrate, port=port) as bus:
        try:
            for msg in bus:
                print(msg)
        except KeyboardInterrupt:
            pass
    return 0


if __name__ == "__main__":
    sys.exit(_main(sys.argv))

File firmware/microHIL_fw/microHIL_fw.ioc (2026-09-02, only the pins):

Mcu.UserName=STM32F446RETx
PA0-WKUP.GPIO_Label=AIN_AN2
PA0-WKUP.Signal=ADCx_IN0
PA1.GPIO_Label=AIN_AN3
PA1.Signal=ADCx_IN1
PA10.GPIO_Label=DOUT_OUT1
PA10.Signal=GPIO_Output
PA11.Signal=USB_OTG_FS_DM
PA12.Signal=USB_OTG_FS_DP
PA13.Signal=SYS_JTMS-SWDIO
PA14.Signal=SYS_JTCK-SWCLK
PA15.GPIO_Label=DOUT_OUT2
PA15.Signal=GPIO_Output
PA2.GPIO_Label=AIN_AN4
PA2.Signal=ADCx_IN2
PA3.GPIO_Label=AIN_AN1
PA3.Signal=ADCx_IN3
PA4.GPIO_Label=AOUT_AN2
PA4.Signal=COMP_DAC1_group
PA5.GPIO_Label=AOUT_AN1
PA5.Signal=COMP_DAC2_group
PA6.GPIO_Label=AIN_12VOUT1_CURRSENSE
PA6.Signal=ADCx_IN6
PA7.GPIO_Label=AIN_12VOUT2_CURRSENSE
PA7.Signal=ADCx_IN7
PB0.GPIO_Label=DIN_IN8
PB0.Signal=GPIO_Input
PB1.GPIO_Label=DIN_IN7
PB1.Signal=GPIO_Input
PB10.GPIO_Label=DIN_IN5
PB10.Signal=GPIO_Input
PB12.GPIO_Label=DIN_IN1
PB12.Signal=GPIO_Input
PB13.GPIO_Label=DIN_IN2
PB13.Signal=GPIO_Input
PB14.GPIO_Label=DIN_IN3
PB14.Signal=GPIO_Input
PB15.GPIO_Label=DIN_IN4
PB15.Signal=GPIO_Input
PB2.GPIO_Label=DIN_IN6
PB2.Signal=GPIO_Input
PB3.GPIO_Label=DOUT_OUT7
PB3.Signal=GPIO_Output
PB4.GPIO_Label=DOUT_OUT8
PB4.Signal=GPIO_Output
PB5.Signal=CAN2_RX
PB6.Signal=CAN2_TX
PB7.GPIO_Label=CAN1_SILENT
PB7.Signal=GPIO_Output
PB8.Signal=CAN1_RX
PB9.Signal=CAN1_TX
PC0.GPIO_Label=DOUT_RELAY1
PC0.Signal=GPIO_Output
PC1.GPIO_Label=DEBUG_LED_1
PC1.Signal=GPIO_Output
PC10.GPIO_Label=DOUT_OUT3
PC10.Signal=GPIO_Output
PC11.GPIO_Label=DOUT_OUT4
PC11.Signal=GPIO_Output
PC12.GPIO_Label=DOUT_OUT5
PC12.Signal=GPIO_Output
PC13.GPIO_Label=DOUT_RELAY2
PC13.Signal=GPIO_Output
PC14-OSC32_IN.GPIO_Label=DOUT_RELAY3
PC14-OSC32_IN.Signal=GPIO_Output
PC15-OSC32_OUT.GPIO_Label=DOUT_RELAY4
PC15-OSC32_OUT.Signal=GPIO_Output
PC2.GPIO_Label=DEBUG_LED_2
PC2.Signal=GPIO_Output
PC4.GPIO_Label=DOUT_12VOUT1
PC4.Signal=GPIO_Output
PC5.GPIO_Label=DOUT_12VOUT2
PC5.Signal=GPIO_Output
PC6.Signal=S_TIM3_CH1
PC7.Signal=S_TIM3_CH2
PC8.Signal=S_TIM3_CH3
PC9.Signal=S_TIM3_CH4
PD2.GPIO_Label=DOUT_OUT6
PD2.Signal=GPIO_Output
PH0-OSC_IN.Signal=RCC_OSC_IN
PH1-OSC_OUT.Signal=RCC_OSC_OUT

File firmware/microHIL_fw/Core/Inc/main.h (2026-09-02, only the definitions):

#define DOUT_RELAY2_Pin GPIO_PIN_13
#define DOUT_RELAY2_GPIO_Port GPIOC
#define DOUT_RELAY3_Pin GPIO_PIN_14
#define DOUT_RELAY3_GPIO_Port GPIOC
#define DOUT_RELAY4_Pin GPIO_PIN_15
#define DOUT_RELAY4_GPIO_Port GPIOC
#define DOUT_RELAY1_Pin GPIO_PIN_0
#define DOUT_RELAY1_GPIO_Port GPIOC
#define DEBUG_LED_1_Pin GPIO_PIN_1
#define DEBUG_LED_1_GPIO_Port GPIOC
#define DEBUG_LED_2_Pin GPIO_PIN_2
#define DEBUG_LED_2_GPIO_Port GPIOC
#define AIN_AN2_Pin GPIO_PIN_0
#define AIN_AN2_GPIO_Port GPIOA
#define AIN_AN3_Pin GPIO_PIN_1
#define AIN_AN3_GPIO_Port GPIOA
#define AIN_AN4_Pin GPIO_PIN_2
#define AIN_AN4_GPIO_Port GPIOA
#define AIN_AN1_Pin GPIO_PIN_3
#define AIN_AN1_GPIO_Port GPIOA
#define AOUT_AN2_Pin GPIO_PIN_4
#define AOUT_AN2_GPIO_Port GPIOA
#define AOUT_AN1_Pin GPIO_PIN_5
#define AOUT_AN1_GPIO_Port GPIOA
#define AIN_12VOUT1_CURRSENSE_Pin GPIO_PIN_6
#define AIN_12VOUT1_CURRSENSE_GPIO_Port GPIOA
#define AIN_12VOUT2_CURRSENSE_Pin GPIO_PIN_7
#define AIN_12VOUT2_CURRSENSE_GPIO_Port GPIOA
#define DOUT_12VOUT1_Pin GPIO_PIN_4
#define DOUT_12VOUT1_GPIO_Port GPIOC
#define DOUT_12VOUT2_Pin GPIO_PIN_5
#define DOUT_12VOUT2_GPIO_Port GPIOC
#define DIN_IN8_Pin GPIO_PIN_0
#define DIN_IN8_GPIO_Port GPIOB
#define DIN_IN7_Pin GPIO_PIN_1
#define DIN_IN7_GPIO_Port GPIOB
#define DIN_IN6_Pin GPIO_PIN_2
#define DIN_IN6_GPIO_Port GPIOB
#define DIN_IN5_Pin GPIO_PIN_10
#define DIN_IN5_GPIO_Port GPIOB
#define DIN_IN1_Pin GPIO_PIN_12
#define DIN_IN1_GPIO_Port GPIOB
#define DIN_IN2_Pin GPIO_PIN_13
#define DIN_IN2_GPIO_Port GPIOB
#define DIN_IN3_Pin GPIO_PIN_14
#define DIN_IN3_GPIO_Port GPIOB
#define DIN_IN4_Pin GPIO_PIN_15
#define DIN_IN4_GPIO_Port GPIOB
#define DOUT_OUT1_Pin GPIO_PIN_10
#define DOUT_OUT1_GPIO_Port GPIOA
#define DOUT_OUT2_Pin GPIO_PIN_15
#define DOUT_OUT2_GPIO_Port GPIOA
#define DOUT_OUT3_Pin GPIO_PIN_10
#define DOUT_OUT3_GPIO_Port GPIOC
#define DOUT_OUT4_Pin GPIO_PIN_11
#define DOUT_OUT4_GPIO_Port GPIOC
#define DOUT_OUT5_Pin GPIO_PIN_12
#define DOUT_OUT5_GPIO_Port GPIOC
#define DOUT_OUT6_Pin GPIO_PIN_2
#define DOUT_OUT6_GPIO_Port GPIOD
#define DOUT_OUT7_Pin GPIO_PIN_3
#define DOUT_OUT7_GPIO_Port GPIOB
#define DOUT_OUT8_Pin GPIO_PIN_4
#define DOUT_OUT8_GPIO_Port GPIOB
#define CAN1_SILENT_Pin GPIO_PIN_7
#define CAN1_SILENT_GPIO_Port GPIOB

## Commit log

2026-09-02 Add STM32CubeMX firmware project (microHIL_fw)
    STM32F446RET, CMake toolchain, USB OTG FS device with CDC class.
    Pinout: 4 relays, 8 digital in/out each, 4 analog in, 2 analog out (DAC),
    2 switchable 12V outputs with current sense, CAN1/CAN2 reserved.
2026-09-02 Bring up USB CDC communication and add microHIL command protocol
    Fix VBUS sensing, a broken clock tree, and a swapped AOUT pin
    assignment that together blocked USB enumeration; add a text-based
    command protocol for relays/DIO/AIO/12V outputs with a Python client
    and a PySide6 test GUI, all verified against the real board.
    [gui.py, main.h, microHIL_fw.ioc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]
2026-09-03 Add PWM1-4 channels with OUT1-4 interlock
    PWM1-4 on PC6-PC9 (TIM3 CH1-4), duty cycle in per mille via the PWM/PWM?
    commands. PWM1-4 and OUT1-4 drive the same output stage per schematic, so
    the firmware forces the other channel off whenever one is activated.
    Not yet verified on hardware (ST-Link was disconnected).
2026-09-03 Add SLCAN CAN-USB interface on CAN1
    Implements CAN1 as a Lawicel/CAN232-compatible USB-CAN adapter so it works
    with python-can (interface="slcan") on Windows and with slcand as SocketCAN
    on Linux.
    can_if.c wraps bxCAN: runtime bit timing, accept-all filter, interrupt-driven
    RX into a 64-frame ring (the hardware FIFO is only 3 deep), auto bus-off
    recovery and the SLCAN error flags. Bit timing is configured at runtime rather
    than in CubeMX because SLCAN changes the bitrate per command and generated
    values would be lost on every .ioc regeneration. The CAN1/CAN2 filter bank
    split is set so CAN2 can receive later.
    slcan.c implements the ASCII protocol with a buffered, non-blocking output
    path -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
    [can_if.c]
2026-09-03 Expose CAN1 and the HIL protocol as two separate virtual COM ports
    Turns the device into a composite USB device with two CDC-ACM functions so
    the test GUI and a CAN tool can be used at the same time -- a single COM port
    can only be opened once on Windows.
    Uses the composite builder from the ST USB Device Library, added from the
    matching Cube FW package (F4 V1.28.3) because CubeMX does not generate a
    composite device for the F4 series. USE_USBD_COMPOSITE lives in usbd_conf.h
    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
2026-09-03 Add host-side CAN support, docs and hardware-free checks
    microhil_can.py wraps python-can and works around the S7 ambiguity: python-can
    maps 750 kbit/s to S7 while Lawicel CAN232 (and this firmware) reads S7 as
    800 kbit/s, so bitrates outside the unambiguous set are set via the B command
    instead.
    find_ports() tells the two composite COM ports apart. The interface number
    appears in different places depending on platform and pyserial version, so it
    is parsed from MI_xx, -ifxx and LOCATION= in turn -- with a natural-sort
    fallback when none is present, which also fixes the GUI defaulting to the CAN
    port instead of the control port.
    The GUI grows a CAN1 tab (bitrate, listen-only, trace, send) n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
    [check_bit_timing.py, check_slcan_wire.py, gui.py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]
2026-09-03 Guard B command against overflow, document CAN1/CAN2 filter coupling
    A very long digit string after B could wrap the 32-bit accumulator and land
    inside the valid range, silently selecting a bitrate the caller never asked
    for. Bail out as soon as the value exceeds the maximum instead.
    Also records a trap for the upcoming CAN2 work: HAL_CAN_DeInit on the master
    instance ends with CAN_MCR_RESET, and the filter block belongs to CAN1, so
    every CAN1 open wipes CAN2's filters as well.
2026-09-04 Fix composite device enumeration: device descriptor still declared plain CDC
    Hardware test on real microHIL: after flashing, only one COM port ever
    enumerated (the interim single-port behavior), even though the composite
    descriptors, FIFO layout, and second CDC instance were all in place.
    The cause was the USB device descriptor's bDeviceClass/SubClass/Protocol,
    still 0x02/0x02/0x00 (CDC ACM directly on the device) from the original
    single-function firmware. Windows only hands a device to the generic
    composite parent driver (usbccgp, which splits it into per-function &MI_xx
    nodes) when the device descriptor advertises the "Multi-Interface Function"
    class 0xEF/0x02/0x01. With the old value, W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
2026-09-04 Document CAN1_RX floating finding from hardware bring-up
    Hardware test: SLCAN's protocol layer works correctly, but bringing the bus
    up (O/L, and even the loopback self-test Y which needs no external bus)
    always fails. Attached a debugger and traced it to HAL_CAN_Start() timing out
    in HAL_CAN_ERROR_TIMEOUT -- INAK never clears because the bxCAN core waits
    for 11 consecutive recessive bits on the physical RX pin before leaving init
    mode, and that wait applies even in loopback mode since it watches the real
    pin rather than the internal loopback path.
    Confirmed PB8 is floating rather than actively driven: switching in an
    internal pull-up flips it high immediately, which a real transceiver's ou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
2026-09-04 Close protocol.md gaps found while assessing it for a LabControl driver
    Diffed the doc against the actual protocol.c parsing/reply code to find
    everything a driver author working blind from the doc (no firmware source,
    no hardware) would trip over -- following the same style already used in
    labor-dashboard's hcs34xx/driver.py and can_bus/driver.py (VID/PID-based
    discover(), exception hierarchy distinguishing rejected values from dead
    connections, docstring notes on quirks verified against real hardware).
    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
2026-09-04 CAN1 works: root cause was a defective transceiver
    Retested twice after hardware fixes attempted in between. Resoldering the
    CAN1 pins (ruling out cold joints) made no difference -- O/L/Y all still
    failed identically, and PB8 still read as floating under the pull-up test
    from the first diagnosis.
    Direct measurement at the transceiver's RXD pin found ~0.2V instead of the
    expected ~5V recessive idle level -- the transceiver itself wasn't driving
    the line, regardless of MCU-side configuration or PCB wiring. Replacing it
    fixed the bus: O/L/Y all open cleanly now, loopback round-trips correctly
    for standard, extended, and both RTR frame variants at 1 Mbit/s with no
    error flags, and the HIL proto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
2026-09-08 Fix floating digital inputs; commit pending calibration/PWR12/CAN work
    Digital inputs (DIN_IN1-8) always read High when unconnected because an
    external 10k pull-up dominated the much weaker (~40k) internal STM32
    pull-down. Removed the external pull-up on all digital inputs and enabled
    GPIO_PULLDOWN in both main.c and the CubeMX .ioc so regeneration won't
    revert it. Not yet verified on hardware.
    Also folds in prior uncommitted work: real 2-point calibration for
    AIN/AOUT/CURR channels, PWR12-1 hardware repairs (Q22/Q28, U18/U19) and
    firmware-side overcurrent guarding for PWR12, a board-unique serial number
    in *IDN?, and protocol.md/gui/host-driver updates that go with these.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
    [gui.py, microHIL_fw.ioc, microhil.py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]
2026-09-08 Add current limiting for the 12 V outputs, close out the DIN defect
    Firmware-side protection for PWR12-1/2 (pwr12_guard_poll): a per-channel
    limit configurable via ILIM/ILIM? (default 1200 mA) that trips after 100 ms,
    plus a combined 1500 mA budget for the shared polyfuse F1. Both latch until
    the offending request is withdrawn with PWR12 <n> 0; PWR12FLT? reports the
    cause. Verified on hardware with an electronic load.
    The budget path needed a 10 ms debounce of its own: switching a single
    unloaded channel on produced a MOSFET turn-on glitch that hit the unfiltered
    2 ms ADC sample and tripped the interlock immediately.
    docs/protocol.md also drops the stale note that DIN channels 3-8 read a
    f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
    [microHIL_fw.ioc, protocol.c]
2026-09-08 Prepare for public release: English README, MIT license, KiCad sources
    Rewrite the README in English for a public audience: feature table, USB
    interface layout, protocol summary, host quickstart, firmware build and
    flash instructions, and an honest status section pointing at the rev v0.1
    board quirks documented in docs/hardware-notes.md. The docs/ tree stays
    German for now, which the README says.
    Add the KiCad 9 schematic, PCB, Gerbers and the ordered fabrication archives
    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
    [Connectors.kicad_sch, Input-Driver.kicad_sch, Input-Output.kicad_sch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]
2026-09-09 Fix AOUT/AIN nonlinearity near zero with piecewise calibration
    AOUT1-2/AIN1-4 showed a real, non-extrapolation nonlinearity below their
    previously measured calibration point (e.g. AOUT 1 1000 gave 906mV real
    instead of ~1000mV, AIN? 1 read 687mV instead of the actual 909mV present).
    Replace the rigid 2-point calibration (cal_point_t, Cal_Apply) with
    piecewise linear interpolation over multiple measured points (cal_curve_t,
    Cal_Apply/Cal_Invert), and add the additional measured points for all four
    AIN channels and both AOUT channels.
    Verified on hardware: AOUT 1 1000 -> 982mV real / AIN? 1 984mV (was 687mV),
    AOUT 2 1000 -> 978mV real / AIN? 2 973mV (was 678mV), AIN? 3 981mV (real
    981mV), AIN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
    [protocol.c]
2026-09-09 Fix linker scripts for GCC 10.3.1 to unblock command-line builds
    All three .ld files used the (READONLY) section attribute on
    .ARM.extab/.ARM/.preinit_array/.init_array/.fini_array, which only GCC 11+
    understands (documented in each file's own comment) -- linking with GCC
    10.3.1 (the version bundled with STM32CubeIDE 1.10.1) failed with "non
    constant or forward reference address expression for section .ARM.extab".
    Removed the attribute so `cmake --preset Release && cmake --build --preset
    Release` builds cleanly. Documented the toolchain/GCC-version gotcha in
    README.md.

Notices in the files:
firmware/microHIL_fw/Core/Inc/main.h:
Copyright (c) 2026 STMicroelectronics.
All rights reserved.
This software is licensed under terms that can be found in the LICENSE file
